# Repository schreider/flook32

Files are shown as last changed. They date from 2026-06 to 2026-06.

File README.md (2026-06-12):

<p align="center">
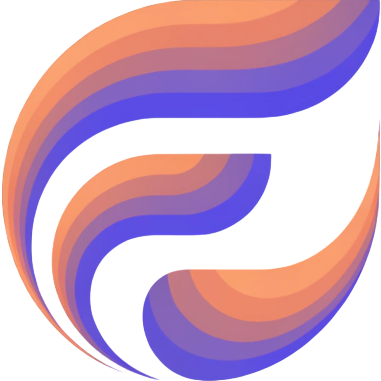
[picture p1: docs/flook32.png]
FLOOK32 logo
  
</p>

<p align="center">
  <a href="https://github.com/schreider/flook32/releases">
    
  </a>
  <br>
  <a href="https://www.espressif.com/en/products/socs/esp32">
    
  </a>
  <a href="https://github.com/schreider/flook32/blob/main/LICENSE">
    
  </a>
  <a href="https://t.me/flook32">
    
  <br>
  </a>
</p>

# FLOOK32 — контроллер нагрева камеры 3D-принтера

Автономный контроллер с возможностью мягкой интеграции в Klipper на базе ESP32 с веб-интерфейсом. Управляет нагревом камеры, вентилятором обдува, следит за температурой и защищает от перегрева.

[Telegram-чат проекта](https://t.me/flook32)

> ⚠️ **БЕТА-версия 0.1.0.** Проект активно дорабатывается. Прошивка протестирована на одной среде — возможны баги. Если нашли проблему — создайте [Issue](https://github.com/schreider/flook32/issues/new) или напишите в [Telegram](https://t.me/flook32)
>
> **ВНИМАНИЕ:** Устройство работает с напряжением 220В. Неправильная сборка может привести к пожару или поражению током. Автор не несёт ответственности за любой ущерб.

---

<p align="center">
  
  
  
  
  
</p>

## 📋 Быстрая навигация

| Раздел | Описание |
|---|---|
| [Зачем это нужно](#зачем-это-нужно) | Мотивация и философия проекта |
| [Гибкость настроек](#гибкость-настроек) | Полный контроль без кода |
| [Возможности](#возможности) | Прошивка, железо, печатные детали |
| [Поддержать автора](#-поддержать-автора) | Донаты на развитие проекта |
| [Лицензия](#лицензия) | GPLv3 License |
| [Атрибуция](#-атрибуция-сторонних-библиотек) | Используемые сторонние библиотеки |

### 📖 Документация

| Документ | Содержание |
|---|---|
| [BUILD.md](docs/BUILD.md) | 🛠️ Инструкция по сборке устройства |
| [SETUP.md](docs/SETUP.md) | 📥 Прошивка и первый запуск |
| [FIRMWARE.md](docs/FIRMWARE.md) | ⚙️ Документация по прошивке ESP32 |
| [ESP01S_FIRMWARE.md](firmware/esp01s_watchdog/ESP01S_FIRMWARE.md) | 🐶 Прошивка ESP-01S (watchdog) |
| [WEBUI.md](docs/WEBUI.md) | 🌐 Работа с веб-интерфейсом |
| [WIRING.md](docs/WIRING.md) | 🔌 Схема подключения |
| [BOM.md](docs/BOM.md) | 📦 Список компонентов |
| [KLIPPER.md](docs/KLIPPER.md) | 🖨️ Интеграция с Klipper/Moonraker |
| [FAQ.md](docs/FAQ.md) | ❓ Частые вопросы |
| [WARNING.md](docs/WARNING.md) | ⚠️ Предупреждение о безопасности |

### 🗂️ Структура репозитория

| Папка | Содержание |
|---|---|
| [`firmware/flook32/`](firmware/flook32/) | Прошивка ESP32 |
| [`firmware/esp01s/`](firmware/esp01s_watchdog/) | Прошивка ESP-01S (watchdog) |
| [`klipper/`](klipper/) | Плагин для Klipper |
| [`hardware/enclosure/`](hardware/enclosure/) | 3MF, STEP, F3D файлы корпусов |
| [`tools/`](tools/) | Вспомогательные скрипты |
| [`docs/`](docs/) | Документация |

---

## Зачем это нужно

Большинство 3D-принтеров на рынке не имеют нагрева камеры в принципе. А проприетарные платы производителей чаще всего либо не имеют возможности подключения нагревателя, либо не имеют выходов под датчики, необходимые для нормальной защиты нагревателя.

В интернете есть похожие проекты, но у каждого — свой недостаток:
- Нет нужного функционала защит (просто вкл/выкл по температуре воздуха в камере)
- Построены на проприетарных платах — нельзя модифицировать или починить без сложной пайки
- Требуют глубокого вмешательства в Klipper для интеграции
- Подключаются как второе MCU с вытекающими проблемами

Поэтому я создал проект под собственные требования:
- **Удобство** — всё управляется из браузера с телефона или ПК
- **Безопасность** — 7+ уровней защиты, аппаратный watchdog, двойное реле на нагревателе
- **Модульность** — все компоненты куплены на маркетплейсах, любой заменяется без пайки за минуты
- **Универсальность** — установка в ЛЮБОЙ принтер, даже без Klipper
- **Автономность** — самостоятельный блок, который не зависит от прошивки принтера. Работает без Klipper, без USB, без интернета — просто включил в розетку, настроил через Wi-Fi и забыл
- **Широкий диапазон** — поддержка любых нагревателей с измерением температуры от 0 до 600°C

### Интеграция без привязки к принтеру

Модуль `flook32.py` делает интеграцию с Klipper тривиальной — скопировали плагин, добавили три строки в `printer.cfg`, и всё работает. Сменили принтер на новый — перенесли внутренний и внешний блоки, нагреватель камеры снова в строю.

Более того — **Klipper не обязателен**. Контроллер полностью автономен: открыли веб-интерфейс, выставили температуру, нагрев пошёл.

### Защита на стороне контроллера, а не принтера

Все защиты реализованы исключительно на стороне FLOOK32. Klipper **никогда не упадёт в ошибку** из-за проблем с нагревом камеры и **не прервёт печать**.

А FLOOK32 в это время сам пытается восстановить систему. Сработала защита? Контроллер подождёт, проверит, и если ошибка ушла — продолжит нагрев. И только если ситуация не исправляется — отключит нагрев с полной блокировкой и будет ждать действий оператора. Вы спокойно допечатаете модель, даже если нагреватель временно отключился по защите.

[🔝 Наверх](#-быстрая-навигация)

---

## Гибкость настроек

FLOOK32 не пытается угадать, какой у вас принтер, камера, вентилятор или нагреватель. Он даёт вам **полный контроль** над всем — и делает это через удобный веб-интерфейс, без единой строчки кода.

### Всё настраивается «на лету»

- **Пины** — можно назначить любые GPIO под SSR, вентилятор, датчики. Поменяли номера пинов в вебморде — и всё работает.
- **Логика сигналов** — если ваше реле включается низким уровнем, а не высоким, просто включите инверсию нагревателя (и вентилятора) в одно нажатие.
- **Температурные пороги** — максимальная температура нагревателя, критический перегрев, гистерезисы, максимальная температура воздуха в камере — всё задаётся под ваше железо и ваши требования к безопасности.
- **Вентилятор** — настраивается порог включения, минимальное время работы, максимальная мощность ШИМ.

### Автоматическая адаптация (но можно и вручную)

Чтобы не гадать с порогами защит и работой вентилятора, запустите адаптацию. Контроллер сам:
- измерит реальную скорость нагрева вашего нагревателя и камеры,
- определит уровень шумов датчиков,
- подберёт эффективную мощность вентилятора и температуру его включения,
- выставит оптимальные пороги для Thermal Runaway и других защит.

Но если вы любите точную ручную настройку — все параметры доступны для редактирования, и адаптация не обязательна.

### Система защит настраивается под ваш принтер

- **Thermal Runaway**: можно задать длительность фаз, минимальные скорости роста температуры, время восстановления после срабатывания.
- **Неожиданный нагрев**: настраивается порог, таймаут ожидания остывания, гистерезис.
- **Блокировка**: сколько одинаковых ошибок нужно, чтобы система заблокировалась, и в течение какого окна.
- **Термальная модель**: включается по желанию, имеет регулируемую чувствительность, и сама учится на поведении вашего принтера.

### Никакой «магии» — всё прозрачно

Все текущие настройки в любой момент можно посмотреть в браузере, а новые сохраняются в энергонезависимую память.

FLOOK32 не навязывает единственно верное поведение — он **настраивается под вас**.

[🔝 Наверх](#-быстрая-навигация)

---

## Возможности

### Прошивка

- **Самообучаемая термальная модель** — предсказывает температуру и находит аномалии
- **Автоадаптация** — сам подбирает параметры под конкретный принтер
- **7+ уровней защиты** с трёхступенчатой эскалацией
- **Веб-интерфейс** с графиком в реальном времени ([подробнее](docs/WEBUI.md))
- **Интеграция с Klipper и Moonraker** — UDP-обнаружение, автоотключение после печати
- **WebSocket + REST API** (32 эндпоинта) ([подробнее](docs/FIRMWARE.md))
- **OTA-обновление** — три способа: ручная загрузка `.bin`, автообновление через GitHub

### Железо

- Управление нагревателем через SSR
- ШИМ-управление вентилятором (17 кГц, ультразвук)
- MAX6675 + термопара K-типа и DS18B20
- Аппаратный watchdog на ESP01S
- LED-индикация (10 режимов + анимации) ([подробнее](docs/FIRMWARE.md))
- Звуковая индикация (3 мелодии) ([подробнее](docs/FIRMWARE.md))

### 🖨️ Печатные детали

> ℹ️ **Гибкость монтажа** — предоставленные модели корпусов — **не обязательны**. Вы можете:
> - Разместить всю электронику в отсеке электроники вашего принтера (если позволяет место)
> - Использовать собственные корпуса (своей разработки или с Printables/Thingiverse)
> - Модуль нагревателя — любой доступный в открытых источниках, под любой формат и мощность
> - Вентилятор — 5/12/24В в зависимости от места установки и потребностей (можно использовать БП принтера)
>
> Цель проекта — дать **полный контроль**, а не навязывать единственное решение.

#### Внешний блок (основной контроллер)

- **Два изолированных отсека** — низковольтный (5В/12В) и высоковольтный (220В)
- **Поддержка двух типов SSR** — G3MB-202P или SSR-10DA
- **Доступ к ESP32** — Type-C, BOOT, EN снаружи
- **Кабельный ввод под гофру**
- **4 винта** — вскрывается за минуту
- **Магнитное крепление** — сзади

#### Внутренний блок (в камеру принтера)

- **Узкая конструкция** — не мешает механике
- **PTC нагреватель 150Вт**
- **Магнитное крепление** — сверху
- **Встроенный коннектор XH 2.54** — замена вентилятора за минуту
- **Подсветка логотипа**
- **Кабельный ввод под гофру**

[🔝 Наверх](#-быстрая-навигация)

---

## 💖 Поддержать автора

Если проект оказался полезным, вы можете поддержать разработку:

| Платформа | Адрес |
|---|---|
| [DonationAlerts](https://dalink.to/schreid) | RUB, карты, СБП |
| **BTC** (Bitcoin) | `19zn9549pTmBEDFddg7uUS8iiwPJVgAUC1` |
| **USDT** (TRC20) | `TPhKy6vCPUGbmDUak1QhCgY5bEsSczLhmK` |
| **ETH** (Ethereum) | `0xeFDa4681B0eFfBE1f43c9c59A47D1Bbe8aEA5f44` |
| **TON** | `UQA9LVMtu6e4sMJ8cLHaVvGIj1CvFL2vdDTk_blglwtII6Zf` |

> 💡 Все донаты идут на закупку компонентов для тестирования, новые платы, содержание проекта, добавление новых функций, разработку LITE-версии FLOOK32 и сушилки филамента.

### 🛒 Готовые комплекты

Я продаю готовые комплекты FLOOK32 — прошитые и проверенные. Вам останется только подключить по схеме и настроить Wi-Fi. Это лучший способ поддержки ❤️

<p align="center">
  <a href="https://t.me/schreid">
    
  </a>
</p>

---

## Лицензия

GNU General Public License v3.0 (GPLv3)

Copyright (C) 2026 t.me/schreid

Этот проект распространяется под лицензией GPLv3. Вы можете свободно:
- Использовать прошивку в любых целях
- Модифицировать исходный код
- Распространять оригинал и модифицированные версии

При условии:
- Сохранения указания авторства
- Публикации производных работ под той же лицензией (GPLv3)
- Предоставления доступа к исходному коду производных работ

Полный текст лицензии: https://www.gnu.org/licenses/gpl-3.0.html

---

## 📜 Атрибуция сторонних библиотек

Проект FLOOK32 использует следующие сторонние компоненты. Я выражаю благодарность их авторам.

- **ESP-IDF** — [Apache License 2.0](https://github.com/espressif/esp-idf/blob/master/LICENSE) (c) Espressif Systems
- **ArduinoJson** — [MIT License](https://github.com/bblanchon/ArduinoJson/blob/master/LICENSE.txt) (c) Benoit Blanchon
- **Adafruit_NeoPixel** — [LGPLv3 License](https://github.com/adafruit/Adafruit_NeoPixel/blob/master/COPYING) (c) Adafruit Industries
- **AsyncTCP** & **ESPAsyncWebServer** — [LGPLv3 License](https://github.com/me-no-dev/AsyncTCP/blob/master/LICENSE) (c) dvarrel, me-no-dev
- **DallasTemperature** & **OneWire** — [MIT License](https://github.com/milesburton/Arduino-Temperature-Control-Library/blob/master/LICENSE) (c) Miles Burton, Tim Eckel, Guillermo Lovato
- **Chart.js** & **date-fns** — [MIT License](https://github.com/chartjs/Chart.js/blob/master/LICENSE.md) (c) Chart.js Contributors, Sasha Koss, Lesha Koss

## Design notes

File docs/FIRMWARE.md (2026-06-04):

[🔙 На главную](../README.md)

# 🔥 Прошивка FLOOK32

**Файл:** `firmware/flook32/src/flook32.ino`  
**Платформа:** ESP32 (и совместимые модули)  
**Среда разработки:** Arduino IDE  
**Размер:** ~10000 строк (C++)  
**Зависимости:** ArduinoJson, AsyncTCP, ESPAsyncWebServer, DallasTemperature, OneWire, Adafruit_NeoPixel

Подробное техническое описание прошивки ESP32 для контроллера нагрева камеры.

---

## Содержание

1. [Общая информация](#1-общая-информация)
2. [Аппаратная часть](#2-аппаратная-часть)
3. [Структура прошивки](#3-структура-прошивки-setup--loop)
4. [Датчики](#4-датчики)
5. [Управление SSR](#5-управление-ssr-нагреватель)
6. [Управление вентилятором](#6-управление-вентилятором-pwm)
7. [Система защит](#7-система-защит)
8. [Термальная модель](#8-термальная-модель-машинное-обучение)
9. [Адаптация](#9-адаптация-самонастройка)
10. [Система ошибок и журналирования](#10-система-ошибок-и-журналирования)
11. [История для графика](#11-история-для-графика-trends)
12. [LED индикация](#12-led-индикация-neopixel-ws2812b)
13. [Звуковая индикация](#13-звуковая-индикация-зуммер)
14. [Watchdog](#14-watchdog)
15. [Интеграция с Klipper/Moonraker](#15-интеграция-с-klippermoonraker)
16. [Ручной таймер](#16-ручной-таймер)
17. [Кнопка сброса](#17-кнопка-сброса)
18. [Автоперезагрузка](#18-автоперезагрузка-по-бездействию)
19. [Конфигурация](#19-конфигурация)
20. [OTA обновление](#20-ota-обновление)
21. [Веб-сервер](#21-веб-сервер)
22. [Система логирования](#22-система-логирования)
23. [Мьютексы](#23-мьютексы-и-критические-секции)
- [Приложение A: Значения по умолчанию](#приложение-a-значения-по-умолчанию)
- [Приложение Б: Диаграмма состояний](#приложение-б-диаграмма-состояний)
- [Приложение В: Глоссарий](#приложение-в-глоссарий)

---

## 1. Общая информация

#### ⚙️ Ключевые возможности

- Поддержание заданной температуры в камере
- Два независимых датчика температуры:
  - MAX6675 (термопара)
  - DS18B20 (воздух)
- ШИМ-управление вентилятором с автоограничением мощности
- Обучаемая термальная модель:
  - прогноз нагрева
  - прогноз охлаждения
  - раннее обнаружение аномалий
- Многоуровневая защита:
  - перегрев
  - thermal runaway
  - неожиданный нагрев
- Аппаратный watchdog (ESP-01S) для отключения 220В
- Адаптивная самонастройка под камеру и вентиляцию
- Web-интерфейс (SPA) с real-time графиком
- WebSocket + HTTP REST API
- OTA обновление прошивки
- Обнаружение Klipper / Moonraker (UDP)
- LED-индикация состояний
- Звуковая сигнализация ошибок

#### 🎯 Целевая платформа

- ESP32 (рекомендуется ESP-32D DevKit C V4)
- Flash: минимум 4MB

#### Зависимости (библиотеки)

| Библиотека | Автор | Назначение |
|---|---|---|
| [Adafruit NeoPixel](https://github.com/adafruit/Adafruit_NeoPixel) | Adafruit | LED лента WS2812B |
| [OneWire](https://www.pjrc.com/teensy/td_libs_OneWire.html) | Jim Studt, Tom Polland, Robin James | Шина для DS18B20 |
| [DallasTemperature](https://github.com/milesburton/Arduino-Temperature-Control-Library) | Miles Burton | Датчик DS18B20 |
| [ArduinoJson](https://arduinojson.org/) | Benoit Blanchon | Парсинг JSON |
| [ESPAsyncWebServer](https://github.com/ESP32Async/ESPAsyncWebServer) | ESP32Async | Веб-сервер |
| [AsyncTCP](https://github.com/ESP32Async/AsyncTCP) | ESP32Async | Асинхронный TCP |

#### Файловая структура

```
firmware/flook32/
├── flook32.ino                         // ВСЯ прошивка (~10000+ строк)
├── index_html_gz.h                     // Сжатый gzip веб-интерфейса
├── favicon_ico.h                       // Иконка для вкладок браузера (48×48)
├── icon_192_png_gz.h                   // Иконка для домашнего экрана смартфонов (192×192)
├── chart_min_js_gz.h                   // Сжатая gzip библиотека Chart.js
├── chartjs_adapter_gz.h                // Сжатый gzip адаптер date-fns для Chart.js
├── compress_webui.bat                  // Скрипт сборки (Windows)
├── compress_webui.sh                   // Скрипт сборки (Linux/macOS)
└── src/                                // Исходники веб-ресурсов
    ├── index.html                      // Исходный HTML
    ├── favicon.ico                     // Исходная иконка браузера
    └── icon_192.png                    // Исходная иконка для смартфонов
```

---

## 2. Аппаратная часть

#### Таблица GPIO пинов

| Пин | Назначение | Направление | Подтяжка | Примечание |
|---|---|---|---|---|
| GPIO32  | SSR нагреватель | OUTPUT | — | HIGH = вкл (если не инвертирован) |
| GPIO33  | Вентилятор PWM | OUTPUT | — | 0–1023, частота 17 kHz |
| GPIO26  | Watchdog heartbeat | OUTPUT | — | Импульс на ESP-01S |
| GPIO21  | DS18B20 (1-Wire) | INPUT | Встроена в модуль 4.7k | — |
| GPIO18  | MAX6675 SCK | OUTPUT | — | SPI |
| GPIO19  | MAX6675 SO (MISO) | INPUT | — | SPI |
| GPIO5 | MAX6675 CS | OUTPUT | — | SPI (Chip Select) |
| GPIO25  | Бипер | OUTPUT | — | Активный/пассивный |
| GPIO27  | LED лента WS2812B | OUTPUT | — | NeoPixel data |
| GPIO17  | Кнопка сброса | INPUT | INPUT_PULLUP | Удержание 5 сек = сброс к заводским |

#### Особенности работы модуля MAX6675 (термопара K-типа)

- Разрешение: 0.25°C
- Диапазон: 0–1024°C
- Обновление: ~70 мс на чтение

---

#### Особенности работы модуля DS18B20 (датчик воздуха)

- Интерфейс 1-Wire
- Диапазон: -55 до +125°C
- Обновление: 200 мс (9 бит)

#### Особенности работы модуля SSR (твердотельное реле)

- Инверсия сигнала настраивается в конфиге (LOW/HIGH)

#### Особенности работы MOSFET модуля (PWM)

- Частота ШИМ: 17 kHz (неслышимый диапазон)
- Разрешение: 0–1023 (10 бит)
- Нелинейная зависимость мощности
- Сырой duty для регулировки

#### Особенности работы LED (WS2812B)

- Количество светодиодов настраивается (1–100)

#### Особенности работы бипера

- Активный бипер: управление HIGH/LOW

#### Принцип работы внешнего watchdog (ESP-01S)

- ESP32 отправляет импульс каждые (pulseMs + pauseMs) мс
- ESP-01S мониторит GPIO2
- Если импульсы пропали > 6 секунд → реле размыкается → 220V отключается
- Это аппаратная защита, не зависит от софта основной ESP32

---

## 3. Структура прошивки (setup + loop)

### 3.1 setup() — полная последовательность

```
1. Serial.begin(115200)
   └─ Вывод версии, причины перезагрузки
   └─ Логирование причины перезагрузки в журнал ошибок:
       ├─ Аварийные причины (пан́ика, watchdog, brownout) → addErrorToLog()
       └─ Штатные (включение питания, софт-ресет) → не логируются
   └─ Проверка свободного места в NVS (nvs_get_stats)
       └─ Если свободно <10% → предупреждение в журнал ошибок

2. Preferences (NVS)
   └─ Генерация/загрузка уникального device_id
   └─ Проверка целостности конфига (размер sizeof(Config))

3. loadConfig()
   └─ Загрузка из Preferences (NVS)
   └─ loadDutyTable()
   └─ Валидация (config.validate())

4. Инициализация пинов
   └─ pinMode для SSR, Watchdog, 1-Wire, MAX6675 (SCK/SO/CS), бипер, LED

5. Инициализация периферии
   ├─ initFanPWM() — настройка ШИМ
   ├─ initButton() — кнопка на GPIO17 (INPUT_PULLUP)
   ├─ OneWire + DallasTemperature
   ├─ digitalWrite SSR = инвертированный LOW
   ├─ digitalWrite Watchdog = HIGH
   └─ digitalWrite Buzzer = LOW

6. Система ошибок
   └─ errors.loadLockState() — восстановление блокировки

7. Датчики
   ├─ DS18B20
   │   ├─ begin()
   │   ├─ setResolution(9 бит)
   │   ├─ setWaitForConversion(false)
   │   ├─ Проверка наличия устройств
   │   └─ Пробное чтение (задержка 1 сек)
   └─ MAX6675
       └─ initMAX6675() — проверка доступности

8. Термальная модель
   └─ initThermalModel()
       └─ Если enableThermalModel → updateProtectionsForThermalModel()

9. Wi-Fi
   ├─ Если есть сохранённые учётные данные:
   │   ├─ WiFi.mode(WIFI_STA)
   │   ├─ WiFi.begin(ssid, password)
   │   └─ 20 попыток по 500 мс = 10 сек таймаут
   │       ├─ Успех → wifiConnected = true
   │       └─ Неудача → сброс учётных данных, переход в AP
   └─ AP режим:
       ├─ SSID = "FLOOK32-" + MAC (последние 4 байта)
       ├─ Пароль = "flook1234"
       └─ IP = 192.168.4.1

10. UDP
    └─ udp.begin(UDP_PORT)
    └─ Для Klipper/Moonraker обнаружения

11. WebSocket + HTTP сервер
    ├─ CORS заголовки
    ├─ ws.onEvent(onWebSocketEvent)
    ├─ favicon.ico (из PROGMEM, gzip)
    ├─ / → index.html (чанкированный gzip из PROGMEM)
    ├─ ETag кэширование ("v1")
    ├─ API маршруты (30+ эндпоинтов)
    ├─ /api/duty-table (GET + add)
    ├─ /api/device-id
    ├─ /api/thermal-status
    ├─ /api/config POST (полный парсинг JSON + валидация + saveConfig)
    ├─ /api/update OTA (запись во flash + перезагрузка)
    └─ 404 обработчик

12. FreeRTOS задачи
    ├─ SensorTask: ядро 1, приоритет 8, стек 4KB
    ├─ ControlTask: ядро 1, приоритет 10, стек 12KB (основной цикл управления)
    ├─ WebTask: ядро 0, приоритет 7, стек 16KB (метрики, WebSocket, история)
    ├─ HeartbeatTask: ядро 1, приоритет 5, стек 1KB (импульс watchdog)
    └─ LEDTask: ядро 0, приоритет 2, стек 2KB (индикация)

13. Watchdog
    └─ esp_task_wdt_add(controlTaskHandle)
    └─ Таймаут = config.loopWatchdogTimeout

14. Финальные действия
    ├─ Проверка флага автоперезагрузки (Preferences)
    ├─ Мелодия запуска (если не системная блокировка)
    └─ resetActivityTimer() — таймер бездействия
```
### 3.2 loop()

```
loop() — `vTaskDelay(portMAX_DELAY)`
Бесконечное ожидание — вся логика выполняется в задачах FreeRTOS.
После завершения инициализации:
setup()
│
└── vTaskDelete(NULL)
```

Основная причина:
- Параллельное выполнение:
  - контроль температуры
  - WebSocket
  - защита
  - PWM
  - watchdog
  - адаптация

### 3.3 Приоритеты FreeRTOS задач

| Задача | Ядро | Приоритет | Стек  | Назначение |
|---|---|---|---|---|
| SensorTask | 1 | 8 | 4KB | Чтение датчиков |
| ControlTask | 1 | 10 | 12KB  | Управление нагревом, защиты, адаптация |
| WebTask | 0 | 9 | 16KB  | WebSocket, HTTP, метрики, история |
| HeartbeatTask | 1 | 5 | 1KB | Импульс на watchdog |
| LEDTask | 0 | 2 | 2KB | LED индикация |

### 3.4 Конфигурация (Preferences / NVS)

Хранение: Preferences (NVS — Non-Volatile Storage)

Пространства имён:

| Namespace | Назначение |
|---|---|
| `"flook"` | Конфиг, Wi-Fi, lastTarget, статус блокировки |
| `"dutyTable"` | Таблица T_возд → duty вентилятора |
| `"thermal"` | Коэффициенты термальной модели |

#### Ключи:

- "device_id" — уникальный идентификатор устройства  
- "device_id_created" — время создания  
- "config" — сериализованная структура Config (с проверкой sizeof)  
- PREF_AUTO_REBOOT_FLAG — флаг автоперезагрузки

### 3.5 HTTP сервер

Библиотека: ESPAsyncWebServer

Порт: 80

CORS: разрешены все источники

Сжатие: gzip для index.html (из PROGMEM)

Кэширование: ETag "v1", Cache-Control: max-age=86400

---

## 4. Датчики

### 4.1 MAX6675 (термопара K-типа)

Интерфейс: программный SPI

- SCK = config.pinMaxSck (GPIO18)
- SO  = config.pinMaxSo (GPIO19)
- CS  = config.pinMaxCs (GPIO5)

#### Алгоритм чтения (readMAX6675)

```
- Чтение 16 бит через SPI (битовый сдвиг)
- Проверка служебных битов MAX6675:
  - D2 = 0 → нормальное значение
  - D1 = fault (обрыв термопары)
- Извлечение температуры:
  - `(value >> 3) * 0.25°C`
- Проверка валидности значения:
  - диапазон `minTemp..maxTemp`
- Фильтрация скачков:
  - если `|T - T_prev| > config.max6675TempJumpThreshold` → игнор / ошибка
- Усреднение:
  - `config.max6675StabilitySamples` (скользящее окно)
```
#### Защита MAX6675

- Проверка диапазона: `minTemp..maxTemp`
- Проверка скачков: порог `config.max6675TempJumpThreshold`
- Сэмплы стабильности: `config.max6675StabilitySamples`
- При выходе за диапазон или скачке → ошибка `max6675Error`

#### Частота опроса

- Выполняется в `SensorTask`
- Интервал: `config.readInterval` (по умолчанию 1000 мс)

### 4.2 DS18B20 (датчик воздуха)

**Интерфейс:** 1-Wire (библиотеки OneWire + DallasTemperature)

DATA = config.pinOneWire (GPIO21)

**Разрешение:** 9 бит (0.5°C)  
**Установка:** `ds18b20->setResolution(9)`  

**Обоснование:** минимальная задержка конвертации (~94 мс)

**Метод опроса:** асинхронный — `requestTemperatures()` → `vTaskDelay(100ms)` → `getTempCByIndex(0)`

#### Алгоритм чтения (readDS18B20Temperature)

```
1. ds18b20->requestTemperatures()
2. Ожидание: while (!ds18b20->isConversionComplete()) delay(10)
3. tempC = ds18b20->getTempCByIndex(0)
4. Проверка на DEVICE_DISCONNECTED_C (-127°C)
   └─ Если да → возврат DEVICE_DISCONNECTED_C, ds18b20Error = true
5. Применение калибровки:
   └─ Если config.ds18b20CalEnabled:
       result = tempC * config.ds18b20Scale + config.ds18b20Offset
   └─ Иначе: result = tempC
6. Сохранение ds18b20LastValidTemp
```
#### Защита DS18B20

- Проверка диапазона: `minTemp..maxTemp`
- Проверка скачков: порог `config.airSensorTempJumpThreshold`

#### Анализ нестабильности

- Окно анализа: `config.airSensorUnstableWindow` отсчётов  
- Допустимый размах: `config.airSensorUnstableRange`  
- Допустимое отклонение: `config.airSensorUnstableDeviation`  
- Допустимые смены направления: `config.airSensorDirectionChanges`  
- Сэмплы стабильности: `config.airSensorStabilitySamples`

#### Частота опроса

- Выполняется в `SensorTask`  
- Интервал: `config.readInterval`

---

## 5. Управление SSR (нагреватель)

### 5.1 Принцип работы

Дискретный выход (HIGH/LOW) с программным гистерезисом.

Пин: `config.pinSsr` (GPIO32 по умолчанию)

Инверсия: `config.invertHeaterSignal`

- false → HIGH = вкл, LOW = выкл  
- true → LOW = вкл, HIGH = выкл  

### 5.2 Два режима управления

#### Режим 1: По воздуху (`enableHeaterHysteresis = false`)

```
ВКЛ:  airTemp ≤ targetTemp - hysteresis
ВЫКЛ: airTemp ≥ targetTemp + hysteresis
```
#### Режим 2: По воздуху и нагревателю (`enableHeaterHysteresis = true`)

```
ВКЛ:  airTemp ≤ targetTemp - hysteresis
      И heaterTemp < maxHeaterTemp - heaterHysteresis
ВЫКЛ: heaterTemp ≥ maxHeaterTemp + heaterHysteresis
      ИЛИ airTemp ≥ targetTemp + hysteresis
```

### 5.3 Принудительное отключение

Нагреватель выключается при:

- `targetTemp == 0`
- Критической ошибке (`errors.hasCriticalError()`)
- `runawayTriggered == true`
- `criticalOverheatLock == true`
- `airOverheatLock == true`
- `errors.unexpectedHeat == true`
- `errors.isSystemLocked() == true`
- `heaterTemp >= config.criticalTemp`
- `airTemp >= config.maxAirTemp`
- Завершении печати по Moonraker (`shouldShutdownByPrintStatus()`)
- Срабатывании ручного таймера

### 5.4 Частота управления

Выполняется в `ControlTask`

Интервал: `config.heaterControlInterval` (по умолчанию 50 мс = 20 Гц)

---

## 6. Управление вентилятором (PWM)

### 6.1 Аппаратный ШИМ

Периферия: LEDC (LED Control)  
Пин: `config.pinFan` (GPIO33 по умолчанию)  
Частота: 17 кГц (неслышимый диапазон)  
Разрешение: 10 бит (0–1023)

```
ledc_timer_config_t ledc_timer = {
    .speed_mode = LEDC_LOW_SPEED_MODE,
    .duty_resolution = LEDC_TIMER_10_BIT,
    .timer_num = LEDC_TIMER_0,
    .freq_hz = DEFAULT_FAN_PWM_FREQ,  // 17000
    .clk_cfg = LEDC_AUTO_CLK
};
```
### 6.2 Логика включения/выключения

```
ВКЛ:  heaterTemp ≥ fanOnTemp (по умолчанию 55°C)
ВЫКЛ: heaterTemp ≤ fanOnTemp - fanOffHysteresis
      И отработал fanMinOnTime (мин. время работы, по умолчанию 30 сек)
```
### 6.3 Режимы управления мощностью

#### Без автоограничения (`enableFanAutoLimit = false`)

Вентилятор всегда работает на `maxFanDuty` при включении.

#### С автоограничением (`enableFanAutoLimit = true`)

После достижения `heaterTemp ≈ maxHeaterTemp` мощность динамически корректируется:

```
Если heaterTemp > maxHeaterTemp + fanAutoLimitHysteresis:
    duty += fanAutoLimitAdjustStep (увеличиваем охлаждение)
Если heaterTemp < maxHeaterTemp - fanAutoLimitHysteresis:
    duty -= fanAutoLimitAdjustStep (уменьшаем охлаждение)

Ограничения:
    duty = constrain(duty, fanAutoLimitMinDuty, 1023)
```
### 6.4 Стартовая мощность по таблице

При включении вентилятора используется `getStartupDutyByAirTemp(airTemp)` — линейная интерполяция по таблице `dutyTable`, заполненной при адаптации.

### 6.5 Аварийный режим (100%)

При критических ошибках вентилятор форсируется на 100% через updateFan() по флагам в isCriticalErrorActive(). После снятия ошибки restoreFanNormalMode() выключает вентилятор и сбрасывает флаги форсирования. Дальнейшее управление передаётся updateFan(), который сам решит, нужно ли включать вентилятор по текущей температуре.

### 6.6 Частота управления

Выполняется в `ControlTask`

Интервал: `config.fanControlInterval` (по умолчанию 1000 мс)

---

## 7. Система защит

### 7.1 Общая архитектура

Все защиты работают в `ControlTask` независимо друг от друга. Приоритеты:

| Приоритет | Защита | Последствия |
|---|---|---|
| 1 (высший) | Система заблокирована | Всё отключено, требуется пароль |
| 2 | Критический перегрев нагревателя | SSR выкл, вентилятор 100% |
| 3 | Перегрев воздуха | SSR выкл, вентилятор 100% |
| 4 | Thermal Runaway | SSR выкл, опционально вентилятор |
| 5 | Неожиданный нагрев | SSR выкл, вентилятор 100% |
| 6 | Неэффективность вентилятора | Только предупреждение |
| 7 | Аномальный рост | Только предупреждение |

#### Трёхступенчатая эскалация

- Однократное срабатывание → остановка нагрева  
- Повторение в пределах `errorWindowMinutes` → счётчик++  
- Счётчик ≥ `maxErrorRetries` (3) → полная блокировка системы (требуется пароль)

### 7.2 Критический перегрев нагревателя

Функция: `checkHeaterOverheat()`  
Интервал: `config.controlInterval` (1000 мс)

#### Условие

```
heaterTemp > config.criticalTemp (по умолчанию 120°C)
```
#### Действия

- `errors.criticalOverheatCount++`
- `criticalOverheatLock = true`
- `errors.criticalOverheat = true`
- Выключение SSR

#### Сброс состояния

```
heaterTemp < criticalTemp - criticalHysteresis (120 - 5 = 115°C)
```
#### Блокировка системы

При:

```
criticalOverheatCount ≥ maxErrorRetries → `errors.lockSystem()`
```
### 7.3 Перегрев воздуха

Функция: `checkAirOverheat()`  
Интервал: `config.controlInterval` (1000 мс)

#### Условие

```
airTemp > config.maxAirTemp (по умолчанию 70°C)
```
#### Действия

- `errors.airOverheatCount++`
- `airOverheatLock = true`
- Выключение SSR

#### Сброс состояния

```
airTemp < maxAirTemp - airHysteresis (70 - 3 = 67°C)
```

### 7.4 Thermal Runaway (четырёхфазный контроль)

Функция: `checkThermalRunaway()`  
Интервал: `config.runawayCheckInterval` (5000 мс)

#### Условие запуска

```
targetTemp > 0 И heaterState == true И heaterTemp < targetTemp
```

#### Фаза 0 (первые 45 секунд)

```
Контроль: быстрая проверка нагревателя
Условие: heaterTemp < runawayQuickCheckTemp через 45 сек после включения
Действие: alarm — датчик отвалился от радиатора или нагреватель неисправен
```

#### Фаза 1 (0 – phase1Time минут)

```
Контроль: скорость нагрева НАГРЕВАТЕЛЯ
Условие: heaterTemp - startHeaterTemp < runawayMinHeaterRisePerMin × elapsedMin
Действие: alarm
```

#### Фаза 2 (phase1Time – phase2Time минут)

```
Контроль: скорость нагрева ВОЗДУХА
Условие: airTemp - startAirTemp < runawayMinAirRisePerMin × (elapsedMin - phase1Time)
Действие: alarm
```

#### Фаза 3 (> phase2Time минут)

```
Контроль: прогноз времени до цели
Условие: (targetTemp - airTemp) / currentRate > runawayMaxTimeToTarget
Действие: alarm
```

#### При срабатывании

- `errors.thermalRunawayCount++`
- `errors.thermalRunaway = true`
- `runawayTriggered = true`
- Выключение SSR
- Автосброс: через `runawayRecoveryTimeout` секунд

### 7.5 Неожиданный нагрев (Unexpected Heat)

Функция: `checkUnexpectedHeat()`  
Интервал: `config.unexpectedCheckInterval` (2000 мс)

#### Условие

```
!heaterState И fanState И heaterTemp > порог
```

---

#### Адаптивный порог

```
Базовый: maxHeaterTemp - unexpectedHeatThreshold
Адаптивный (если включён):
    порог = базовый - (airTemp - adaptiveBaseTemp) × adaptiveCoefficient
    ограничен: [maxHeaterTemp - adaptiveMinOffset, базовый]
```

#### Действия

- Ожидание `unexpectedHeatTimeout` секунд  
- Если `heaterTemp` не упала ниже ожидаемой → alarm  
- `errors.unexpectedHeatCount++`  

#### Сброс

```
heaterTemp < порог - unexpectedHeatHysteresis
```
### 7.6 Контроль эффективности вентилятора

Функция: `checkFanEfficiency()`  
Интервал: в составе `timerProtections` (1000 мс)

#### Условие

```
!heaterState И fanState И heaterTemp > maxAirTemp - 10
```

#### Проверка

Через `fanEfficiencyTimeout` секунд:

- падение температуры < `fanEfficiencyThreshold`

#### Действие

- Только предупреждение (не блокирует систему)

### 7.7 Контроль аномального роста

Функция: `checkHeatingRate()`  
Интервал: `config.rateCheckInterval` (1000 мс)

#### Условие

```
heaterState И скорость роста > abnormalRateThreshold (5°C/сек)
```
#### Действие

- Предупреждение в лог

### 7.8 Контроль датчика воздуха

Функция: `checkAirSensor()`  
Интервал: в составе `timerProtections` (1000 мс)

#### Анализ

- размах значений  
- отклонение  
- смены направления за `airSensorUnstableWindow` отсчётов  

#### При нестабильности

- `errors.airSensorUnstable = true`  
- предупреждение

---

## 8. Термальная модель (машинное обучение)

### 8.1 Принцип работы

Модель предсказывает температуру нагревателя на основе:

- текущей температуры  
- мощности нагревателя (0 или 1, релейное управление)  
- измеренной при адаптации скорости нагрева (`heaterRate`, °C/мин)

---

#### Формула предсказания

```
T_pred = T_current + (heaterRate / 60) × Δt × power × correction
```

---

#### Коррекция (correction)

Снижение скорости при приближении к целевой температуре:

- если разница < 10°C:

```
correction = разница / 10
```
- минимум:

```
correction = 0.3 (30% от номинальной скорости)
```

### 8.2 Обучение в реальном времени

Вызывается: `checkThermalModel()` каждые `thermalModelCheckInterval` (2000 мс)

---

#### Алгоритм

- Сравнивается предыдущее предсказание с реальной температурой  
- Вычисляется ошибка:

```
error = T_real - T_pred
```
- Если:

```
|error| > noiseFloor × 2
```
#### Обновление модели

- `heaterRate += error × 0.001` (градиентный шаг)
- `heaterRate = constrain(heaterRate, 1.0, 30.0)`
- Обновляется `noiseFloor` (экспоненциальное сглаживание)
- Корректируется `confidence` (растёт при стабильно малых ошибках)

#### Особенности

- Обучается только при активном нагреве (`heaterState == true`)
- `coolingRate` не обновляется онлайн (задаётся при адаптации)
- Автосохранение в Preferences раз в час

### 8.3 Обнаружение аномалий

Скользящее окно: 5 последних ошибок за 10 секунд

#### Пороги

**Предупреждение:**

```
avgError > noiseFloor × 3 × sensitivity
```
**Критическое:**

```
avgError > порог × 2.5
```
#### При критическом отклонении

- Выключение SSR  
- Запись в лог ошибок

### 8.4 Сохранение и загрузка

Хранение: Preferences, namespace "thermal"

#### Ключи

- `heaterRate`
- `coolingRate`
- `noiseFloor`
- `confidence`
- `samples`

#### Автосохранение

- раз в час  
- при каждом значимом обновлении  

#### Загрузка

- при старте, если модель включена  
- если данных нет — инициализация из адаптации

### 8.5 Влияние на другие защиты

При активной термальной модели (`protectionOverride.thermalModelActive = true`):

| Защита | Изменение |
|---|---|
| Thermal Runaway | Пороги смягчаются в 2 раза (модель обнаруживает аномалии раньше) |
| Unexpected Heat | Отключается |
| Контроль скорости воздуха | Включается дополнительная проверка `checkAirHeatingRate()` |

---

## 9. Адаптация (самонастройка)

### 9.1 Цель

Измерить тепловые характеристики конкретного принтера и рассчитать оптимальные пороги защит без ручного подбора.  
Занимает 15–40 минут.

### 9.2 Условия запуска

- Система не заблокирована  
- Датчики исправны  
- Температуры выровнены (разница < 4°C)  
- Обе температуры < 35°C  
- Целевая температура: 40–70°C  

### 9.3 Фазы

#### Фаза 0: Ожидание стабилизации

- Всё выключено  
- Ожидание выравнивания `T_нагр ≈ T_возд` (разница < 4°C)  
- Требование: обе температуры < 35°C и > 5°C  
- Проверка стабильности: 3 замера подряд с изменением < 0.5°C  

#### Фаза 1: Измерение шумов датчиков

- 30 секунд сбора показаний в покое  
- Расчёт σ (среднеквадратичного отклонения) для MAX6675 и DS18B20  

Результат:
- `heaterSensorNoiseLevel`
- `airSensorNoiseLevel`

#### Фаза 2: Измерение базовых параметров

- 10 секунд замера максимальных межвыборочных скачков  

Результат:
- `heaterSensorMaxJump`
- `airSensorMaxJump`

#### Фаза 3: Калибровка вентилятора (если `enableFanAutoLimit`)

- Поиск оптимальной мощности:
  - снижение `duty` от 1023 до минимального, удерживающего `maxHeaterTemp`  
- Результат:
  - `optimalPower`
  - `calibratedMinDuty`

- Поиск температуры включения:
  - тестирование порогов от 30°C с шагом 5°C  
- Результат:
  - `fanOnTemp`
  - `fanOffHysteresis`

#### Фаза 4: Нагрев с вентилятором

- Охлаждение до 35°C  
- Включение нагрева с вентилятором  

Измерение:
- средней скорости нагрева нагревателя  
- пиковой мгновенной скорости  
- скорости за первые 30 секунд  

- ожидание стабилизации (4°C допуск, 5 секунд)

#### Фаза 5: Ожидание пользователя

Таймаут: 30 минут  

Пользователь должен:
- опустить стол в нижнее положение  
- включить нагрев стола на 100–110°C  
- закрыть камеру  
- нажать «Продолжить» в веб-интерфейсе  

#### Фаза 6: Нагрев камеры

Самая длительная фаза

- нагрев воздуха до `adaptTargetTemp` (или таймаут 30 минут)

Измерение:
- `maxAirHeatingRate` — макс. скорость нагрева воздуха  
- `heatingRateAir` — средняя скорость  
- `timeToReachTarget` — время до цели  

Калибровка параметров автоограничения:
- перебор комбинаций: шаг × интервал × гистерезис × стабильность  
- выбор лучшей по минимальному размаху температуры  
- заполнение таблицы `duty (T_возд → мощность)`

После достижения цели:
- замер скорости охлаждения  

#### Фаза 7: Завершение

- расчёт и сохранение всех параметров  
- `finishAdaptation(true)`

#### Фаза 8: Ошибка

- завершение с `finishAdaptation(false)`

### 9.4 Применение результатов

#### Формулы расчёта порогов

| Параметр | Формула |
|---|---|
| runawayMinHeaterRisePerMin | heatingRateHeater × 0.4 |
| runawayMinAirRisePerMin | heatingRateAir × 0.4 |
| runawayMaxTimeToTarget | timeToTarget × 2.5 |
| max6675TempJumpThreshold | maxHeatingRate × 2.0 |
| abnormalRateThreshold | maxHeatingRate × 1.5 |
| hysteresis | airSensorNoiseLevel × 2 |
| minCoolingRate | coolingRate × 0.15 |

#### Сохранение

- `config.adaptationPerformed = true`
- `saveConfig()`

### 9.5 Прерывание

Кнопка «Прервать» в веб-интерфейсе

```
abortAdaptation()
```
Действия:
- выключение нагрева  
- сброс флагов

---

## 10. Система ошибок и журналирования

### 10.1 Структура Errors

Централизованная структура `errors` управляет всеми ошибками системы.

### Флаги ошибок

**Критические:**
- `criticalOverheat`
- `airOverheat`
- `thermalRunaway`
- `unexpectedHeat`

**Датчик нагревателя:**
- `max6675Disconnected`
- `max6675Noise`
- `max6675OutOfRange`
- `max6675Unstable`
- `max6675Stuck`

**Датчик воздуха:**
- `ds18b20Disconnected`
- `airSensorNoise`
- `airSensorOutOfRange`
- `airSensorUnstable`

**Системные:**
- `emergencyStop`
- `systemLocked`

#### Дополнительно

- флаги логирования (для предотвращения дублирования записей)
- счётчики повторов для каждого типа ошибки
- временные метки последних срабатываний

### 10.2 Блокировка системы

#### Условие

```
счётчик ошибок ≥ maxErrorRetries (3)
в пределах errorWindowMinutes (10 минут)
```
#### Действия

- `errors.lockSystem(reason, errorType)`
- сохранение в Preferences:
  - `systemLocked`
  - `lockReason`
  - `lockTime`
- выключение нагрева
- требуется пароль для разблокировки

#### Разблокировка

```
POST /api/unlock?password=XXX
```
#### После разблокировки

- сброс всех счётчиков  
- удаление сохранённого состояния блокировки  
- `errors.unlockSystem()`

### 10.3 Восстановление после ошибок

- Автосброс Thermal Runaway: через `runawayRecoveryTimeout` секунд  
- Автосброс Unexpected Heat: при охлаждении до безопасной температуры + `unexpectedHeatClearTime`  
- Автовосстановление MAX6675: при `max6675StabilitySamples` стабильных чтений подряд  

#### Проверка автоочистки

```
errors.checkAutoClear()
```

- вызывается каждые 5 секунд в WebTask

### 10.4 Журнал ошибок

Хранение: `std::vector<ErrorLogEntry>`  
Максимум: 20 записей (FIFO)

#### Структура записи

| Поле | Тип | Описание |
|---|-----|---|
| timestamp | uint32_t | время от запуска (мс) |
| message | string | текст ошибки |
| severity | string | critical / warning / info |
| trendData | snapshot | только для критических |
| errorCount | int | счётчик повторений |
| hash | uint32_t | DJB2-хеш сообщения |

#### Дедупликация

- одинаковые некритические ошибки: не чаще `minTimeBetweenSameErrors` (30 сек)
- уведомления: не чаще 30 секунд

#### Потокобезопасность

- `errorLogMux (portMUX)` при доступе из разных задач

### 10.5 Уведомления

Функция:
`addNotificationToLog(message)`

- только некритичные события  
- severity = `info`  
- без трендов  
- без звукового сигнала  

### 10.6 Очистка при низкой памяти

При:

```
freeHeap < 20KB или maxBlock < 20KB
```
Действия:

- журнал сокращается до 10 записей  
- кэш конфигурации сбрасывается  

---

## 11. История для графика (Trends)

### 11.1 Структура записи

Формат: `CompactTrendEntry` — 16 байт на точку

| Поле | Тип | Описание |
|---|-----|---|
| timestamp | uint32_t | время от запуска (мс) |
| airTemp | int16_t | T_воздух × 10 |
| heaterTemp | int16_t | T_нагревателя × 10 |
| targetTemp | int16_t | цель × 10 |
| predictedTemp | int16_t | модель × 10 |
| flags | uint8_t | SSR / вентилятор |

### 11.2 Кольцевой буфер

- размер: `TREND_BUFFER_SIZE = 600`
- память: 600 × 16 = 9600 байт (статическая)
- глубина: ~30 минут при `trendInterval = 3000 мс`

#### Индексация

- `trendIndex` — следующая ячейка
- `trendBufferFilled` — флаг полного заполнения

#### Потокобезопасность

- `trendBufferMux (portMUX)`

### 11.3 Запись

Функция:

```
addToTrendBuffer()
```
- интервал: `config.trendInterval` (3000 мс)
- выполняется в WebTask
- при активной модели добавляется `predictedTemp`

### 11.4 Отправка клиентам

- при подключении: `sendHistoryToClient()` (чанки по 60 точек)
- в реальном времени: WebSocket `history_update`
- по запросу:

```
sendUpdatesSince(timestamp)
```
→ только новые точки

---

## 12. LED индикация (NeoPixel WS2812B)

### 12.1 Аппаратная часть

Библиотека: Adafruit NeoPixel  
Пин: `config.pinLed` (GPIO27 по умолчанию)  
Количество: `config.ledCount` (1–100, по умолчанию 3)  
Яркость: `config.ledBrightness` (0–255, по умолчанию 50)  
Полное отключение: `config.ledEnabled = false`

Задача: `LEDTask`, ядро 0, приоритет 2, интервал 50 мс (20 Гц)

### 12.2 Режимы индикации

| Индекс | Режим | Цвет | Анимация | Условие |
|---|---|---|---|---|
| 0 | Выкл | — | — | LED отключены |
| 1 | Ожидание | Синий `{0, 80, 255}` | Дыхание (простая синусоида, 4 сек) | `targetTemp == 0` |
| 2 | Первый нагрев | Белый `{255, 255, 255}` | Прогресс-бар с градиентом яркости | `targetTemp > 0 && heaterState && !targetWasReached` |
| 3 | Поддержание | Зелёный `{0, 255, 80}` | Прогресс-бар с градиентом яркости | `targetWasReached == true` |
| 4 | Адаптация | Фиолетовый `{160, 0, 255}` | Прогресс-бар с градиентом яркости | `adaptationInProgress` |
| 5 | Ошибка | Красный `{255, 0, 0}` | Ровное мигание (300 мс) | Любая критическая ошибка или блокировка |

### 12.3 Приоритеты

Режимы выбираются по порядку (первый подходящий — побеждает):

1. Ошибка / блокировка системы
2. Адаптация
3. Первый нагрев до цели (белый)
4. Поддержание температуры (зелёный)
5. Ожидание (синий)

Особые случаи (выполняются до проверки приоритетов):
- **Удержание кнопки сброса** — оранжевый прогресс-бар, LED-индикация приостанавливается
- **Режим точки доступа Wi-Fi** — бегущий огонёк
- **Подключение к Wi-Fi** — зелёно-голубая волна (3 сек + затухание 0.5 сек)

### 12.4 Логика перехода белый → зелёный

```
Установка targetTemp > 0:
  targetWasReached = false
  └─ Белый прогресс-бар (первый нагрев)

Достижение цели:
  airTemp >= targetTemp - hysteresis
  └─ targetWasReached = true
  └─ Зелёный прогресс-бар (поддержание)

Сброс цели:
  targetTemp = 0
  └─ targetWasReached = false
  └─ Следующий нагрев снова белый
```

### 12.5 Зелёный прогресс-бар (поддержание)

Отображает положение температуры воздуха внутри диапазона `[targetTemp - hysteresis, targetTemp]`:

```
Прогресс = (airTemp - (targetTemp - hysteresis)) / hysteresis × 100%

Пример (цель 60°C, гистерезис 0.5°C):
  60.0°C → 100% (все LED горят)
  59.8°C → 60%  (3 из 5 LED)
  59.5°C → 0%   (все погасли, включается нагрев)
  59.5°C → нагрев вкл → прогресс растёт → 60.0°C → нагрев выкл → цикл повторяется
```

Полоска «дышит» в такт циклам нагрева: убывает при остывании, растёт при нагреве.

### 12.6 Типы анимаций

| Тип | Описание |
|-----|---|
| `LED_BREATH` | Простая синусоида яркости 15-100%. Период задаётся параметром |
| `LED_BLINK` | Ровное мигание вкл/выкл с заданным интервалом |
| `LED_PROGRESS` | Заполнение слева направо. Заполненная часть: градиент яркости от тусклого к яркому. Пустая часть: фон 10% яркости. Прогресс сглаживается с инерцией |
| `LED_RUNNING` | Одна яркая точка + затухающий хвост из 3 LED (1 → 0.5 → 0.33 → 0.25). Скорость задаётся параметром |

### 12.7 Особые режимы

#### Режим точки доступа (AP mode)
- Нет клиентов → оранжевый `{255, 150, 0}` бегущий огонёк, медленно (200 мс)
- Есть клиенты → зелёный `{0, 255, 100}` бегущий огонёк, быстро (80 мс)

#### Подключение к Wi-Fi (STA mode)
- Фаза 1 (3 сек): зелёно-голубая волна с гауссовым профилем, цвет плавно переходит зелёный → голубой
- Фаза 2 (0.5 сек): плавное затухание всех LED

#### Кнопка сброса (GPIO17)
При удержании кнопки LED-индикация приостанавливается. Отображается оранжевый прогресс-бар заполнения (5 сек до сброса). При достижении 5 секунд — тройная вспышка белым, сброс настроек, перезагрузка.

### 12.8 Плавные переходы

При смене режима цвет интерполируется в течение 400 мс через EaseInOutCubic: `currRGB → targetRGB`. Это создаёт эффект плавного «переливания» цвета.

---

## 13. Звуковая индикация (зуммер)

### 13.1 Аппаратная часть

Тип: активный зуммер (HIGH/LOW)  
Пин: `config.pinBuzzer` (GPIO25 по умолчанию)  
Управление: `webTask`, функция `updateBuzzer()`

### 13.2 Мелодии

| Индекс | Название | Описание |
|---|---|---|
| 0 | Короткий писк | 1 шаг, 150 мс |
| 1 | Двойной писк | 500 мс × 2, пауза 200 мс |
| 2 | Аларм | 7 писков по 800 мс |

Выбор: `config.buzzerMelody (0–2)`

### 13.3 Воспроизведение

Конечный автомат:

- используется `MelodyStep[]`
- без блокировки
- каждый шаг выполняется в `updateBuzzer()`

Запуск:

```
playMelody(melodyType, force)
```
### 13.4 Когда срабатывает

- критические ошибки — всегда (если `buzzerEnabled`)
- некритические — если `buzzerNonCriticalEnabled`
- система заблокирована — каждые 60 секунд (напоминание)
- запуск системы — короткий писк (если нет блокировки)

---

## 14. Watchdog

### 14.1 Внутренний (Task Watchdog)

Контролирует: `ControlTask`

- добавление: `esp_task_wdt_add(controlTaskHandle)`
- таймаут: `config.loopWatchdogTimeout` (30000 мс)
- сброс: `esp_task_wdt_reset()` в каждом цикле

При зависании → паника и перезагрузка ESP32

### 14.2 Внешний (ESP-01S)

Пин: `config.pinWatchdog` (GPIO26)

Сигнал:

```
heartbeatPulseMs (100 мс)
каждые heartbeatPulseMs + heartbeatPauseMs (1000 мс)
```

Задача: `HeartbeatTask`, ядро 1, приоритет 5

#### Условие генерации

- targetTemp > 0  
- нет критических ошибок  

#### Принцип работы

ESP-01S мониторит GPIO2:

- если импульсы пропали > 6 секунд  
→ реле размыкается  
→ отключение 220V

---

## 15. Интеграция с Klipper/Moonraker

### 15.1 UDP Discovery (обнаружение Klipper)

Порт: UDP_PORT (12345)  
Задача: WebTask, интервал 5000 мс  

Протокол: Klipper отправляет broadcast `"FLOOK_DISCOVERY"` → ESP32 отвечает:

FLOOK32:<IP>:<uptime>:<T_air>:<device_id_hex>

Ответ сохраняется:
`klipperStatus.update(remoteIP)` — IP, время, счётчик запросов

### 15.2 Обнаружение Moonraker

Условие:

```
klipperStatus.detected == true
```
#### Алгоритм

Перебор портов:
- 7125
- 7126
- 7130
- 4408
- 8000
- 8080
- 8899

Запрос:

```
GET http://<klipper_ip>:<port>/server/info
```
Поиск:
- `"moonraker"`
- `"klippy"`

#### Результат

При успехе:
- сохранение `moonrakerHost`
- сохранение `moonrakerPort`

#### Повтор

Если не найден:
- повтор каждые 5 минут

### 15.3 Статус печати

Функция: `fetchPrintStatus()`  
Интервал: 60000 мс (1 минута)

Эндпоинт:

```
GET /printer/objects/query?print_stats
```
#### Состояния

- `"printing"` — печать идёт  
- `"paused"` — пауза  
- `"standby"`, `"complete"`, `"error"` — завершено  

#### Детектирование завершения

```
"printing" → не "printing" и не "paused"
```
### 15.4 Автоотключение по завершению печати

#### Условия

- `config.autoShutdownEnabled == true`
- `printEndTime != 0`
- `(millis() - printEndTime) / 60000 ≥ config.autoShutdownMinutes`

#### Действия

- выключение SSR  
- `targetTemp = 0`  
- выключение вентилятора  
- лог уведомление  

#### Ошибки Moonraker

- счётчик: `moonrakerState.consecutiveErrors`
- при 3 ошибках:
  - сброс `moonrakerHost`
  - повторный поиск

---

## 16. Ручной таймер

### 16.1 Назначение

Отключение нагрева через заданное время независимо от печати и Moonraker.

API:

```
POST /api/manual-timer?enable=1&minutes=N
```
(N = 30–600)

#### 16.2 Логика

Проверка (ControlTask):

```
manualTimerActive && millis() >= manualTimerEndTime
```
#### Действия

- выключение SSR  
- `targetTemp = 0`  
- выключение вентилятора  
- сохранение `lastTarget = 0`  
- уведомление:
  - "⏰ Ручной таймер: нагрев отключён"

---

## 17. Кнопка сброса

### 17.1 Аппаратная часть

Пин: GPIO17  
Режим: INPUT_PULLUP (LOW = нажата)

### 17.2 Логика

- короткое нажатие (< 5 сек): игнорируется  

- удержание ≥ 5 сек:
  - LED: заполнение оранжевым  
  - тройная вспышка белым  
  - очистка Preferences:
    - "flook"
    - "dutyTable"
    - "thermal"
  - перезагрузка ESP32  

---

## 18. Автоперезагрузка по бездействию

### 18.1 Условия

- `targetTemp == 0`
- `heaterState == false`
- система не заблокирована
- бездействие ≥ `AUTO_REBOOT_TIMEOUT` (24 часа)

### 18.2 Процесс

- установка `PREF_AUTO_REBOOT_FLAG`
- перезагрузка ESP32

#### При старте

- если флаг установлен → мелодия не играет  
- сброс: любое действие пользователя → `resetActivityTimer()`

---

## 19. Конфигурация

### 19.1 Хранение

Метод: Preferences (NVS)  
Namespace: `"flook"`  
Ключ: `"config"` — бинарный дамп `Config` (sizeof проверка)

### 19.2 Дополнительные namespace

| Namespace | Назначение |
|---|---|
| "flook" | конфиг, Wi-Fi, lastTarget, статус блокировки |
| "dutyTable" | таблица T_возд → duty вентилятора |
| "thermal" | коэффициенты термальной модели |

### 19.3 Загрузка

- проверка `sizeof(Config)`
- несоответствие → сброс к заводским
- Wi-Fi восстанавливается отдельно
- валидация параметров в пределах

### 19.4 Сохранение

- `config.validate()`  
- бинарный дамп структуры  
- отдельное сохранение:
  - Wi-Fi
  - автоотключение
  - lastTarget

---

## 20. OTA обновление

### 20.1 Эндпоинты

| Метод | Endpoint | Описание |
|---|---|---|
| POST | `/api/update` | Ручная загрузка `.bin` файла через веб-интерфейс |
| GET | `/api/check-update` | Проверка наличия новой версии через `latest.json` на GitHub |
| POST | `/api/update-ota` | Автоматическое обновление — перезагрузка в режим OTA |

### 20.2 Ручное обновление (`/api/update`)

Принимает `.bin` файл через `multipart/form-data`.

**Процесс:**
- `Update.begin(maxSketchSpace)` — подготовка раздела
- `Update.write(data, len)` — запись чанков
- `Update.end(true)` — финализация

**Проверка ошибок:** `Update.hasError()`

**При успехе:** ответ `"UPDATE_SUCCESS"`, перезагрузка через 500 мс.

### 20.3 Проверка обновлений (`/api/check-update`)

Скачивает JSON-файл `latest.json` из репозитория GitHub, сравнивает версию прошивки с указанной в JSON.

**Расположение:** `firmware/flook32/latest.json`

**Формат `latest.json`:**
```json
{
  "version": "0.1.0",
  "ota_url": "https://raw.githubusercontent.com/.../flook32_ota.bin",
  "flash_url": "https://raw.githubusercontent.com/.../flook32_flash.bin",
  "notes": "Описание изменений",
  "force": false
}
```

**Поля:**
- `version` — версия прошивки (сравнивается с `FW_VERSION`)
- `ota_url` — прямая ссылка на `.bin` файл для автоматического обновления
- `flash_url` — прямая ссылка на `.bin` файл для прошивки по USB (используется скриптами)
- `notes` — описание изменений (отображается в веб-интерфейсе)
- `force` — принудительное обновление (`true` = предложить обновление независимо от версии)

**Логика:** обновление доступно если `version != FW_VERSION` ИЛИ `force == true`.

### 20.4 Автоматическое обновление (`/api/update-ota`)

1. Запрашивает `latest.json`, получает URL из поля `ota_url`
2. Сохраняет URL и флаг `ota_pending` в NVS
3. Перезагружает устройство
4. При старте (до инициализации Watchdog и задач FreeRTOS) проверяет флаг
5. Если флаг установлен — подключается к Wi-Fi, скачивает прошивку через `Update.writeStream()`, прошивается
6. Сбрасывает флаг и перезагружается с новой прошивкой

**Защита от зацикливания:** при 4 неудачных попытках OTA флаг автоматически сбрасывается.

### 20.5 Скрипты прошивки

Скрипты `flash_flook32.bat` (Windows) и `flash_flook32.sh` (Linux/macOS) автоматически получают последнюю версию и URL для скачивания из `latest.json` (поле `flash_url`).

### 20.6 Веб-интерфейс

На странице Настройки → OTA:
- **Загрузить файл вручную** — выбор `.bin` файла и отправка на `/api/update`
- **Проверить обновления** — запрос к `/api/check-update`, отображение версии и изменений
- **Обновить автоматически** — запуск `/api/update-ota`

### 20.7 Ограничения

- Максимальный размер: `ESP.getFreeSketchSpace()`
- Формат: `.bin`
- После обновления: автоматическая перезагрузка
- Для работы автообновления требуется доступ в интернет (режим STA)
- OTA выполняется до запуска Watchdog — безопасно для системы

---

## 21. Веб-сервер

### 21.1 Технологии

- HTTP: ESPAsyncWebServer (порт 80)  
- WebSocket: `/ws`  
- CORS: разрешены все источники  
- кэширование: `ETag "v1"`, `Cache-Control: max-age=3600`  

### 21.2 Отдача статики

- `index.html`:
  - Сжатый gzip из PROGMEM (`flook32_index_html_gz.h`)
  - Чанкированная передача (файл отдаётся клиенту по частям через `beginChunkedResponse`)
  - `Content-Encoding: gzip`
  - `Cache-Control: max-age=3600` (кешируется на 1 час)
  - `ETag: "v1"` — **меняйте на новую версию при каждом обновлении HTML** (например, `"v2"`, `"v3"`), чтобы браузеры загрузили обновлённый интерфейс

- `favicon.ico`:
  - Из PROGMEM (`favicon_ico.h`)
  - `Cache-Control: max-age=31536000, immutable` (1 год)

- `chart.js` (график температур):
  - Сжатый gzip из PROGMEM (`chart_min_js_gz.h`)
  - `Content-Encoding: gzip`
  - `Cache-Control: max-age=31536000, immutable` (1 год)

- `chartjs-adapter.js` (адаптер дат):
  - Сжатый gzip из PROGMEM (`chartjs_adapter_gz.h`)
  - `Content-Encoding: gzip`
  - `Cache-Control: max-age=31536000, immutable` (1 год)

### 21.3 API эндпоинты

| Метод | Путь | Обработчик |
|---|---|---|
| GET | /api/all | handleApiAllStates |
| GET | /api/config | handleApiConfig |
| POST | /api/config | обновление конфига (JSON) |
| POST | /api/config/defaults | handleApiConfigDefaults |
| GET | /api/wifi/status | handleApiWifiStatus |
| GET | /api/wifi/scan | handleApiWifiScan |
| GET | /api/wifi/connect | handleApiWifiConnect |
| POST | /api/wifi/reset | handleApiWifiReset |
| GET | /api/error-log | handleApiErrorLog |
| POST | /api/error-log/clear | handleApiErrorLogClear |
| GET | /api/uptime | handleApiUptime |
| GET | /api/target | handleApiGetTarget |
| POST | /api/target | handleApiTarget |
| POST | /api/heater-off | handleApiHeaterOff |
| GET | /api/heater-state | handleApiGetHeaterState |
| GET | /api/fan-state | handleApiGetFanState |
| POST | /api/reboot | handleApiReboot |
| POST | /api/reboot-all | handleApiRebootAll |
| GET | /api/nvs-health | занятость NVS |
| POST | /api/unlock | handleApiUnlock |
| POST | /api/lock-settings | handleApiLockSettings |
| POST | /api/unlock-settings | handleApiUnlockSettings |
| POST | /api/adapt/start | handleApiStartAdaptation |
| POST | /api/adapt/abort | handleApiAbortAdaptation |
| GET | /api/adapt/status | handleApiAdaptationStatus |
| POST | /api/adapt/continue | handleApiAdaptContinue |
| GET | /api/memory | handleApiMemory |
| POST | /api/calibrate-max6675 | handleApiCalibrateMAX6675 |
| POST | /api/thermal-model/reset | handleApiResetThermalModel |
| GET | /api/thermal-status | статус термальной модели |
| POST | /api/moonraker-shutdown | handleApiMoonrakerShutdown |
| POST | /api/manual-timer | handleApiManualTimer |
| GET | /api/duty-table | таблица duty |
| GET | /api/duty-table/add | добавление точки |
| GET | /api/device-id | ID устройства |
| POST | /api/update | OTA обновление |

### 21.4 WebSocket события

#### Сервер → клиент

- `metrics` — метрики (каждую секунду)  
- `history_chunk` — чанки истории при подключении  
- `history_update` — новые точки  

#### Клиент → сервер

- `get_updates:<timestamp>` — история с указанного времени  
- `get_history` — полная история  

### 21.5 Работа с памятью

- static char[] вместо String  
- StaticJsonDocument<N> вместо DynamicJsonDocument  
- чанки по 60 точек  
- configCacheValid = 2 секунды  

---

## 22. Система логирования

### 22.1 Уровни

```cpp
#define LOG_LEVEL 1  // 0=DEBUG, 1=INFO, 2=WARN, 3=ERROR, 4=SILENT

LOG_DEBUG(fmt, ...) // только LOG_LEVEL=0  
LOG_INFO(fmt, ...)  // ≤1  
LOG_WARN(fmt, ...)  // ≤2  
LOG_ERROR(fmt, ...) // ≤3  
LOG_FATAL(fmt, ...) // всегда  
```
### 22.2 Вывод

- Serial (115200 бод)  
- формат: `[LEVEL] сообщение`  
- `LOG_FATAL` всегда выводится  

---

## 23. Мьютексы и критические секции

| Мьютекс | Назначение | Доступ |
|---|---|---|
| tempMux | airTemp, heaterTemp | sensorTask (запись), все (чтение) |
| snapshotMux | SystemSnapshot | controlTask (запись), API (чтение) |
| errorLogMux | ErrorLogEntry vector | webTask / controlTask |
| trendBufferMux | trendBuffer[600] | webTask / controlTask |
| max6675Mux | SPI MAX6675 | sensorTask / webTask |

### Карта мьютексов и доступа задач

```
SensorTask
├── tempMux (запись)
└── max6675Mux (чтение)

ControlTask
├── tempMux (чтение)
├── snapshotMux (запись)
├── errorLogMux (чтение)
└── trendBufferMux (чтение для ошибок)

WebTask
├── errorLogMux (запись/чтение)
├── trendBufferMux (запись)
└── max6675Mux (калибровка)

API handler
├── snapshotMux (чтение)
└── errorLogMux (чтение)
```
#### Макросы температуры

```cpp
#define ENTER_CRITICAL_TEMP() // Вход + замер времени ожидания
#define EXIT_CRITICAL_TEMP()  // Выход
```
---

## Приложение A: Значения по умолчанию

### Системные константы

| Константа | Значение | Назначение |
|---|---|---|
| MAX_ERROR_LOG | 20 | Максимум записей в журнале |
| TREND_BUFFER_SIZE | 600 | Точек в истории |
| MAX_DUTY_TABLE_SIZE | 20 | Точек в таблице duty |
| AUTO_REBOOT_TIMEOUT | 86400000 мс | Бездействие до автоперезагрузки |
| BUTTON_HOLD_TIME | 5000 мс | Время удержания кнопки сброса |
| MAX6675_READ_INTERVAL | 500 мс | Период опроса термопары |
| DS18B20_RESOLUTION | 9 бит | Разрешение датчика воздуха |
| UDP_PORT | 12345 | Порт обнаружения Klipper |

### Температурные пороги

| Параметр | Значение | Описание |
|---|---|---|
| maxHeaterTemp | 110°C | Макс. рабочая температура нагревателя |
| criticalTemp | 120°C | Порог критического перегрева |
| criticalHysteresis | 5°C | Гистерезис сброса перегрева |
| maxAirTemp | 70°C | Макс. температура воздуха |
| airHysteresis | 3°C | Гистерезис перегрева воздуха |
| hysteresis | 0.5°C | Гистерезис управления по воздуху |
| heaterHysteresis | 4°C | Гистерезис управления по нагревателю |
| defaultTargetTemp | 0°C | Цель по умолчанию |

### Вентилятор

| Параметр | Значение | Описание |
|---|---|---|
| fanOnTemp | 55°C | Порог включения вентилятора |
| fanOffHysteresis | 3°C | Гистерезис выключения |
| fanMinOnTime | 30 сек | Мин. время работы |
| maxFanDuty | 1023 | Макс. мощность ШИМ (10 бит) |
| fanPwmFreq | 17000 Гц | Частота ШИМ |

### Интервалы управления

| Параметр | Значение | Описание |
|---|---|---|
| heaterControlInterval | 200 мс | Период управления SSR |
| fanControlInterval | 1000 мс | Период управления вентилятором |
| readInterval | 1000 мс | Период опроса датчиков |
| trendInterval | 3000 мс | Период сохранения истории |
| controlInterval | 3000 мс | Основной цикл защит |
| runawayCheckInterval | 5000 мс | Проверка Thermal Runaway |
| unexpectedCheckInterval | 2000 мс | Проверка Unexpected Heat |
| rateCheckInterval | 1000 мс | Проверка аномального роста |
| loopWatchdogTimeout | 30000 мс | Таймаут Task Watchdog |

### Система ошибок

| Параметр | Значение | Описание |
|---|---|---|
| maxErrorRetries | 3 | Ошибок до блокировки |
| errorWindowMinutes | 10 | Окно подсчёта (мин) |
| minTimeBetweenSameErrors | 30000 мс | Дедупликация ошибок |
| unlockPassword | "unlock" | Пароль разблокировки |

### Heartbeat

| Параметр | Значение | Описание |
|---|---|---|
| heartbeatPulseMs | 100 мс | Длительность импульса |
| heartbeatPauseMs | 900 мс | Пауза между импульсами |

### LED

| Параметр | Значение | Описание |
|---|---|---|
| ledCount | 3 | Количество светодиодов |
| ledBrightness | 50 | Яркость (0-255) |
| ledEnabled | true | LED включены |

### Зуммер

| Параметр | Значение | Описание |
|---|---|---|
| buzzerEnabled | true | Зуммер включён |
| buzzerNonCriticalEnabled | true | Некритические ошибки |
| buzzerMelody | 1 | Мелодия по умолчанию |

### Пины (заводские)

| Пин | Назначение |
|-----|---|
| 32 | SSR нагреватель |
| 33 | Вентилятор PWM |
| 26 | Watchdog heartbeat |
| 21 | DS18B20 (1-Wire) |
| 18 | MAX6675 SCK |
| 19 | MAX6675 SO |
| 5 | MAX6675 CS |
| 25 | Бипер |
| 27 | LED WS2812B |
| 17 | Кнопка сброса |

---

## Приложение Б: Диаграмма состояний

```
ЗАПУСК
│
▼
ИНИЦИАЛИЗАЦИЯ (setup)
│
▼
ОЖИДАНИЕ (цель=0)
│
├── цель>0 ──▶ НАГРЕВ
│ │
│ ├── цель достигнута ──▶ ПОДДЕРЖАНИЕ
│ │ │
│ ├── перегрев ──▶ АВАРИЯ (стоп)
│ │ │
│ ├── runaway ──▶ АВАРИЯ (стоп)
│ │ │
│ └── unexpected ──▶ АВАРИЯ (стоп)
│ │
│ 3 ошибки за 10 мин
│ │
│ ▼
│ БЛОКИРОВКА (пароль)
│
└── цель=0 ◀── (сброс цели или таймер)
```

---

## Приложение В: Глоссарий

| Термин | Значение |
|---|---|
| SSR | Solid State Relay — твердотельное реле, коммутирует 220В |
| Duty | Коэффициент заполнения ШИМ (0–1023), мощность вентилятора |
| PWM | Pulse Width Modulation — широтно-импульсная модуляция |
| LEDC | LED Control — аппаратный ШИМ-контроллер ESP32 |
| GPIO | General Purpose Input/Output — пин общего назначения |
| SPI | Serial Peripheral Interface — протокол обмена с MAX6675 |
| 1-Wire | Однопроводная шина для датчика DS18B20 |
| NVS | Non-Volatile Storage — энергонезависимая память ESP32 |
| Preferences | Библиотека Arduino для работы с NVS |
| FreeRTOS | Операционная система реального времени |
| Task | Задача FreeRTOS — независимый поток выполнения |
| Mutex | Мьютекс — синхронизация доступа к общим данным |
| Heap | Куча — динамическая память программы |
| Stack | Стек — память для переменных и вызовов функций |
| PROGMEM | Память программ (flash), для хранения констант |
| Watchdog | Сторожевой таймер — перезагрузка при зависании |
| Heartbeat | Периодический сигнал для внешнего watchdog |
| Thermocouple | Термопара K-типа — датчик температуры нагревателя |
| MAX6675 | Микросхема-усилитель термопары с SPI-интерфейсом |
| DS18B20 | Цифровой датчик температуры, интерфейс 1-Wire |
| Thermal Runaway | Неконтролируемый разогрев при неисправности |
| Unexpected Heat | Нагрев при выключенном SSR (залипшее реле) |
| Klipper | Прошивка для 3D-принтеров |
| Moonraker | Веб-сервер для Klipper (API) |
| API | Application Programming Interface |
| REST | Representational State Transfer — стиль API |
| JSON | JavaScript Object Notation — формат обмена данными |
| WebSocket | Протокол двусторонней связи поверх TCP |
| SPA | Single Page Application — одностраничное приложение |
| OTA | Over The Air — обновление прошивки по Wi-Fi |
| gzip | Формат сжатия веб-интерфейса |
| ETag | HTTP-заголовок для кэширования |
| CORS | Cross-Origin Resource Sharing |
| UDP | User Datagram Protocol — обнаружение Klipper |
| AP | Access Point — режим точки доступа Wi-Fi |
| STA | Station — режим клиента Wi-Fi |
| RSSI | Received Signal Strength Indicator |
| NeoPixel | Адресная светодиодная лента WS2812B |
| FIFO | First In First Out — очередь с вытеснением |
| EaseInOut | Функция плавности для LED-анимаций |
| DJB2 | Алгоритм хеширования для дедупликации ошибок |
| UART | Universal Asynchronous Receiver-Transmitter |
| Baud Rate | Скорость Serial (115200 бод) |
| Brownout | Провал напряжения питания |
| Panic | Критическая ошибка FreeRTOS |

[🔝 Наверх](#-прошивка-flook32)

---

[🔙 На главную](../README.md)

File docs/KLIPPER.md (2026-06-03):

[🔙 На главную](../README.md)

# Интеграция с Klipper

**Файлы:** `flook32.py` и `flook32.cfg`

## 📋 Содержание

- [Установка модуля](#1-установка-модуля)
- [Настройка printer.cfg](#2-настройка-printercfg)
- [Проверка работы](#3-проверка-работы)
- [Полный список параметров](#params)
- [Автоотключение по Moonraker](#4-автоотключение-по-moonraker)

---

### Принцип работы модуля

Плагин `flook32.py` и прошивка `flook32.ino` спроектированы так, чтобы **передаваемая температура никогда не могла вызвать падение Klipper**.

| Что делает плагин | Что НЕ делает плагин |
|---|---|
| Передаёт показания датчика как есть | Не анализирует температуру |
| Выводит ошибки | Не принимает решений об остановке печати |
| Возвращает последнее валидное значение при потере связи | Не генерирует исключений |
| Продолжает работать даже если FLOOK32 недоступен | Не падает в ошибку по связи |

### Почему Klipper не упадёт

1. **Нет критических проверок** — плагин не проверяет валидность температуры
2. **Fallback значения** — при потере связи возвращается последнее успешно полученное значение
3. **Отсутствие исключений** — любые ошибки перехватываются и логируются, но не прерывают работу
4. **Таймауты** — HTTP и WebSocket запросы имеют жёсткие таймауты

### Пример

Даже если FLOOK32 отключится или нагреватель выйдет за допустимые пределы:

```yaml
# Пример 1: перегрев воздуха — FLOOK32 сам отключил нагрев
# Входные данные (с FLOOK32)
airTemp: 85.0  # Перегрев воздуха, FLOOK32 отключил SSR, вентилятор 100%

# Выходные данные (в Klipper)
temperature: 85.0  # Плагин передаёт реальное значение, но нагрев уже отключён

# Klipper ПРОДОЛЖАЕТ печать — нагрев безопасно остановлен силами FLOOK32

# Пример 2: потеря связи — плагин возвращает хардкод значение
# Входные данные (с FLOOK32)
airTemp: недоступен  # FLOOK32 отключился или потерял связь

# Выходные данные (в Klipper)
temperature: 25.0  # Возвращается хардкод значение

# Klipper ПРОДОЛЖАЕТ печать — паузы или аварийной остановки не происходит
```

### Отображение ошибок

Все ошибки FLOOK32 выводятся в консоль Klipper, но **не влияют на ход печати**:

```text
!! FLOOK32: КРИТИЧЕСКАЯ ОШИБКА [00:15:30]: Перегрев нагревателя! T=125.0°C
!! FLOOK32: КРИТИЧЕСКАЯ ОШИБКА [00:16:45]: Система заблокирована: Тройной перегрев нагревателя (3/3)
```

Печать продолжается, пользователь видит ошибку, но принтер не останавливается.

### Итог

Плагин работает как **пассивный датчик температуры**, а не как активная система защиты. Вся логика безопасности остаётся на стороне FLOOK32.

## 1. Установка модуля

### 1.1 Копирование файлов

Скопируйте файл `flook32.py` в директорию расширений Klipper:

```bash
cp flook32.py ~/klipper/klippy/extras/
```

Скопируйте файл `flook32.cfg` в папку с `printer.cfg`:

```bash
cp flook32.cfg ~/printer_data/config/
```

### 1.2 Установка WebSocket клиента (опционально)

Для получения данных датчкиков в реальном времени:

```bash
pip install websocket-client
```

## 2. Настройка printer.cfg

Добавьте в файл `printer.cfg`:

```ini
[include flook32.cfg]
```

### 2.1 Перезапуск Klipper

```bash
sudo systemctl restart klipper
```

## 3. Проверка работы

### 3.1 Логи Klipper

Проверьте, что плагин загрузился:

```bash
tail -f ~/klipper/logs/klippy.log
```
Вы должны увидеть:

```text
Loaded module 'flook32'
Found FLOOK32 at 192.168.1.100
```
### 3.2 Веб-интерфейс Mainsail / Fluidd

После настройки в интерфейсе Mainsail или Fluidd появится датчик `chamber` с текущей температурой воздуха.

### 3.3 GCODE команды

Стандартные команды `M141`/`M191` **не поддерживаются плагином напрямую**. Для их работы добавлены макросы-переопределения в `flook32.cfg`:

<details>
<summary>Почему макросы не вшиты в плагин?</summary>

Макросы `M141`/`M191` могут быть уже определены в среде пользователя на принтере. Плагин не навязывает жёсткую логику — вы можете написать их под свой конкретный случай, изменяя макросы на своё усмотрение.

</details>

| Команда | Описание | Реализация |
|---|---|---|
| `M141 S60` | Установить цель 60°C | Через макрос → `FLOOK_SET S=60` |
| `M141 S0` | Выключить нагрев | Через макрос → `FLOOK_OFF` |
| `M191 S60` | Ждать достижения цели | Через макрос → `FLOOK_SET S=60` + `TEMPERATURE_WAIT` |

<details>
<summary><strong>📋 Макросы Klipper (нажмите, чтобы развернуть)</strong></summary>

| Макрос | Описание |
|---|---|
| `FLOOK_SET S=55` | Установить целевую температуру (S=0 = выключить) |
| `FLOOK_OFF` | Аварийное выключение нагрева |
| `FLOOK_STATUS` | Показать статус устройства |
| `FLOOK_TEMP` | Показать текущую температуру |
| `FLOOK_DISCOVER` | Принудительный поиск устройств в сети |
| `FLOOK_SET_IP IP=192.168.1.100` | Установить IP адрес вручную |
| `FLOOK_UNLOCK [PASSWORD=xxx]` | Разблокировать настройки |
| `FLOOK_LOCK` | Заблокировать настройки |
| `FLOOK_REBOOT` | Перезагрузить ESP32 |
| `FLOOK_RESET_ID` | Сбросить сохраненный ID устройства |
| `FLOOK_CONFIG_GET` | Показать текущую конфигурацию |
| `FLOOK_AUTO_SHUTDOWN [ENABLE=1] [MINUTES=30]` | Управление автоотключением |
| `FLOOK_AUTO_SHUTDOWN_STATUS` | Статус автоотключения |
| `FLOOK_ERRORS` | Показать журнал ошибок |
| `FLOOK_CALIBRATE TEMP=100` | Калибровка MAX6675 по эталону |
| `FLOOK_ADAPT_START TARGET=60` | Запуск адаптации |
| `FLOOK_ADAPT_ABORT` | Прервать адаптацию |
| `FLOOK_ADAPT_STATUS` | Статус адаптации |

</details>

### 3.4 Интеграция в START_PRINT и END_PRINT

Для автоматической установки температуры камеры из слайсера и отключения нагрева по окончании печати необходимо добавить вызовы макросов `M141`/`M191` в системные макросы принтера `START_PRINT` и `END_PRINT`.

Универсальной инструкции не существует — структура этих макросов зависит от конкретного принтера, прошивки и пользовательских модификаций. Ниже приведён минимальный пример, который можно адаптировать под свою конфигурацию:

**START_PRINT (фрагмент):**
```
[gcode_macro START_PRINT]
gcode:
    {% set CHAMBER = params.CHAMBER|default(0)|float %}
    # ... разогрев стола, парковка, прогрев сопла ...
    M141 S{CHAMBER}        ; Установить температуру камеры из слайсера
    M191 S{CHAMBER}         ; Ждать достижения цели (опционально)
    # ... старт печати ...
```

**END_PRINT (фрагмент):**
```
[gcode_macro END_PRINT]
gcode:
    M141 S0                 ; Выключить нагрев камеры
    # ... парковка, охлаждение, отключение моторов ...
```

## 4. Автоотключение по Moonraker

### Зачем это нужно?

Если вы часто печатаете несколько моделей подряд и не хотите, чтобы камера остывала между печатями — не добавляйте команду `M141 S0` в макрос `END_PRINT`. Вместо этого используйте автоотключение по Moonraker: FLOOK32 будет отслеживать статус печати и отключит нагрев только через заданное время после её завершения.

Это также полезно, если по какой-то причине вы не можете использовать плагин Klipper и не можете использовать макросы с `wget` из `shell_command` — встроенная функция автоотключения работает независимо от плагина, напрямую через HTTP-запросы к Moonraker API.

### 4.1 Настройка в веб-интерфейсе

1. Откройте веб-интерфейс FLOOK32
2. Перейдите в **Настройки → Общие**
3. В разделе **Moonraker автоотключение**:
   - Установите чекбокс **Включить автоотключение после печати**
   - Выберите время ожидания (5-120 минут)

### 4.2 Принцип работы

1. FLOOK32 опрашивает Moonraker API
2. Отслеживает статус печати: `printing` → `complete`/`error`
3. После завершения печати ждёт N минут
4. Выключает нагрев камеры

### 4.3 Проверка связи с Moonraker

Статус Moonraker отображается в веб-интерфейсе FLOOK32 на главной странице, в блоке Klipper.

| Индикатор | Значение |
|---|---|
| 🌙 Автоотключение через N мин после печати | Moonraker подключён, автоотключение настроено и работает |
| 🌙 Moonraker не подключён | Moonraker недоступен, автоотключение не работает |

## 5. Отправка конфигурации на ESP32

### Принцип работы

Плагин Klipper отправляет на ESP32 **только те параметры, которые явно указаны в printer.cfg**. Это позволяет:

- Не затирать настройки по умолчанию на устройстве
- Изменять только нужные параметры

### Процесс отправки

1. При запуске плагин читает секцию `[temperature_sensor chamber]` в printer.cfg
2. Формирует JSON с указанными параметрами
3. Отправляет POST запрос на `http://[IP]/api/config`
4. ESP32 сравнивает и применяет только изменённые параметры

### Пример

**В printer.cfg указано:**

```ini
[temperature_sensor chamber]
sensor_type: flook32
flook_ip: 192.168.1.100
max_heater_temp: 105.0
fan_on_temp: 60.0
```

На ESP32 будет отправлено:

```json
{
  "maxHeaterTemp": 105.0,
  "fanOnTemp": 60.0
}
```
Параметры `criticalTemp`, `maxAirTemp`, `hysteresis` и остальные останутся как на устройстве.

### Какие параметры можно отправлять

Любые параметры из [полного списка](#полный-список-параметров).

### Проверка

После отправки конфигурации можно проверить:

```bash
FLOOK_CONFIG_GET
```

## 📋 Полный список параметров конфигурации

<details>
<summary><strong>Нажмите, чтобы развернуть</strong></summary>

| Категория | Параметр | Тип | По умолчанию | Описание |
|---|---|-----|---|---|
| **Основные** | | | | |
| | `sensor_type` | string | — | Тип датчика (обязательно: flook32) |
| | `flook_ip` | string | авто | IP адрес FLOOK32 |
| | `auto_discover` | bool | True | Авто-поиск по UDP |
| | `report_interval` | float | 10.0 | Интервал опроса HTTP (5-60 сек) |
| | `silent` | bool | False | Тихий режим |
| **Уведомления об ошибках** | | | | |
| | `enable_error_notifications` | bool | True | Включить уведомления об ошибках |
| | `error_notification_max_age` | int | 600 | Макс. возраст ошибки (сек) |
| | `error_check_interval` | int | 30 | Частота проверки API (сек) |
| | `show_trends` | bool | True | Показывать тренды ошибок |
| | `max_trend_lines` | int | 30 | Макс. строк трендов |
| **Термальная модель** | | | | |
| | `enable_thermal_model` | bool | False | Включить термальную модель |
| | `thermal_model_sensitivity` | float | 1.0 | Чувствительность модели |
| | `thermal_model_check_interval` | int | 2000 | Интервал проверки (мс) |
| | `thermal_model_log_warnings` | bool | True | Логировать предупреждения |
| **Защиты** | | | | |
| | `max_heater_temp` | float | 100.0 | Макс. температура нагревателя (°C) |
| | `enable_thermal_runaway` | bool | True | Включить защиту Thermal Runaway |
| | `runaway_quick_check_temp` | float | 60.0 | Фаза 0: мин. температура через 45 сек (°C) |
| | `runaway_phase1_time` | int | 5 | Время фазы 1 (мин) |
| | `runaway_phase2_time` | int | 15 | Время фазы 2 (мин) |
| | `runaway_max_time_to_target` | int | 30 | Макс. время до цели (мин) |
| | `runaway_min_heater_rise` | float | 2.0 | Мин. нагрев нагревателя (°C/мин) |
| | `runaway_min_air_rise` | float | 0.5 | Мин. нагрев воздуха (°C/мин) |
| | `runaway_max_heater_drop` | float | 15.0 | Макс. падение нагревателя (°C) |
| | `runaway_hysteresis` | float | 2.0 | Гистерезис runaway (°C) |
| | `runaway_recovery_timeout` | int | 30 | Таймаут восстановления (сек) |
| | `runaway_fan_on` | bool | False | Включить вентилятор при runaway |
| | `enable_unexpected_heat` | bool | True | Включить защиту от неожиданного нагрева |
| | `unexpected_heat_timeout` | int | 45 | Таймаут (сек) |
| | `unexpected_heat_threshold` | float | 15.0 | Порог нагрева (°C) |
| | `min_cooling_rate` | float | 1.0 | Мин. скорость охлаждения (°C/сек) |
| | `unexpected_heat_hysteresis` | float | 3.0 | Гистерезис (°C) |
| | `unexpected_heat_clear_time` | int | 30000 | Время сброса (мс) |
| | `unexpected_heat_safe_offset` | float | 10.0 | Безопасный оффсет (°C) |
| | `enable_unexpected_heat_adaptive` | bool | False | Адаптивный порог |
| | `adaptive_base_temp` | float | 20.0 | Базовая температура (°C) |
| | `adaptive_coefficient` | float | 0.3 | Коэффициент адаптации |
| | `adaptive_min_offset` | float | 30.0 | Мин. адаптивный оффсет (°C) |
| **Вентилятор** | | | | |
| | `fan_on_temp` | float | 55.0 | Температура включения (°C) |
| | `fan_off_hysteresis` | float | 3.0 | Гистерезис выключения (°C) |
| | `fan_min_on_time` | int | 30 | Мин. время работы (сек) |
| | `invert_fan_signal` | bool | False | Инвертировать сигнал |
| | `max_fan_duty` | int | 1023 | Макс. мощность (0-1023) |
| | `fan_efficiency_timeout` | int | 120 | Таймаут проверки (сек) |
| | `fan_efficiency_threshold` | float | 2.0 | Порог эффективности (°C) |
| | `enable_fan_efficiency_check` | bool | True | Проверка эффективности |
| | `enable_fan_auto_limit` | bool | False | Автоограничение мощности |
| | `fan_auto_limit_hysteresis` | float | 3.0 | Гистерезис (°C) |
| | `fan_auto_limit_adjust_step` | int | 10 | Шаг изменения duty |
| | `fan_auto_limit_min_duty` | int | 400 | Мин. duty |
| | `fan_auto_limit_check_interval` | int | 5000 | Интервал проверки (мс) |
| | `fan_auto_limit_stable_count` | int | 3 | Замеров для стабилизации |
| **MAX6675** | | | | |
| | `max6675_offset` | float | 0.0 | Калибровка оффсет (°C) |
| | `enable_max6675_protection` | bool | True | Защита датчика |
| | `max6675_stability_samples` | int | 3 | Выборки для стабильности |
| | `max6675_temp_jump_threshold` | float | 20.0 | Порог скачка (°C) |
| | `max6675_min_temp` | float | -50.0 | Мин. температура (°C) |
| | `max6675_max_temp` | float | 400.0 | Макс. температура (°C) |
| **DS18B20** | | | | |
| | `ds18b20_offset` | float | 0.0 | Калибровка оффсет (°C) |
| | `ds18b20_scale` | float | 1.0 | Масштаб |
| | `ds18b20_cal_enabled` | bool | False | Включить калибровку |
| | `enable_air_sensor_protection` | bool | True | Защита датчика |
| | `air_sensor_stability_samples` | int | 5 | Выборки для стабильности |
| | `air_sensor_temp_jump_threshold` | float | 2.0 | Порог скачка (°C) |
| | `air_sensor_min_temp` | float | -40.0 | Мин. температура (°C) |
| | `air_sensor_max_temp` | float | 125.0 | Макс. температура (°C) |
| | `air_sensor_unstable_range` | float | 3.0 | Диапазон нестабильности (°C) |
| | `air_sensor_unstable_deviation` | float | 1.5 | Отклонение (°C) |
| | `air_sensor_unstable_window` | int | 10 | Окно нестабильности |
| | `air_sensor_direction_changes` | int | 3 | Смены направления |
| **Ошибки и блокировки** | | | | |
| | `max_error_retries` | int | 3 | Макс. повторов ошибки |
| | `error_window_minutes` | int | 10 | Окно подсчёта (мин) |
| | `min_time_between_same_errors` | int | 30000 | Мин. время между ошибками (мс) |
| | `min_time_between_overheat_counts` | int | 5000 | Мин. время между перегревами (мс) |
| | `unlock_password` | string | unlock | Пароль разблокировки |
| | `settings_locked` | bool | True | Блокировка настроек |
| **LED** | | | | |
| | `led_enabled` | bool | True | Включить LED |
| | `led_count` | int | 3 | Количество светодиодов |
| | `led_brightness` | int | 50 | Яркость (0-255) |
| | `led_pin` | int | 27 | Пин LED |
| **Heartbeat** | | | | |
| | `heartbeat_pulse_ms` | int | 100 | Длительность импульса (мс) |
| | `heartbeat_pause_ms` | int | 900 | Пауза между импульсами (мс) |
| **Зуммер** | | | | |
| | `buzzer_enabled` | bool | True | Включить зуммер |
| | `buzzer_non_critical_enabled` | bool | False | Пищать на некритичные ошибки |
| | `buzzer_melody` | int | 1 | Мелодия (0=короткий, 1=двойной, 2=аларма) |
| **Интервалы** | | | | |
| | `read_interval` | int | 1000 | Интервал чтения (мс) |
| | `control_interval` | int | 3000 | Интервал управления (мс) |
| | `trend_interval` | int | 5000 | Интервал тренда (мс) |
| | `heap_check_interval` | int | 30000 | Проверка кучи (мс) |
| | `loop_watchdog_timeout` | int | 30000 | Таймаут watchdog (мс) |
| | `enable_loop_watchdog` | bool | True | Включить watchdog |
| | `udp_discovery_timeout` | int | 30000 | Таймаут UDP (мс) |
| | `discovery_retry_interval` | int | 1000 | Интервал повтора (мс) |
| | `heater_control_interval` | int | 200 | Интервал управления нагревателем (мс) |
| | `fan_control_interval` | int | 1000 | Интервал управления вентилятором (мс) |
| | `runaway_check_interval` | int | 5000 | Интервал проверки runaway (мс) |
| | `unexpected_check_interval` | int | 2000 | Интервал проверки неожиданного нагрева (мс) |
| | `rate_check_interval` | int | 1000 | Интервал проверки скорости (мс) |
| **Автоотключение** | | | | |
| | `auto_shutdown_enabled` | bool | False | Включить автоотключение после печати |
| | `auto_shutdown_minutes` | int | 30 | Время ожидания после печати (мин) |
| **Пины** | | | | |
| | `pin_ssr` | int | 32 | Пин SSR (нагреватель) |
| | `pin_fan` | int | 33 | Пин вентилятора |
| | `pin_watchdog` | int | 26 | Пин watchdog |
| | `pin_onewire` | int | 21 | Пин OneWire (DS18B20) |
| | `pin_max_sck` | int | 18 | Пин SCK (MAX6675) |
| | `pin_max_so` | int | 19 | Пин SO (MAX6675) |
| | `pin_max_cs` | int | 5 | Пин CS (MAX6675) |
| | `pin_buzzer` | int | 25 | Пин зуммера |
| | `pin_led` | int | 27 | Пин LED |
| | `pin_button` | int | 17 | Пин кнопки сброса |

</details>

## Схема взаимодействия

```
Klipper (flook32.py)
│
├── HTTP GET /api/all ────▶ FLOOK32 (ESP32)
│ ◀──── JSON (температуры, статус) ────┤
│
├── WebSocket /ws ─────────▶ FLOOK32
│ ◀──── real-time метрики ─────────────┤
│
├── UDP broadcast ─────────▶ FLOOK32
│ ◀──── FLOOK32:<IP>:<uptime>:<temp>:<id>
│
└── Moonraker API (localhost) ──▶ Сохранение ID, нотификации
```

[🔝 Наверх](#интеграция-с-klipper)

---

[🔙 На главную](../README.md)

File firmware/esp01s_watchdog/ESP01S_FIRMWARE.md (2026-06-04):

[🔙 На главную](../../README.md)

# 🔒 ESP-01S Watchdog — автономный сторожевой таймер

**Файл:** `firmware/esp01s_watchdog/esp01s_watchdog.ino`  
**Платформа:** ESP-01S (ESP8266)  
**Среда разработки:** Arduino IDE   
**Размер:** ~150 строк (C++)  
**Зависимости:** нет 

Аппаратный сторожевой таймер для защиты нагревателя камеры 3D-принтера от зависания основного контроллера.

---

## Содержание
0. [Быстрая прошивка](#0--быстрая-прошивка)
1. [Общая информация](#1-общая-информация)
2. [Аппаратная часть](#2-аппаратная-часть)
3. [Принцип работы](#3-принцип-работы)
4. [Структура прошивки](#4-структура-прошивки-setup--loop)
5. [Тайминги и константы](#5-тайминги-и-константы)
6. [Обработка прерываний](#6-обработка-прерываний)
7. [Управление реле](#7-управление-реле)
8. [Диаграмма состояний](#8-диаграмма-состояний)
9. [Совместимость с FLOOK32](#9-совместимость-с-flook32)
10. [Поиск неисправностей](#10-поиск-неисправностей)

- [Приложение А: Глоссарий](#приложение-а-глоссарий)

---

## 0. 🚀 Быстрая прошивка

Если не хотите разбираться с Arduino IDE, воспользуйтесь готовыми скриптами из папки `firmware/esp01s_watchdog/`:

**Windows:**
1. Подключите ESP-01S к программатору с перемычкой GPIO0-GND
2. Запустите `flash_esp01s.bat` двойным щелчком

**Linux/macOS:**
1. Подключите ESP-01S к программатору с перемычкой GPIO0-GND
2. Сделайте скрипт исполняемым и запустите:
   ```bash
   chmod +x flash_esp01s.sh
   ./flash_esp01s.sh
   ```

Скрипты установят `esptool` (если нужно), скачают прошивку из репозитория и прошьют устройство.

> 💡 **Совет:** если скрипт не может найти или прошить ESP-01S:
> - Проверьте перемычку GPIO0-GND (режим прошивки)
> - Используйте основные USB с материнской платы ПК, не используйте USB-хаб.

---

## 1. Общая информация

### Назначение

ESP-01S выполняет роль аппаратного watchdog — независимого контроллера, который отключает питание 220В нагревателя, если основной ESP32 (FLOOK32) завис или вышел из строя.

### Ключевые особенности

* Полная независимость от основной прошивки — работает на отдельном микроконтроллере
* Аппаратное прерывание по фронту сигнала heartbeat
* Требуется 3 последовательных импульса для включения реле
* Автоматическое отключение реле через 6 секунд после пропадания сигнала
* Защита от случайных помех и ложных срабатываний
* Сторожевой таймер ESP8266 для самовосстановления

### Целевая платформа

* ESP-01S (ESP8266)
* Flash: 1MB
* Ядро: Tensilica L106 32-bit, 80 МГц

### Зависимости

Нет внешних библиотек. Используются только встроенные функции Arduino Core для ESP8266:

* `attachInterrupt()` — аппаратное прерывание
* `ICACHE_RAM_ATTR` — размещение ISR в RAM для стабильности
* `ESP.wdtFeed()` — сброс программного watchdog ESP8266

---

## 2. Аппаратная часть

### Таблица GPIO пинов

| Пин | Назначение | Направление | Примечание |
|-----|---|---|---|
| GPIO0 | Реле (питание 220В) | OUTPUT | HIGH = реле замкнуто, LOW = разомкнуто |
| GPIO2 | Heartbeat вход | INPUT | Прерывание по RISING (LOW→HIGH) |

### Схема подключения

```
FLOOK32 (ESP32)                    ESP-01S (ESP8266)                Нагрузка
┌──────────────┐                  ┌──────────────┐              ┌──────────┐
│              │                  │              │              │          │
│  GPIO26 ─────┼──────────────────┼  GPIO2       │              │  220V    │
│  (heartbeat) │   импульс каждые │  (вход)      │     NO  ─────┼──────────┤
│              │   1000 мс        │              │   (реле)     │          │
│              │                  │              │              │ Нагрева- │
│              │                  │              │              │ тель     │
└──────────────┘                  └──────────────┘              └──────────┘
```

### Принцип работы реле

* Реле нормально-разомкнутое (NO)
* HIGH на GPIO0 → реле замкнуто → 220В подаётся на нагреватель
* LOW на GPIO0 → реле разомкнуто → 220В отключено

---

## 3. Принцип работы

### Алгоритм

```
1. При старте реле ВЫКЛЮЧЕНО (безопасное состояние)
2. Ожидание импульсов от FLOOK32 на GPIO2
3. Получено 3 импульса подряд с интервалом < 5 секунд → реле ВКЛЮЧЕНО
4. Импульсы продолжают приходить → реле остаётся ВКЛЮЧЕНО
5. Импульсы пропали на 6 секунд → реле ВЫКЛЮЧЕНО
6. Возврат к шагу 2
```

### Почему 3 импульса?

Защита от случайного включения при помехах или кратковременных наводках на линию. Одиночный всплеск не включит реле.

### Почему 6 секунд?

FLOOK32 отправляет импульс каждые ~1000 мс (100 мс HIGH + 900 мс LOW). Если ESP32 зависла:
* Последний импульс уходит
* Через 6 секунд ESP-01S гарантированно обнаруживает пропадание (даже с запасом на джиттер)
* Реле отключается

---

## 4. Структура прошивки (setup + loop)

### 4.1 setup()

```
1. pinMode(RELAY_PIN, OUTPUT)
   └─ digitalWrite(RELAY_PIN, RELAY_OFF) — реле выключено
   └─ delay(200) — стабилизация пина

2. pinMode(HEARTBEAT_PIN, INPUT)
   └─ Настройка пина как вход для heartbeat сигнала

3. lastPulseTime = millis()
   └─ Инициализация таймера последнего импульса

4. attachInterrupt(digitalPinToInterrupt(HEARTBEAT_PIN), onPulse, RISING)
   └─ Прерывание по фронту LOW→HIGH на GPIO2
   └─ ISR: onPulse() — устанавливает pulseFlag = true
```

### 4.2 loop()

```
1. ESP.wdtFeed()
   └─ Сброс программного watchdog ESP8266 (~3.2 сек таймаут)

2. Обработка флага прерывания:
   └─ if (pulseFlag):
       ├─ Сброс флага
       ├─ Проверка интервала с прошлым импульсом
       │   ├─ < 5 сек → consecutivePulses++
       │   └─ ≥ 5 сек → consecutivePulses = 1 (начало новой серии)
       └─ Обновление lastPulseTime

3. Проверка таймаута сигнала:
   └─ if (now - lastPulseTime > 6000 мс):
       └─ consecutivePulses = 0 (сброс счётчика)

4. Принятие решения о реле:
   └─ shouldRelayOn = (consecutivePulses >= 3)
   └─ if (shouldRelayOn != relayState):
       └─ setRelay(shouldRelayOn) — переключение при изменении

5. delay(20) — минимальная задержка для стабильности
```

---

## 5. Тайминги и константы

| Константа | Значение | Описание |
|---|---|---|
| SIGNAL_LOSS_TIMEOUT_MS | 6000 мс | Время без сигнала до отключения реле |
| PULSE_TIMEOUT_MS | 5000 мс | Максимальный интервал между импульсами |

### Расчёт таймаутов

**Интервал heartbeat от FLOOK32:**
```
heartbeatPulseMs + heartbeatPauseMs = 100 + 900 = 1000 мс
```

**SIGNAL_LOSS_TIMEOUT_MS (6000 мс):**
```
6 × 1000 мс = 6 пропущенных импульсов
Достаточно для гарантированного детектирования зависания
с запасом на случайную задержку передачи
```

**PULSE_TIMEOUT_MS (5000 мс):**
```
5 × 1000 мс = 5 интервалов heartbeat
Если между импульсами прошло больше — считаем что серия прервалась
```

---

## 6. Обработка прерываний

### 6.1 ISR (Interrupt Service Routine)

```cpp
ICACHE_RAM_ATTR void onPulse()
{
    pulseFlag = true;
}
```

**ICACHE_RAM_ATTR** — размещает функцию в оперативной памяти (IRAM), а не во flash. Это критически важно для стабильной работы прерываний на ESP8266, так как flash-память может быть занята в момент срабатывания прерывания.

### 6.2 Обработка в loop()

Обработка флага вынесена в основной цикл, а не в ISR, чтобы:
* Не блокировать другие прерывания
* Избежать длительных операций в контексте прерывания
* Иметь доступ ко всем переменным без volatile

---

## 7. Управление реле

### 7.1 Функция setRelay()

```cpp
void setRelay(bool on)
{
    digitalWrite(RELAY_PIN, on ? RELAY_ON : RELAY_OFF);
    relayState = on;
}
```

* `on = true` → реле замкнуто (220В подано)
* `on = false` → реле разомкнуто (220В отключено)

### 7.2 Безопасное состояние

При старте реле всегда выключено:
```cpp
digitalWrite(RELAY_PIN, RELAY_OFF);  // RELAY_OFF = LOW
```

Это гарантирует, что после перезагрузки ESP-01S нагреватель не включится самопроизвольно.

### 7.3 Переключение только при изменении

```cpp
if (shouldRelayOn != relayState) {
    setRelay(shouldRelayOn);
}
```

Предотвращает излишние переключения реле, продлевая его ресурс.

---

## 8. Диаграмма состояний

```
ПИТАНИЕ ВКЛ
│
▼
РЕЛЕ ВЫКЛ (безопасное)
│
├── 3 импульса за 5 сек ──▶ РЕЛЕ ВКЛ
│ │
│ ├── импульсы продолжаются ──▶ РЕЛЕ ВКЛ (удержание)
│ │
│ └── 6 сек без импульсов ──▶ РЕЛЕ ВЫКЛ (авария ESP32)
│ │
│ ▼
│ РЕЛЕ ВЫКЛ (безопасное)
│
└── (цикл повторяется)
```

---

## 9. Совместимость с FLOOK32

### 9.1 Параметры heartbeat в FLOOK32

Для корректной работы с ESP-01S watchdog в конфигурации FLOOK32 должны быть установлены:

| Параметр | Значение | Обоснование |
|---|---|---|
| heartbeatPulseMs | 100 мс | Длительность импульса должна быть достаточной для детектирования прерыванием |
| heartbeatPauseMs | 900 мс | Суммарный период 1000 мс гарантирует 6 импульсов за 6 секунд |

### 9.2 Условия генерации heartbeat (со стороны FLOOK32)

Heartbeat генерируется только когда:
* `targetTemp > 0` (есть цель по температуре)
* Нет критических ошибок
* Система не заблокирована
* Датчики исправны

Если нагрев выключен или система в аварии — heartbeat не генерируется, реле размыкается.

### 9.3 Проверка работоспособности

1. Загрузите прошивку на ESP-01S
2. Подключите к FLOOK32 по схеме
3. Установите целевую температуру > 0°C
4. Реле должно включиться через ~3 секунды (3 импульса)
5. Отключите нагрев — реле должно отключиться через 6 секунд

---

## 10. Поиск неисправностей

| Симптом | Возможная причина | Решение |
|---|---|---|
| Реле не включается | Нет сигнала heartbeat от FLOOK32 | Проверить провод GPIO26 → GPIO2, проверить импульсы |
| Реле не включается | Помехи на линии | Укоротить провод, экранировать провод |
| Реле включается с задержкой | Слишком длинный интервал heartbeat | Проверить heartbeatPauseMs в FLOOK32 |
| Реле отключается самопроизвольно | Нестабильный heartbeat | Проверить стабильность работы ControlTask в FLOOK32 |
| Реле не отключается при зависании | Завис сам ESP-01S | Программный watchdog ESP8266 перезагрузит ESP-01S через ~3.2 сек |

---

## Приложение А: Глоссарий

| Термин | Значение |
|---|---|
| ESP-01S | Модуль на базе ESP8266EX с 1MB flash, 8-контактный |
| Heartbeat | Периодический сигнал, подтверждающий работоспособность основного контроллера |
| Watchdog | Сторожевой таймер — механизм обнаружения зависаний |
| ISR | Interrupt Service Routine — обработчик прерывания |
| ICACHE_RAM_ATTR | Атрибут размещения функции в IRAM (оперативной памяти) |
| IRAM | Internal RAM — оперативная память, доступная для выполнения кода |
| RISING | Тип прерывания: срабатывание по фронту LOW → HIGH |
| SSR | Solid State Relay — твердотельное реле |
| Джиттер | Нестабильность периода следования импульсов |
| NO | Normally Open — нормально-разомкнутое реле |

[🔝 Наверх](#-esp-01s-watchdog)

---

[🔙 На главную](../../README.md)

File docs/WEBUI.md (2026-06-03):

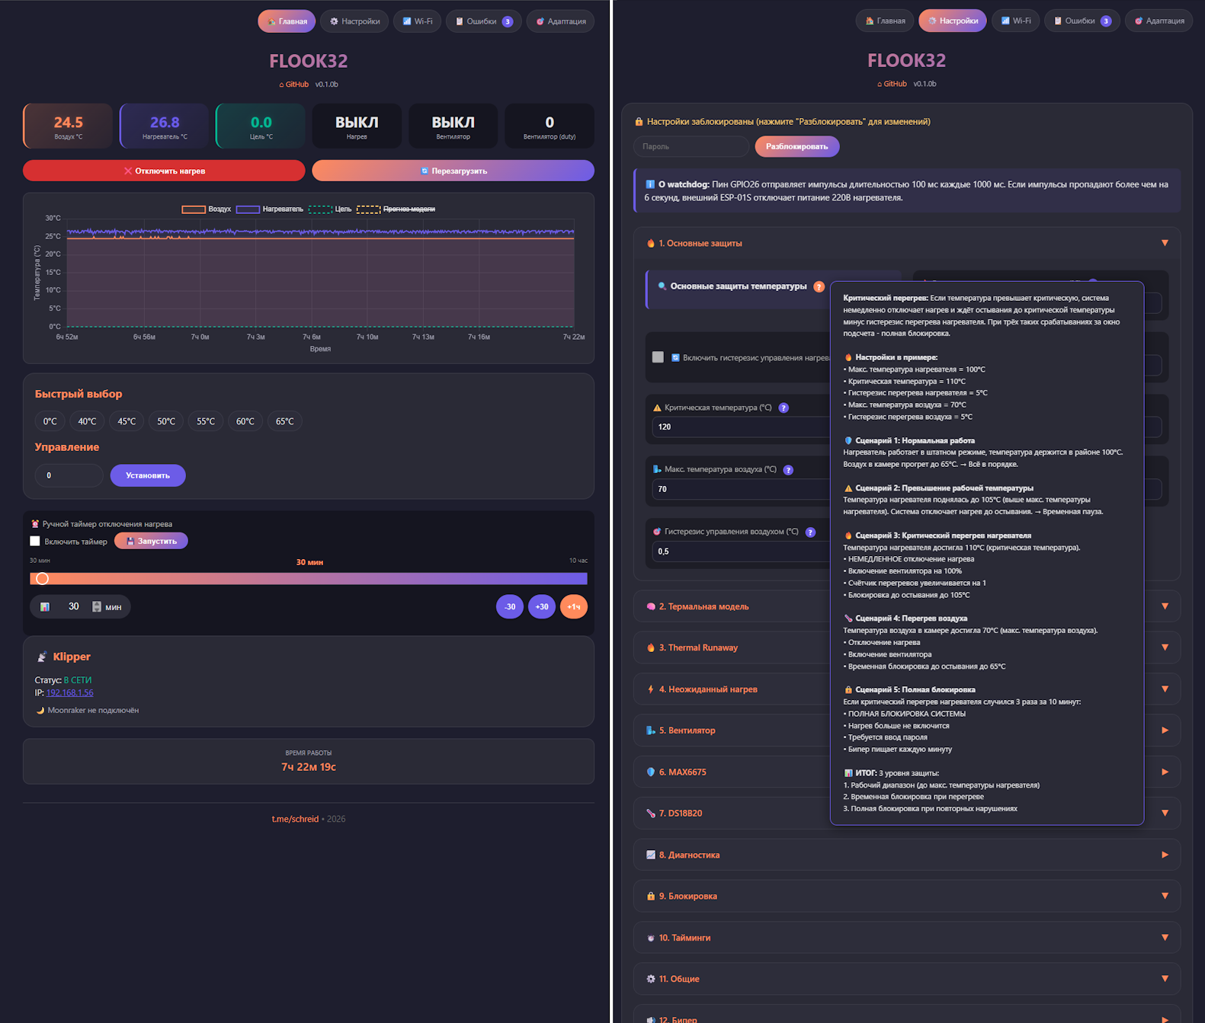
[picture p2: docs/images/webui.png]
Веб-интерфейс FLOOK32
  

[🔙 На главную](../README.md)

# Веб-интерфейс FLOOK32 — Полная документация

**Файл:** `firmware/flook32/src/index.html`  
**Тип:** Одностраничное приложение (SPA)  
**Размер:** ~1900 строк (HTML + CSS + JavaScript)  
**Зависимости:** Chart.js 3.9.1 + date-fns adapter (CDN)

---

## 🏗️ Архитектурный обзор

Веб-интерфейс работает полностью в браузере и общается с ESP32 по двум каналам:

```
┌──────────────────────────────────────────────┐
│ Браузер                                      │
│ ┌──────────┐  ┌──────────┐ ┌───────────────┐ │
│ │ HTML DOM │  │ Chart.js │ │ JS App Logic  │ │
│ └─────┬────┘  └────┬─────┘ └───────┬───────┘ │
│       │            │               │         │
│       └────────────┴───────────────┘         │
│                    │                         │
│        ┌───────────┴───────────┐             │
│        │ WebSocket   HTTP REST │             │
│        │ (основной) (запасной) │             │
│        └───────────┬───────────┘             │
└────────────────────┼─────────────────────────┘
                     │
                     │       HTTP REST
                     │     (внешний мир)
                     │
             ┌───────┴───────┐       ┌──────────────┐
             │     ESP32     │─────▶│  GitHub API  │
             │    FLOOK32    │       │  (релизы)    │
             └───────────────┘       └──────────────┘
```

| Канал | Протокол | Порт | Использование |
|---|---|---|---|
| **WebSocket** | `ws://[host]/ws` | 80 | Метрики реального времени, история графика, события блокировки |
| **HTTP REST** | `GET/POST /api/*` | 80 | Конфигурация, Wi-Fi, адаптация, OTA, проверка обновлений, fallback |

**Принцип работы:**  
WebSocket — основной канал для real-time данных.  
HTTP REST — для конфигурации и действий пользователя.  
При обрыве WebSocket интерфейс переключается на HTTP-опрос и параллельно пытается переподключиться с экспоненциальной задержкой.  
Для проверки обновлений ESP32 самостоятельно обращается к GitHub API через HTTP.

<details>
<summary>📁 DOM-дерево</summary>
  
```
.container
├── .nav-links
│   ├── .nav-link[data-screen="main"]
│   ├── .nav-link[data-screen="config"]
│   ├── .nav-link[data-screen="wifi"]
│   ├── .nav-link[data-screen="errors"]
│   │   └── .badge-container
│   │       ├── #badge-critical
│   │       ├── #badge-warning
│   │       └── #badge-info
│   └── .nav-link[data-screen="adapt"]
├── .flook-header
│   ├── h1
│   └── .header-info
├── #screen-main.screen.active
│   ├── #lockBanner
│   │   ├── #lockMessage
│   │   ├── #unlockPass
│   │   └── button (unlock)
│   ├── .metrics-grid (6 шт)
│   ├── #heaterOffBtn + button (reboot)
│   ├── .chart-container > #tempChart
│   ├── .card
│   │   ├── #presets > .preset[data-temp] (7 шт)
│   │   └── .temp-control > #tempInput + button
│   ├── .config-group (ручной таймер)
│   │   ├── #manualTimerEnable
│   │   ├── #manualTimerMinutes
│   │   ├── #manualTimerMinutesInput
│   │   ├── button.quick-btn (-30, +30, +1ч)
│   │   ├── button (сохранить)
│   │   └── #manualTimerStatus
│   ├── #thermalDiagnostics
│   │   ├── #modelConfidence + #confidenceFill
│   │   ├── #modelError
│   │   ├── #heaterRate
│   │   └── #coolingRate
│   ├── #klipperStatus
│   └── #uptime
├── #screen-config.screen
│   ├── #lockStatus + #unlockPassConfig + #unlockSettingsBtn + #lockSettingsBtn
│   ├── #dangerWarning
│   ├── #configGrid (15 секций)
│   │   └── .config-section#section-{id}
│   │       ├── .section-header
│   │       └── .section-content#content-{id}
│   ├── #saveConfigBtn + #resetDefaultsBtn
│   ├── #currentSettings
│   ├── #update-status + #update-progress-container
│   ├── #firmware-file + button (upload)
│   ├── #update-check-status + #check-update-btn
│   ├── #update-info > #latest-version + #release-notes + button (updateOTA)
│   ├── #calibTemp + button (calibrate)
│   ├── #thermalModelStatusText + button (reset model)
│   ├── #thermalModelNoAdaptationWarning
│   ├── #thermalWarning
│   ├── #thermalRunawayDisabledNote
│   ├── #unexpectedHeatDisabledNote
│   ├── #adaptationStatus
│   ├── #moonrakerAutoShutdown + #moonrakerShutdownMinutes
│   ├── #moonrakerSettingsStatus
│   ├── #fanAutoLimitStatus + #fanAutoLimitStatusText
│   ├── #watchdog-pin + #watchdog-pulse-ms + #watchdog-interval-ms
├── #screen-wifi.screen
│   ├── .wifi-status-item (SSID, IP, RSSI)
│   ├── #wifiScanBlock
│   │   ├── button (scan)
│   │   ├── #networksPanel > #networkSelect + #wifiPassword + button
│   │   └── #scanMessage
│   ├── #wifiResetBlock > button (reset)
│   └── #wifiResultCard > #resultIp + #resultSsid + button (goToIp)
├── #screen-errors.screen
│   ├── .filter-group > .filter-btn[data-filter] (4 шт)
│   ├── button (clear)
│   └── #errorList > .error-item > .error-header + .error-details
├── #screen-adapt.screen
│   ├── #adaptBlocked > #blockReason
│   ├── #adaptReady
│   │   ├── #adaptTarget + button (start)
│   │   └── #adaptStatusMessage
│   ├── #adaptProgress
│   │   ├── #progressAirTemp + #progressHeaterTemp + #progressTarget
│   │   ├── #adaptProgressFill
│   │   ├── #phaseIndicator
│   │   ├── #adaptStatus
│   │   └── button (abort)
│   ├── #adaptWaitingPanel > #continueAdaptBtn
│   ├── #adaptComplete
│   └── #adaptResults
│       ├── #basicResults
│       ├── #runawayResults
│       ├── #unexpectedResults
│       ├── #fanResults
│       ├── #max6675Results
│       ├── #airSensorResults
│       ├── #lockResults
│       ├── #timingResults
│       └── #fanAutoLimitResults
├── .footer
├── #offlineBanner
├── #disclaimerOverlay > .disclaimer-dialog > #disclaimerAcceptBtn + #disclaimerTimer
└── #dynamic-tooltip (создаётся динамически)
```
</details>

<details>
<summary>📁 Карта обработчиков событий</summary>

```
click .nav-link → showScreen(dataset.screen)
click .preset[data-temp] → setTargetTemp()
click #heaterOffBtn → heaterOff()
click reboot button → rebootAll()
click .temp-set-btn → setTargetTemp()

click button (unlock in #lockBanner) → unlockSystem()

click #unlockSettingsBtn → unlockSettings()
click #lockSettingsBtn → lockSettings()
click #saveConfigBtn → saveConfig()
click #resetDefaultsBtn → resetToDefaults()

click .section-header → toggleSection(id)
click .error-header → toggleErrorDetails()
click .filter-btn → renderErrors()
click clear errors → clearErrors()

click start adapt → startAdaptation()
click #continueAdaptBtn → continueAdaptation()
click abort adapt → abortAdaptation()

click scan wifi → scanNetworks()
click connect wifi → connectToNetwork()
click reset wifi → resetWiFi()
click goToIp → goToIp()

click calibrate → calibrateMAX6675()
click reset model → resetThermalModel()
click upload → uploadFirmware()
click #check-update-btn → checkForUpdates()
click #update-info button → updateOTA()

click save timer → saveManualTimer()
click .quick-btn → changeManualTimer()

click #disclaimerAcceptBtn → close overlay + scanNetworks()

input #manualTimerMinutes → syncManualTimerValue()
change #manualTimerMinutesInput → syncManualTimerValue()

mouseenter .help-icon → showTooltipWithDelay()
mouseleave .help-icon → hideTooltipWithDelay()
mouseenter #dynamic-tooltip → cancel hide
mouseleave #dynamic-tooltip → hideTooltipWithDelay()
click document → hideTooltipImmediately()
keydown document → hideTooltipImmediately()

beforeunload window → stopAdaptUpdates()

WebSocket open → сервер автоматически отправляет историю
WebSocket message → updateChartData() / updateUIFromWS()
WebSocket close → offline banner + reconnect
WebSocket error → console.error + reconnect

XHR progress → OTA progress bar
XHR load → OTA result

DOMContentLoaded → initChart() + connectWebSocket() + setInterval(...) + loadMainData() + disclaimer
```
</details>

<details>
<summary>📁 Карта функций — кто кого вызывает</summary>
  
```
setTargetTemp()
  └─> loadMainData()

heaterOff()
  └─> loadMainData()

unlockSystem()
  └─> location.reload()

unlockSettings()
  └─> loadConfig()

lockSettings()
  └─> loadConfig()

saveConfig()
  └─> loadConfig()

resetToDefaults()
  └─> loadConfig()

calibrateMAX6675()
  └─> loadConfig()

checkForUpdates()
  └─> fetch('/api/check-update')
  └─> updateOTA()

updateOTA()
  └─> fetch('/api/update-ota')

loadConfig()
  └─> updateConfigFields()
  └─> updateLockUI()
  └─> updateThermalModelWarnings()
  └─> updateWatchdogInfo()
  └─> restoreSectionStates()
  └─> loadThermalModelStatus()
  └─> loadMoonrakerSettings()
  └─> updateFanAutoLimitStatus()
  └─> initTooltips()

showScreen(id)
  ├─ main   └─> loadMainData() + chart.resize()
  ├─ config └─> loadAllConfigSections() + loadConfig()
  ├─ wifi   └─> loadWifiStatus()
  ├─ errors └─> loadErrors()
  └─ adapt  └─> checkAdaptStatus()

connectWebSocket()
  └─ onopen └─> сервер отправляет историю автоматически

updateUIFromWS(data)
  └─> document.getElementById().textContent (множество)
  └─> document.getElementById().classList (lockBanner)
  └─> document.getElementById().disabled (heaterOffBtn, tempInput)
  └─> document.querySelectorAll().style (presets)

updateChartData(data)
  └─ history_chunk └─> historyPoints.push()
  └─ when receivedChunks == expectedChunks └─> sort + distribute + chart.update()
  └─ history_update └─> datasets.push() + chart.update()

renderErrors()
  └─> updateErrorBadges()

checkAdaptStatus()
  └─> updatePhaseIndicator()
  └─> updateAdaptTemps()
  └─> startAdaptUpdates() / stopAdaptUpdates()

loadAllConfigSections()
  └─> loadConfig()
  └─> initTooltips()

saveManualTimer()
  └─> fetch('/api/manual-timer?enable=0/1&minutes=N')

saveMoonrakerSettings()
  └─> fetch('/api/moonraker-shutdown?enable=0/1&minutes=N')
```
</details>

<details>
<summary>📁 Схема потоков данных</summary>
  
```
WebSocket (message)
  ├─ type: metrics  ──> updateUIFromWS()      ──> DOM (метрики, lock, klipper, thermal)
  ├─ type: history_chunk ──> updateChartData() ──> chart (сборка чанков)
  └─ type: history_update ──> updateChartData() ──> chart (добавление точек)

HTTP GET /api/all
  └─> updateUIFromWS()                         ──> DOM (fallback)

HTTP GET /api/all (adapt active)
  └─> updateAdaptTemps()                       ──> #progress*Temp

HTTP GET /api/error-log
  ├─> renderErrors()                           ──> #errorList
  └─> updateErrorBadges()                      ──> #badge-* + document.title

HTTP GET /api/config
  └─> loadConfig()                             ──> #configGrid, #currentSettings, etc

HTTP GET /api/wifi/status
  └─> loadWifiStatus()                         ──> #wifiSsid, #wifiIp, #wifiRssi

HTTP GET /api/adapt/status
  └─> checkAdaptStatus()                       ──> #adaptProgressFill, #adaptStatus, #phaseIndicator

HTTP GET /api/check-update
  └─> checkForUpdates()                        ──> #update-info, #current-version

HTTP POST /api/update-ota
  └─> updateOTA()                              ──> #update-progress-container, #update-status

JS setInterval (1s)
  └─> updateManualTimerStatus()                ──> #manualTimerStatus

JS setInterval (5s)
  └─> loadMainData()                           ──> updateUIFromWS()

JS setInterval (5s)
  └─> loadWifiStatus()                         ──> #wifiSsid, #wifiIp, #wifiRssi

JS setInterval (10s)
  └─> loadThermalStatus()                      ──> #thermalModelStatusText, #thermalDiagnostics

JS setInterval (10s)
  └─> updateErrorBadges()                      ──> #badge-*, document.title

user action
  ├─ setTargetTemp()   ──> POST /api/target       ──> OK ──> loadMainData()
  ├─ heaterOff()       ──> POST /api/heater-off   ──> OK ──> loadMainData()
  ├─ saveConfig()      ──> POST /api/config       ──> OK ──> loadConfig()
  ├─ unlockSystem()    ──> POST /api/unlock       ──> success ──> reload()
  ├─ unlockSettings()  ──> POST /api/unlock-settings ──> success ──> loadConfig()
  ├─ connectToNetwork()──> POST /api/wifi/connect ──> IP ──> showWifiResult()
  ├─ checkForUpdates() ──> GET /api/check-update  ──> JSON ──> #update-info
  ├─ updateOTA()       ──> POST /api/update-ota   ──> success ──> reload()
  └─ uploadFirmware()  ──> POST /api/update       ──> XHR progress ──> #update-progress-bar
```
</details>

---

## 🔄 Жизненный цикл приложения

### 1. Загрузка страницы (DOMContentLoaded)

```
initChart()
  └─> Создание графика Chart.js с 4 датасетами

connectWebSocket()
  └─> ws://[host]/ws
      ├─ onopen → сервер начинает отправку истории (history_chunk)
      └─ onerror/onclose → запуск reconnect

loadMainData()
loadWifiStatus()
loadThermalStatus()
```
Интервалы:

```
setInterval(loadMainData, 5000)
setInterval(loadWifiStatus, 5000)
setInterval(loadThermalStatus, 10000)
```

Фоновый опрос ошибок (беджи) — каждые 10 секунд, **кроме случая, когда открыт экран ошибок**.

Восстановление состояния:

- последний экран (`sessionStorage`)
- свёрнутые секции настроек

---

### 2. Переключение экранов (`showScreen(id)`)

```
1. Скрыть все .screen
2. Показать screen-{id}
3. Обновить навигацию
4. Сохранить в sessionStorage
```

Загрузка данных:

```
main   → loadMainData() + chart.resize()
config → загрузка конфигурации (один раз)
wifi   → loadWifiStatus()
errors → loadErrors()
adapt  → checkAdaptStatus()
```

---

### 3. Разрушение (`beforeunload`)

- остановка адаптации (если активна)
- WebSocket закрывается браузером

---

## 📡 WebSocket протокол

### Подключение

```javascript
ws = new WebSocket(`ws://${window.location.hostname}/ws`)
```

---

### Сообщения сервер → клиент

#### Метрики (тип `metrics`)

```json
{
  "type": "metrics",
  "a": 45.2,
  "h": 89.7,
  "tg": 60.0,
  "hs": 1,
  "fs": 1,
  "fp": 512,
  "u": 3600,
  "systemLocked": 0,
  "lockMessage": "Причина блокировки",
  "klipper": {
    "detected": true,
    "ip": "192.168.1.100"
  },
  "md": true,
  "thermalEnabled": true,
  "thermal": {
    "confidence": 85,
    "error": 2.1,
    "heaterRate": 12.5,
    "coolingRate": 0.05
  }
}
```

<details>
<summary>📁 Спецификация полей metrics</summary>

| Поле | Тип | Диапазон | Описание |
|---|-----|---|---|
| `type` | string | `"metrics"` | Идентификатор типа сообщения |
| `a` | float | °C | Текущая температура воздуха в камере (DS18B20) |
| `h` | float | °C | Текущая температура нагревателя (MAX6675) |
| `tg` | float | °C | Заданная целевая температура |
| `hs` | int | 0 или 1 | Состояние нагревателя (1 = включён, 0 = выключен) |
| `fs` | int | 0 или 1 | Состояние вентилятора (1 = включён, 0 = выключен) |
| `fp` | int | 0–1023 | Текущий ШИМ-сигнал вентилятора (duty cycle) |
| `u` | int | секунды | Время непрерывной работы ESP32 (uptime) |
| `systemLocked` | int | 0 или 1 | Флаг полной системной блокировки (1 = заблокирована) |
| `lockMessage` | string | — | Человекочитаемая причина блокировки |
| `klipper.detected` | bool | — | Обнаружен ли Klipper в локальной сети |
| `klipper.ip` | string | — | IP-адрес хоста с Klipper/Moonraker |
| `md` | bool | — | Обнаружен ли Moonraker API |
| `thermalEnabled` | bool | — | Активирована ли обучаемая термальная модель |
| `thermal.confidence` | int | 0–100 | Уверенность модели в прогнозе (проценты) |
| `thermal.error` | float | °C | Текущее отклонение прогноза модели от факта |
| `thermal.heaterRate` | float | °C/мин | Измеренная скорость нагрева нагревателя |
| `thermal.coolingRate` | float | °C/сек | Измеренная скорость остывания с вентилятором |

</details>

---

#### Загрузка истории (тип `history_chunk`)

```json
{
  "type": "history_chunk",
  "chunk": 0,
  "total": 10,
  "data": [
    {
      "t": 123456789,
      "a": 45.2,
      "h": 89.7,
      "tg": 60.0,
      "pred": 61.5
    }
  ]
}
```

- `chunk` – индекс текущего фрагмента (начиная с 0)
- `total` – общее количество фрагментов
- `data` – массив точек; каждая точка содержит:
  - `t` – миллисекундный timestamp
  - `a` – температура воздуха
  - `h` – температура нагревателя
  - `tg` – целевая температура
  - `pred` – прогноз модели (может отсутствовать)

Клиент собирает все точки из последовательных чанков. Когда `receivedChunks === expectedChunks`, данные сортируются по `t` и отображаются на графике.

---

#### Обновление в реальном времени (тип `history_update`)

```json
{
  "type": "history_update",
  "data": [
    {
      "t": 123456789,
      "a": 46.1,
      "h": 91.2,
      "tg": 60.0,
      "pred": 62.0
    }
  ]
}
```
Структура точек та же, что и в `history_chunk`. Данные добавляются к существующим датасетам без полной перерисовки.

---

### Команды клиент → сервер

В текущей реализации клиент **не отправляет** никаких команд для запроса истории. Сервер автоматически отправляет накопленную историю сразу после установки WebSocket-соединения. Команда `get_history` зарезервирована, но не используется.

---

### Reconnect логика

```javascript
const WS = {
    MAX_RECONNECT_DELAY: 30000,
    BASE_RECONNECT_DELAY: 3000
};

delay = Math.min(BASE_RECONNECT_DELAY * wsReconnectAttempts, MAX_RECONNECT_DELAY);
```

---

## 🌐 REST API

### Метрики

| Метод | Endpoint | Описание |
|---|---|---|
| GET | `/api/all` | Все метрики (та же структура, что и WS-сообщение `metrics`) |
| GET | `/api/uptime` | Аптайм в секундах |
| POST | `/api/target?value=N` | Установка целевой температуры |
| POST | `/api/heater-off` | Аварийное отключение нагревателя |
| POST | `/api/unlock?password=X` | Разблокировка системы после полной блокировки |
| POST | `/api/reboot-all` | Полная перезагрузка ESP32 |

### Конфигурация

| Метод | Endpoint | Параметры | Возвращает | Использование |
|---|---|---|---|---|
| GET | `/api/config` | — | Компактный JSON конфигурации | Загрузка всех настроек |
| POST | `/api/config` | JSON (body) | `"OK"` / `"OK_RESTART"` | Сохранение |
| POST | `/api/config/defaults` | — | `"OK"` | Сброс к заводским настройкам |
| POST | `/api/unlock-settings?password=X` | password | `"Settings unlocked"` или `{"success":true}` | Разблокировка настроек |
| POST | `/api/lock-settings` | — | `"OK"` | Блокировка настроек |

---

### Калибровка

| Метод | Endpoint | Параметры | Возвращает | Использование |
|---|---|---|---|---|
| POST | `/api/calibrate-max6675?temp=N` | temp (эталонная температура) | `{"success": true, "offset": 2.5}` | Калибровка датчика MAX6675 |

---

### Термальная модель

| Метод | Endpoint | Параметры | Возвращает | Использование |
|---|---|---|---|---|
| POST | `/api/thermal-model/reset` | — | `"Thermal model reset to adaptation data"` | Сброс модели к данным адаптации |

---

### Таймеры

| Метод | Endpoint | Параметры | Возвращает | Использование |
|---|---|---|---|---|
| POST | `/api/manual-timer?enable=0` | — | `"OK"` | Выключение ручного таймера |
| POST | `/api/manual-timer?enable=1&minutes=N` | minutes | `"OK"` | Запуск ручного таймера |
| POST | `/api/moonraker-shutdown?enable=0` | — | `{"success": true}` | Отключение автоотключения |
| POST | `/api/moonraker-shutdown?enable=1&minutes=N` | minutes | `{"success": true}` | Включение автоотключения |

**Примечание:**
- Ручной таймер: одна и та же кнопка «Запустить» отправляет `enable=1&minutes=N`, если чекбокс включён, либо `enable=0`, если выключен.
- Moonraker автоотключение: постоянный фоновый опрос не выполняется; настройки загружаются один раз при старте и при открытии экрана настроек.

---

### Wi-Fi

| Метод | Endpoint | Параметры | Возвращает | Использование |
|---|---|---|---|---|
| GET | `/api/wifi/status` | — | `{ssid, ip, rssi}` | Текущий статус подключения |
| GET | `/api/wifi/scan` | — | `{networks: [{ssid, rssi}, ...]}` | Сканирование доступных сетей |
| POST | `/api/wifi/connect` | ssid, password (query params) | `{success: true, ip: "x.x.x.x"}` | Подключение к выбранной сети |
| POST | `/api/wifi/reset` | — | `"OK"` | Сброс настроек Wi-Fi и переход в режим точки доступа |

---
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

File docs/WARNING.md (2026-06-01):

[🔙 На главную](../README.md)

# ⚠️ Предупреждение о безопасности

## Высокое напряжение

Устройство FLOOK32 управляет нагревателем, работающим от сети **220 вольт**. Это напряжение
**опасно для жизни**. Несоблюдение правил безопасности может привести к:
- Поражению электрическим током
- Возгоранию
- Повреждению оборудования

## Правила безопасности

### Перед началом работы
- Убедитесь, что все соединения надёжно изолированы
- Используйте провода с сечением, соответствующим мощности нагревателя
- Проверьте целостность изоляции всех кабелей
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

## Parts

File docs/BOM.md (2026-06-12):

[🔙 На главную](../README.md)

# 📦 BOM (Bill of Materials) — актуальный список компонентов

> 💡 **Ссылки ведут на примеры с AliExpress / продавцов.** Аналоги можно найти у любых продавцов, главное — соблюдать характеристики.

### Электроника

| Компонент | Характеристики | Кол-во | Примерная цена (≈) | Назначение | Обязательность | Ссылка |
|---|---|---|:---:|---|:---:|---|
| ESP32 | USB-C, 30 pin | 1 | 300р | Основной контроллер | Обязательно | [Купить](https://ali.click/q41me16) |
| MAX6675 | SPI модуль | 1 | 200р | Датчик температуры нагревателя | Обязательно | [Купить](https://ali.click/02pq71h) |
| Термопара K-типа | 3x10/15 мм, 1 метр | 1м | 150р | Датчик температуры нагревателя | Обязательно | [Купить](https://ali.click/r3pq71m) |
| DS18B20 | Модуль + датчик 1м | 1 | 150р | Датчик температуры воздуха | Обязательно | [Купить](https://ali.click/25pq715) |
| SSR G3MB-202P | 2А, 240В AC, High Level | 1 | 150р | Твердотельное реле (220В) | Обязательно | [Купить](https://ali.click/y6pq71y) |
| SSR-10DA | 10А, 240В AC | 1 | 300р | Твердотельное реле (220В) | Опционально | [Купить](https://ali.click/h8pq715) |
| MOSFET LR7843 | N-канал, 30V, 161A | 1 | 50р | ШИМ-управление вентилятором (12В) | Обязательно | [Купить](https://ali.click/k9pq71z) |
| ESP01S + релейный модуль | Реле-модуль рекомендуется V4.0 | 1 | 250р | Аппаратный watchdog | Рекомендуется | [Купить](https://ali.click/3bpq71e) |
| Бипер KY-012 | Активный зуммер, 5V | 1 | 50р | Звуковая индикация | Опционально | [Купить](https://ali.click/acpq71p) |
| LED лента WS2812B | Адресная RGB | 5 см | 10р | Светодиодная индикация | Опционально | [Купить](https://ali.click/depq71a) |
| Вентилятор 7530 | 12V, XH2.54 2pin | 1 | 550р | Внутренний модуль | Обязательно | [Купить](https://ali.click/mfpq718) |
| Нагреватель 220В | 150Вт, 95x31 мм, PTC | 1 | 500р | Внутренний модуль | Обязательно | [Купить](https://ali.click/ohpq71d) |
| LED-лента 12В | Любая, 5 см | 5 см | 5р | Подсветка логотипа | Опционально | [Купить](https://ozon.ru/t/7WO8ejz) |
| KSD9700 | 5А-NC 130°C | 1 | 80р | Защита нагревателя | Рекомендуется | [Купить](https://ali.click/t5cr71w) |

### Питание и коммутация

| Компонент | Характеристики | Кол-во | Примерная цена (≈) | Назначение | Обязательность | Ссылка |
|---|---|---|:---:|---|:---:|---|
| БП 5В/2A S15W10E | 220В → 5В, 2A | 1 | 150р | Питание ESP32 и периферии | Обязательно | [Купить](https://ali.click/8jpq719) |
| БП 12В/1A S15W10E | 220В → 12В, 1A | 1 | 150р | Питание MOSFET и вентилятора | Обязательно | [Купить](https://ali.click/wjpq71y) |
| 40pin прямой разъем папа 2.54 | 2.54mm | 1 | 5р | Шина 5В | Обязательно | [Купить](https://ali.click/5tpq71v) |
| 40pin угловой разъем папа 2.54 | 2.54mm | 1 | 5р | ESP01S GPIO2 | Опционально | [Купить](https://ali.click/5tpq71v) |
| Разъём IEC C8 | Восьмёрка, на панель | 1 | 15р | Вход 220В на корпусе | Обязательно | [Купить](https://ali.click/mlpq71z) |
| Кнопка KCD11 | 2-позиционная, 3A/250В | 1 | 10р | Разрыв нейтрали 220В | Обязательно | [Купить](https://ali.click/enpq714) |
| Кнопка KCD4 | 2-позиционная, 30A/250В | 1 | 100р | Разрыв нейтрали 220В | Обязательно для SSR-10DA | [Купить](https://ali.click/mc2me17) |
| WAGO 221-415 или аналоги в размер | 5-проводный, 32А | 2 | 100р | Шина 220В | Обязательно | [Купить](https://ozon.ru/t/Gcth3p3) |
| Кнопка тактовая | 6x6x4.3 мм | 1 | 2р | Сброс к заводским настройкам | Опционально | [Купить](https://ali.click/3qpq712) |
| Кабель сетевой с вилкой | В зависимости от нагрузки | 1 | 100р | Подключение 220В | Обязательно для SSR-10DA | [Купить](https://ozon.ru/t/d7tPK0V) |

### Соединения

| Компонент | Характеристики | Кол-во | Примерная цена (≈) | Назначение | Обязательность | Ссылка |
|---|---|---|:---:|---|:---:|---|
| Провод 20 AWG | ≥2 цвета | Набор | 100р | Внутренний монтаж, силовые линии 220В, линия 12В | Обязательно | [Купить](https://ali.click/uvpq71m) |
| Провод ПуГВ 0.5² | ≥2 цвета, ≥4метра  | Набор | 100р | Внешний монтаж, силовые линии 220В, линия 12В | Опционально | [Купить](https://www.vseinstrumenti.ru/category/provod-ustanovochnyj-pugv-16478) |
| НШВИ 0.5-8 | Гильзы 0.5mm² | 20 шт | 6р | Оконцевание проводов | Обязательно | [Купить](https://ozon.ru/t/sSPntfw) |
| Dupont провода | Мама-мама, 26 AWG | 25 шт | 150р | Низковольтные линии | Обязательно | [Купить](https://ali.click/mdqq71w) |
| Клеммы с проводом JST XH2.54 | 22AWG, single head, два цвета | 6 шт | 14р | Быстроразъёмные соединения | Опционально | [Купить](https://ali.click/x8sq717) |
| Пластик мама JST XH2.54 | 2 pin | 3 шт | 4р | БП, вентилятор | Опционально | [Купить](https://ali.click/jisq71d) |
| Пластик папа JST XH2.54 | 2 pin прямой | 2 шт | 3р | Вентилятор | Обязательно | [Купить](https://ali.click/7ksq714) |
| Пластик папа JST XH2.54 | 2 pin угловой | 2 шт | 3р | БП | Обязательно | [Купить](https://ali.click/4t5me1t) |
| Готовые провода с коннекторами XH2.54 2pin | 22AWG, 2 pin | 5 шт | 125р | Вентилятор, БП | Опционально | [Купить](https://ali.click/ar3l813) |
### Метизы и оснастка

| Компонент | Характеристики | Кол-во | Примерная цена (≈) | Назначение | Обязательность | Ссылка |
|---|---|---|:---:|---|:---:|---|
| Винт M3×8 | DIN912 / DIN7985 | 4 шт | 3р |  C8, нагреватель | Обязательно | [Купить](https://ozon.ru/t/Uycfkg0) |
| Винт M3×5 | DIN912 / DIN7985 | 2 шт | 2р | ESP | Обязательно | [Купить](https://ozon.ru/t/Uycfkg0) |
| Винт M3×5 V | DIN965 / DIN7991 | 10 шт | 10р | Крышки, ESP01S реле | Обязательно | [Купить](https://ozon.ru/t/jQ4Ky9q) |
| Винт M3×35 V | DIN965 / DIN7991 | 2 шт | 3р | Вентилятор | Обязательно | [Купить](https://ozon.ru/t/91zqEDj) |
| Гайка M3 | DIN934 | 2 шт | 2р | Нагреватель | Обязательно | [Купить](https://ozon.ru/t/d7m29E0) |
| Втулки резьбовые M3 | ∅4.6×4 мм | 20 шт | 30р | Корпусы, C8 | Обязательно | [Купить](https://ali.click/r24r714) |
| Магниты 10×3 | Круглые | 12 шт | 100р | Корпусы | Опционально | [Купить](https://ozon.ru/t/d7mayeR) |
| Стяжки кабельные | 100×2.5 мм | 10 шт | 5р | Организация проводов | Опционально | [Купить](https://ozon.ru/t/Qiz5iCM) |
| Термоусадка ∅3 мм | 2:1 | 20 см | 6р | Изоляция паяных соединений | Обязательно | [Купить](https://ali.click/ouwq711) |
| Термоусадка ∅6 мм | 2:1 | 20 см | 8р | Изоляция паяных соединений | Обязательно | [Купить](https://ali.click/6wwq71h) |
| ЛСЭП-934 лента | — | 10 см | 2р | Изоляция термопары | Обязательно (!!) | [Купить](https://market.yandex.ru/cc/9SXUDz) |
| Гофра ∅6.6 мм | Автомобильная разрезная | 1 м | 30р | Кабельный ввод | Опционально | [Купить](https://ozon.ru/t/3hHQo8k) |
| Гофра ∅8.5 мм | Автомобильная разрезная | 1 м | 30р | Кабельный ввод | Опционально | [Купить](https://ozon.ru/t/lw52EWd) |
| Кабель питания C7 | CEE 7/16-C7, 2×0.75mm², 2.5А | 1 м+ | 160р | Питание 220В | Обязательно | [Купить](https://ozon.ru/t/d7mmGHz) |
| Клей B7000 | — | 1 шт | — | Кнопка тактовая, шина 5В, WAGO 221-415 | Обязательно | [Купить](https://ozon.ru/t/wGMAjhT) |
| НВИ 1.25-3 | Вилочный наконечник, изолированный | 2 шт | — | SSR-10DA | Опционально | [Купить](https://ozon.ru/t/sSPKfCY) |
| НВИ 2-4 | Вилочный наконечник, изолированный | 2 шт | — | SSR-10DA | Опционально | [Купить](https://ozon.ru/t/wGUO9k4) |
| РП гнездо 3.8 | — | 2 шт | — | KCD11 | Опционально | [Купить](https://ozon.ru/t/3h2a4bp) |
| РП гнездо 2.8 | — | 2 шт | — | С8 | Опционально | [Купить](https://ozon.ru/t/Qiz8IeK) |

### Печать

| Компонент | Характеристики | Кол-во | Примерная цена (≈) | Назначение | Обязательность | Ссылка |
|---|---|---|:---:|---|:---:|---|
| PETG/ABS пластик | 2 цвета (основной + белый) | 250 г | 250р | Внешний модуль | Обязательно | [Купить](https://ozon.ru/t/91HTwme) |
| ABS/PP/Nylon/PC, композиты на их основе | Термостойкий | 150 г | 300р | Внутренний модуль | Обязательно | [Купить](https://ozon.ru/t/fI4LZdO) |

### Инструменты

| Компонент | Характеристики | Кол-во | Примерная цена (≈) | Назначение | Обязательность | Ссылка |
|---|---|---|:---:|---|:---:|---|
| CH340C USB | USB | 1 | 100р | Прошивка ESP01S | Рекомендуется | [Купить](https://ali.click/2lri81t) |
| Обжим для Dupont/НВИ/РП | SN-28B/48B/58B/68B/SN-2549 | 1 | 1500р | Dupont, НВИ, XH2.54, РП | Опционально | [Купить](https://ali.click/17yi91p) |
| HSC8 | — | 1 | 600р | Обжим НШВИ | Обязательно | [Купить](https://ali.click/69yi91o) |
| Стриппер | AWG 30-8 | 1 | 1400р | Снятие изоляции | Опционально | [Купить](https://ali.click/fayi91j) |
| Паяльник | SH72 BC2 | 1 | 1000р | KCD11, C8, БП | Обязательно | [Купить](https://ozon.ru/t/zMNEgrs) |
| Мультиметр | Любой | 1 | 800р | Проверка БП 5/12В | Опционально | [Купить](https://www.ozon.ru/category/multimetry-i-testery-10080) |
| Зажигалка | турбо/автоген/горелка | 1 | 1000р | Для термоусадки | Опционально | [Купить](https://www.ozon.ru/category/zazhigalki-i-aksessuary-35663/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зажигалка+турбо) |
| Отвертки/ключи | — | 1 | — | Метизы | Обязательно | — |

> ⚠️ Ссылки приведены для примера. Актуальность цен и наличие проверяйте перед покупкой.

---

## 💰 Сводка по категориям (комплектующие для 1 устройства, без учёта инструментов)

| Категория | Примерная стоимость (≈) |
| :--- | :--- |
| **Электроника** | **2 795 ₽** |
| **Питание и коммутация** | **547 ₽** |
| **Соединения** | **409 ₽** |
| **Метизы и оснастка** | **496 ₽** |
| **Печать (пластик)** | **550 ₽** |

---

## 📊 **Итоговая вилка:**

> ### 🎯 **2 500 – 5 000 ₽** — материалы на одно устройство

> *Инструменты в стоимость устройства не включены — это разовая инвестиция.*

---

## 💡 На чём можно сэкономить, а на чём — нет

Проект допускает некоторую оптимизацию бюджета без потери безопасности и функциональности. Вот основные моменты.

### ✅ Экономить — можно (без потери качества)

| Компонент | Как сэкономить | Важно |
| :--- | :--- | :--- |
| **Вентилятор 7530** | Найти дешевле (250–350₽) | ❗ **Только на шарикоподшипниках** — скользящие быстро умрут в нагретой камере |
| **Провода** | Использовать ПВХ/ПВС вместо силикона | Дешевле по умолчанию. Силикон удобнее в монтаже, но механически слабее — его лучше укладывать в гофру, особенно для 220В. ПВХ прочнее, но менее гибкий |
| **Гофра** | Отказаться, если используете ПВХ/ПВС провода | Гофра нужна в основном для силикона. ПВХ можно прокладывать без неё |
| **Винты и гайки** | Самые дешёвые, любые | В проекте нет подвижных частей. Держать будут любые. Для всех мест (кроме вентилятора) можно взять один типоразмер — потай DIN965 M3×8 |
| **WAGO** | Купить неоригинал | На маркетплейсах в основном «паль». Держит нагрузку 3А с запасом — для проекта достаточно |
| **LED-ленты** | Полностью отказаться | WS2812B для индикации и 12В для подсветки логотипа — не обязательны. Если не брать — белый PETG тоже не нужен |
| **Соединения** | Заменить клеммы и разъёмы на прямую пайку | Дешевле, но **сильно неудобнее** в монтаже и ремонте |

### ❌ Экономить — не стоит

| Компонент | Почему |
| :--- | :--- |
| **MAX6675 + термопара** | Можно взять комплектом (дешевле), но короткая термопара (50 см) часто не дотягивается до камеры. Лучше купить раздельно — 1 метр |
| **Термостат KSD9700** | Формально опционален. **Я бы ставил** — это железная защита нагревателя от перегрева, которую не сломает прошивка |
| **Лента ЛСЭП-934** | ⚠️ **Обязательна.** Термопара и её металлическая оплётка находятся под напряжением 220В. Без изоляции — убитый MAX6675, ESP32 и риск удара током. |

> 🛑 **Без ЛСЭП-934 или любой другой изоляции, которая держит нагрев, не запускайте устройство.** Это не экономия, это выход из строя и угроза безопасности.

### ⚠️ Компромиссные варианты

| Ситуация | Решение |
| :--- | :--- |
| **Хочется дёшево и без гофры** | Берите провода ПВХ/ПВС, гофра не нужна. Дешевле, жёстче, но надёжнее с точки зрения механики |
| **Хочется удобно собирать** | Берите силикон. В корпусе с ним работать одно удовольствие. Но на выходе из корпуса — в гофру, чтобы не перетереть об острые края, а лучше на выход использовать ПВХ/ПВС |

[🔝 Наверх](#-bom-bill-of-materials--актуальный-список-компонентов)

---

[🔙 На главную](../README.md)

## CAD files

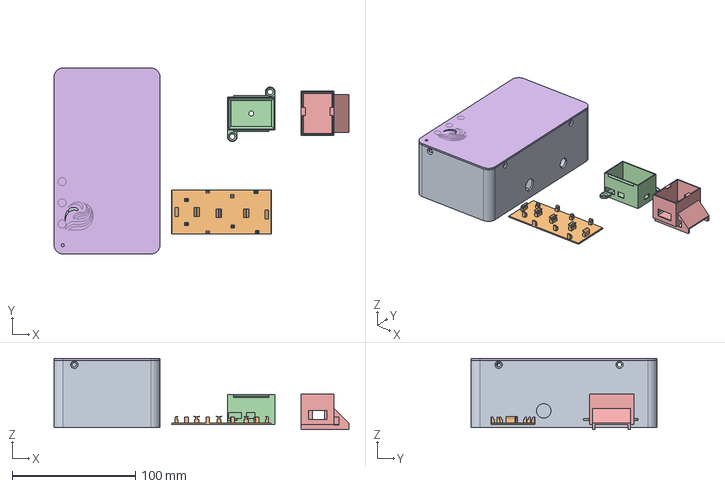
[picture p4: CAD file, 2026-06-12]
hardware/enclosure/flook32_external_da_v2.step
239.6 x 151.1 x 57.8 mm

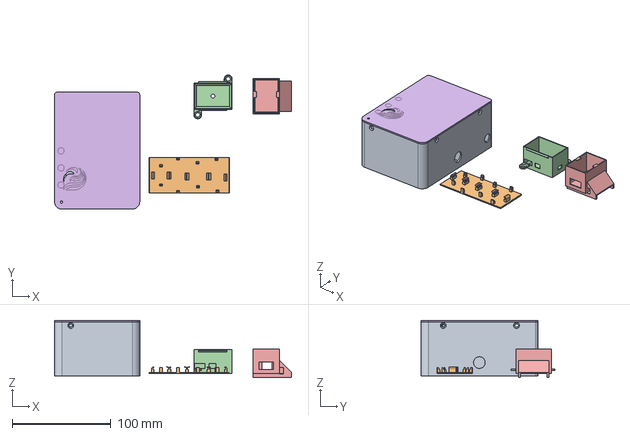
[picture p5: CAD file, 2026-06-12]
hardware/enclosure/flook32_external_g3mb_v2.step
239.6 x 135.6 x 57.8 mm

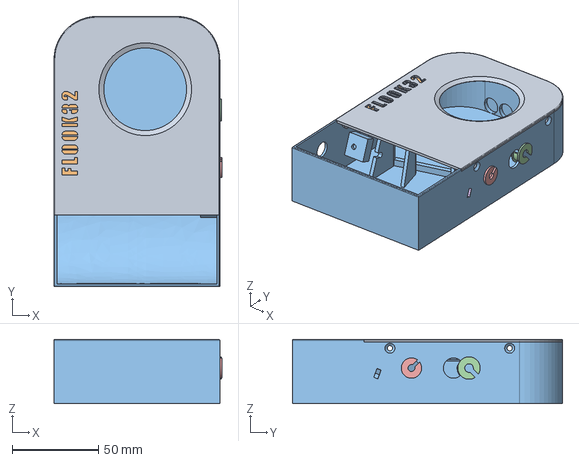
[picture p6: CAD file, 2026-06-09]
hardware/enclosure/flook32_eternal_v2.step
97.5 x 156.8 x 37.2 mm

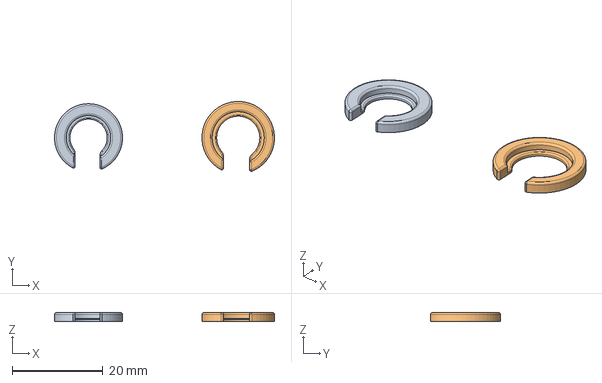
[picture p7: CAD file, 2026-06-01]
hardware/enclosure/flook32_pipe_clamp.step
48.5 x 15.4 x 2.00 mm

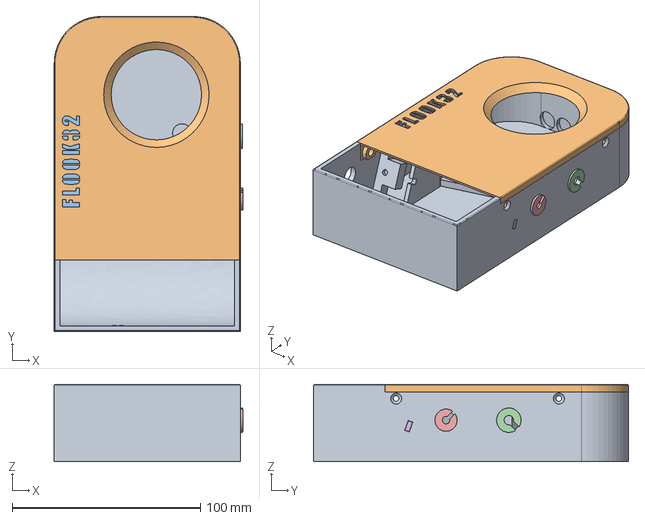
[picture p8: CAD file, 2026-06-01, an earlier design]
hardware/enclosure/archive/flook32_eternal_v1.step
100.3 x 167.5 x 41.0 mm

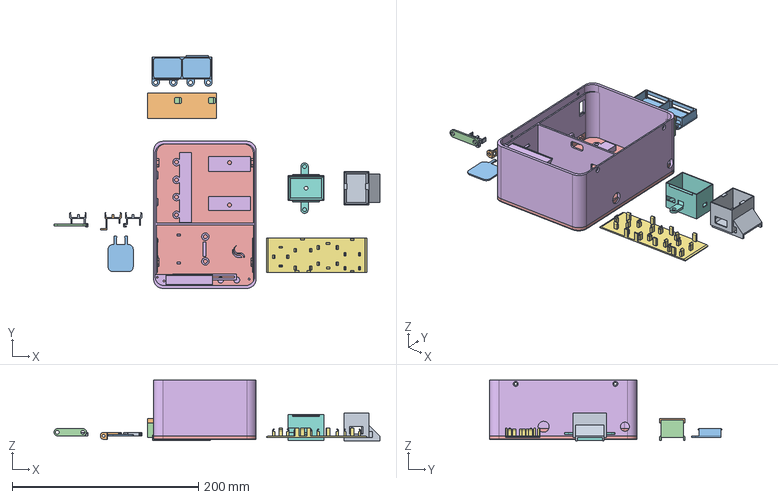
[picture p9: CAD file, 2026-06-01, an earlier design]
hardware/enclosure/archive/flook32_external_v1.step
350.0 x 249.9 x 65.2 mm

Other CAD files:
hardware/enclosure/archive/flook32_eternal_v1.f3d
hardware/enclosure/flook32_eternal_v2.3mf
hardware/enclosure/flook32_eternal_v2.f3d
hardware/enclosure/flook32_external_da_v2.3mf
hardware/enclosure/flook32_external_da_v2.f3z
hardware/enclosure/flook32_external_g3mb_v2.3mf
hardware/enclosure/flook32_pipe_clamp.f3d

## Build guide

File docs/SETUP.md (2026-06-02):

[🔙 На главную](../README.md)

# Установка и прошивка FLOOK32

## 📋 Содержание

- [Быстрая прошивка (Windows)](#0--быстрая-прошивка-windows)
- [Быстрая прошивка (Linux/macOS)](#0linux-быстрая-прошивка-linuxmacos)
- [Прошивка ESP32](#1-прошивка-esp32)
- [Первый запуск](#2-первый-запуск)

---

## 0. 🚀 Быстрая прошивка

### 0.1 Windows

Если Вы не хотите разбираться в Arduino IDE, воспользуйтесь готовым скриптом из папки `tools/`:

1. Скачайте скрипт прошивки из репозитория: [flash_flook32.bat](../tools/flash_flook32.bat)
2. Подключите ESP32 к компьютеру по USB
3. Запустите скрипт двойным щелчком

Скрипт сам скачает `esptool.exe`, загрузит актуальную прошивку из релиза и прошьёт устройство. Никаких дополнительных действий не требуется.

> 💡 **Совет:** если скрипт не может найти ESP32:
> - Переведите плату в режим загрузки: зажмите **BOOT**, нажмите и отпустите **EN**, затем отпустите **BOOT**
> - Убедитесь, что установлен драйвер CH340/CP210x ([скачать драйвер CH340](https://www.wch.cn/downloads/CH341SER_EXE.html))
> - Используйте USB-кабель с передачей данных (не только для зарядки)
> - Используйте основные USB-порты на ПК, не используйте USB-хабы. 

### 0.2 🐧 Linux/macOS

Для Linux и macOS используйте bash-скрипт:

1. Скачайте скрипт прошивки из репозитория: [flash_flook32.sh](../tools/flash_flook32.sh)
2. Подключите ESP32 к компьютеру по USB
3. Сделайте скрипт исполняемым и запустите:
   ```bash
   chmod +x tools/flash_flook32.sh
   ./tools/flash_flook32.sh
   ```

Скрипт установит `esptool.py` через pip, скачает прошивку и прошьёт устройство.

> 💡 **Совет:** если скрипт не может найти ESP32:
> - Проверьте права доступа к порту: `sudo usermod -a -G dialout $USER` (Linux)
> - На macOS драйверы CH340/CP210x встроены в систему
> - Переведите плату в режим загрузки: зажмите **BOOT**, нажмите и отпустите **EN**, затем отпустите **BOOT**
> - Проверьте, что порт виден в системе: `ls /dev/ttyUSB* /dev/ttyACM* /dev/cu.*`

---

## 1. Прошивка ESP32

### 1.1 Установка Arduino IDE

1. Скачайте и установите [Arduino IDE](https://www.arduino.cc/en/software)
2. Откройте Arduino IDE

### 1.2 Добавление поддержки ESP32

1. **Файл → Настройки** → в поле **Дополнительные ссылки для менеджера плат** вставьте:
   ```
   https://raw.githubusercontent.com/espressif/arduino-esp32/gh-pages/package_esp32_index.json
   ```
2. **Инструменты → Плата → Менеджер плат** → найдите **ESP32** → установите

### 1.3 Установка библиотек

**Скетч → Подключить библиотеку → Менеджер библиотек** → установите:

| Библиотека | Автор | Назначение |
|---|---|---|
| Adafruit NeoPixel | Adafruit | LED лента WS2812B |
| OneWire | Jim Studt, Tom Polland, Robin James | Шина для DS18B20 |
| DallasTemperature | Miles Burton | Датчик DS18B20 |
| ArduinoJson | Benoit Blanchon | Парсинг JSON |
| ESPAsyncWebServer | ESP32Async | Веб-сервер |
| AsyncTCP | ESP32Async | Асинхронный TCP |

### 1.4 Компиляция и загрузка

1. Скачайте [архив проекта](https://github.com/schreider/flook32) и распакуйте
2. Откройте `firmware/flook32/flook32.ino` в Arduino IDE
3. **Инструменты → Плата → ESP32 → ESP32 Dev Module**
4. **Инструменты → Порт** → выберите порт (`COMx` на Windows, `/dev/ttyUSB0` на Linux)
5. **Инструменты → Partition Scheme → Minimal SPIFFS (1.9MB APP with OTA/190KB SPIFFS)**

   <details>
   <summary>❓ Почему именно эта схема разделов?</summary>

   - **Два раздела приложений** `app0` и `app1` нужны для OTA-обновлений без проводов
   - **1.9 МБ на раздел** — достаточно для всей прошивки с запасом на доработки
   - **SPIFFS почти не используется** — конфигурация в NVS (Preferences), веб-интерфейс в PROGMEM
   - Схема работает на ESP32 с 8 и 16 МБ флеша без изменений в коде

   **Почему веб-интерфейс в PROGMEM, а не в файловой системе?**

   - **Мгновенная отдача** — без пауз на сборку мусора и поиск файла в SPIFFS
   - **Защита от сбоев питания** — PROGMEM это часть прошивки, не меняется во время работы
   - **Экономия RAM** — HTML лежит во Flash и не фрагментирует кучу
   - **Атомарные обновления** — интерфейс и API всегда одной версии
   - **Никаких лишних шагов** — открыл проект, нажал «Загрузить», всё готово
   </details>

6. Нажмите **Загрузить** (стрелка вправо)

### 1.5 Самостоятельная сборка веб-ресурсов

Готовые скрипты в папке `firmware/flook32/` делают всё автоматически:

- Скачивают недостающие исходники (`index.html`, `favicon.ico`, `icon_192.png`) из репозитория
- Скачивают актуальные версии **Chart.js** и **адаптера** с CDN
- Сжимают все ресурсы в GZIP
- Создают `.h` файлы для прошивки

| Исходник | Результат | Когда пересобирать |
|---|---|---|
| `src/index.html` | `index_html_gz.h` | При изменении веб-интерфейса |
| `src/favicon.ico` | `favicon_ico.h` | При замене иконки браузера |
| `src/icon_192.png` | `icon_192_png_gz.h` | При замене иконки для смартфонов |
| Chart.js (CDN) | `chart_min_js_gz.h` | Автоматически при каждом запуске |
| Адаптер (CDN) | `chartjs_adapter_gz.h` | Автоматически при каждом запуске |

**Запуск:**

- **Linux/macOS:** `./compress_webui.sh`
- **Windows:** двойной щелчок по `compress_webui.bat`

После выполнения скрипта перекомпилируйте прошивку.

---

## 2. Первый запуск

### 2.1 Подключение к точке доступа

1. После прошивки ESP32 создаст точку доступа:
   - **SSID:** `FLOOK32-XXXX` (XXXX — ID устройства)
   - **Пароль:** `flook1234`
2. Подключитесь к этой сети с телефона или компьютера
3. Откройте браузер → `http://192.168.4.1`

### 2.2 Настройка Wi-Fi

1. В веб-интерфейсе откроется вкладка **Wi-Fi**
2. Дождитесь автоматического сканирования сетей
3. Выберите свою домашнюю сеть → введите пароль → **Подключиться**

### 2.3 Переход на домашний IP

1. После подключения к роутеру устройство получит IP-адрес и покажет его на странице `192.168.4.1`
2. Нажмите **Перейти** — произойдёт редирект и перезагрузка устройства, точка доступа отключится
3. В дальнейшем заходите в веб-интерфейс по этому IP

> **📌 Сохраните IP:**
> - Добавьте страницу в закладки браузера
> - Закрепите IP за устройством в роутере (DHCP reservation), иначе адрес может измениться после перезагрузки

### 2.4 Если вы потеряли IP-адрес

#### Через Klipper (рекомендуемый)

Если установлен плагин `flook32.py`, выполните в консоли Klipper:
```gcode
FLOOK_STATUS
```

#### Через BAT-скрипт (Windows)

Запустите скрипт из папки `tools/` двойным щелчком:
```
find_flook32.bat
```
Скрипт просканирует локальную сеть, найдёт устройство и автоматически откроет веб-интерфейс в браузере.

> Если ничего не помогло — подключитесь к точке доступа `FLOOK32-XXXX` (пароль `flook1234`) и откройте `http://192.168.4.1`.

[🔝 Наверх](#установка-и-прошивка-flook32)

---

[🔙 На главную](../README.md)

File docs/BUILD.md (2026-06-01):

[🔙 На главную](../README.md)

# Сборка FLOOK32

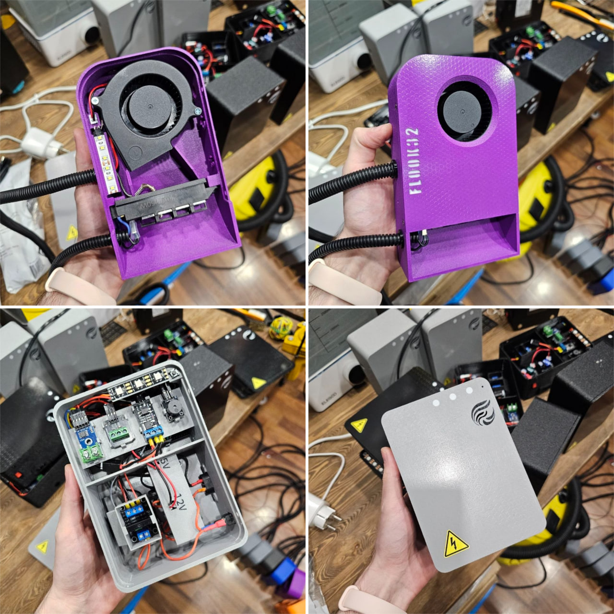
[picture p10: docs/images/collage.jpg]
Общее фото


## 🛠️ Что понадобится

| Инструмент | Для чего | Можно без него? |
|---|---|---|
| Паяльник | БП 5В и БП 12В, ESP01S, шина 5В | ❌ Нет |
| Кримпер для НШВИ | Оконцевание проводов 220В | ❌ Нет |
| Обжим для РП | KCD11 и C8 | ✅ Да |

---

## ✅ Что можно упростить

| Деталь | Как упростить |
|---|---|
| KCD11 и C8 | Контакты можно просто припаять |
| Dupont-перемычки | Покупайте только качественные с позолоченными или никелированными контактами. Дешёвые перемычки с ферромагнитными контактами (магнитятся) имеют высокое сопротивление и склонны к окислению и ослаблению контакта.|
| JST XH 2.54 | Купить уже обжатые готовые провода |

---

## ❌ Что нельзя упрощать

| Деталь | Почему |
|---|---|
| **НШВИ** | Провода 220В **обязательно** обжать гильзами. Без НШВИ провод со временем ослабнет и начнёт греться. DS18B20 обычно поставляется не обжатым, обязательно обжать. ESP01S питание и SSR G3MB-202P обжать питание и сигнальный провод |
| **Паяльник** | У БП S15W10E только площадки под пайку. Связь между ESP32 (GPIO26) и ESP01S (GPIO2). У ESP01S нет готового выхода GPIO2 — либо припаять угловой штырек вместо штатного, либо припаять провод напрямую. |

---
# В РАЗРАБОТКЕ
# 📋 Подготовка

## 1. Внешний блок
### 1.1 5В шина
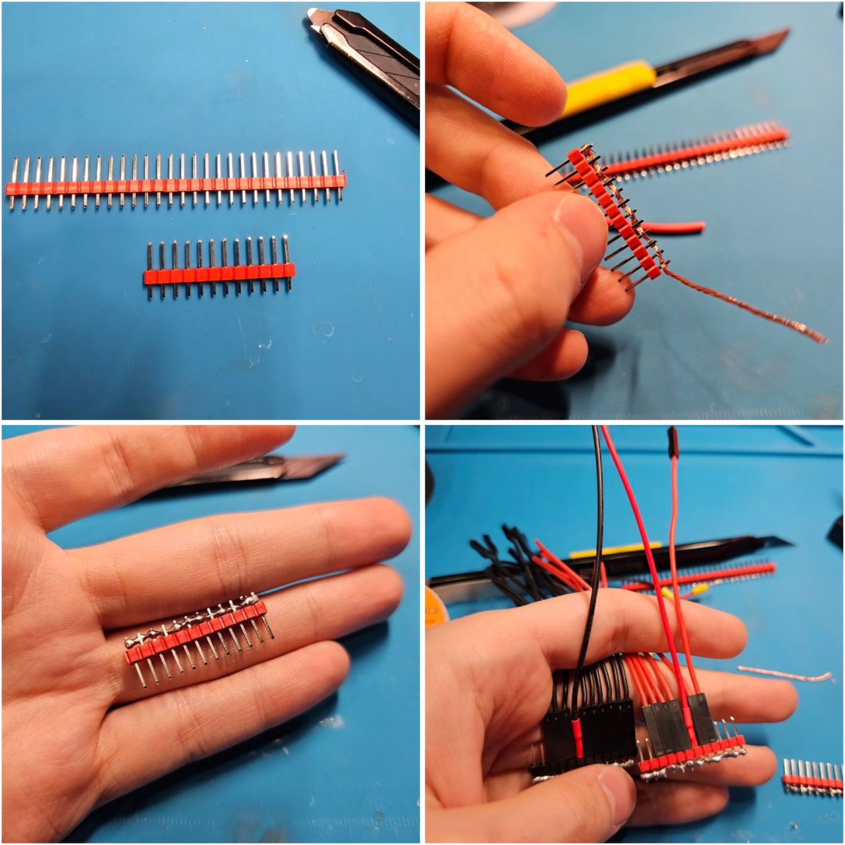
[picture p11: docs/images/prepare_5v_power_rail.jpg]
Подготовка 5В шина

### 1.2 Розетка С8
### 1.3 LED WS2812B
### 1.4 MOSFET LR7843
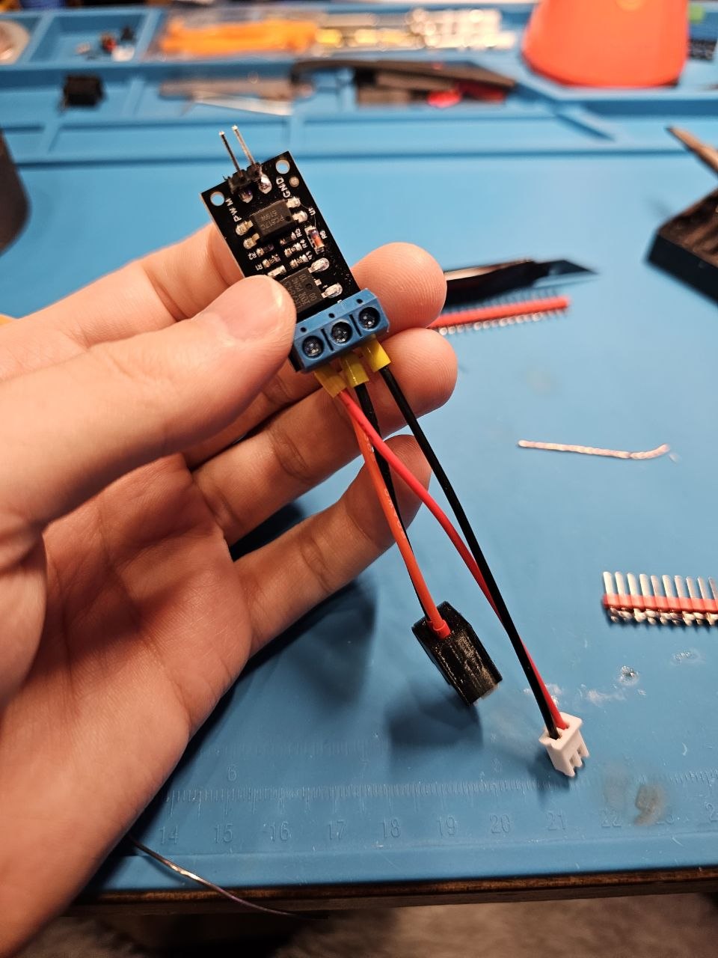
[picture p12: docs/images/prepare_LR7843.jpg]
Подготовка MOSFET LR7843

### 1.5 ESP32D
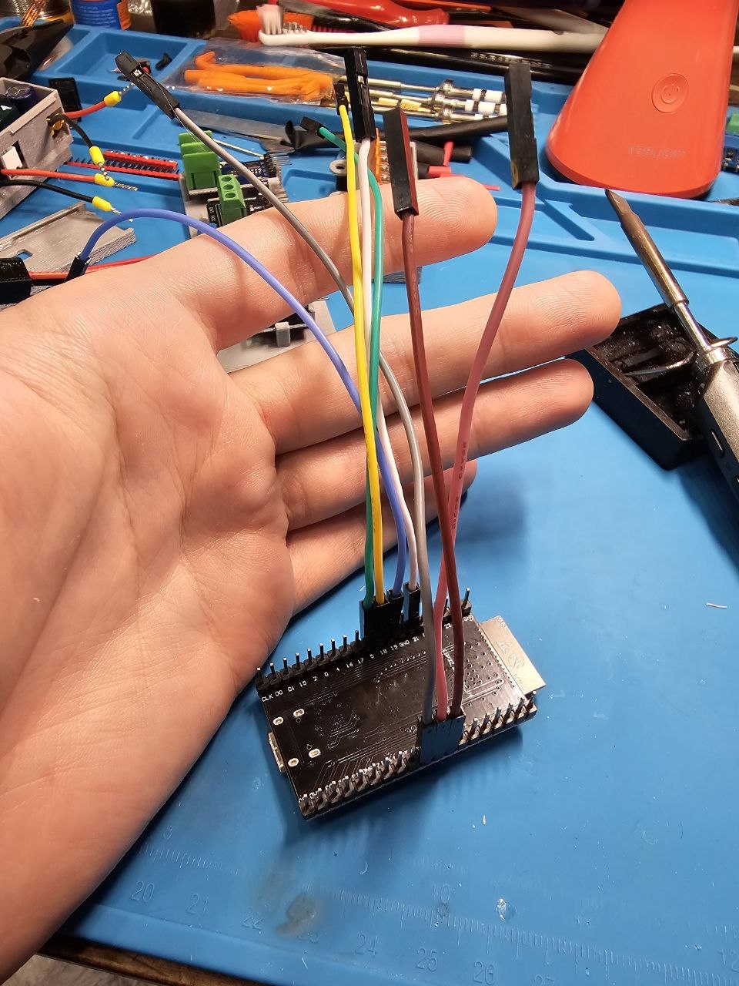
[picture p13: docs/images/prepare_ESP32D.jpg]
Подготовка ESP32D

### 1.6 Шина 220В
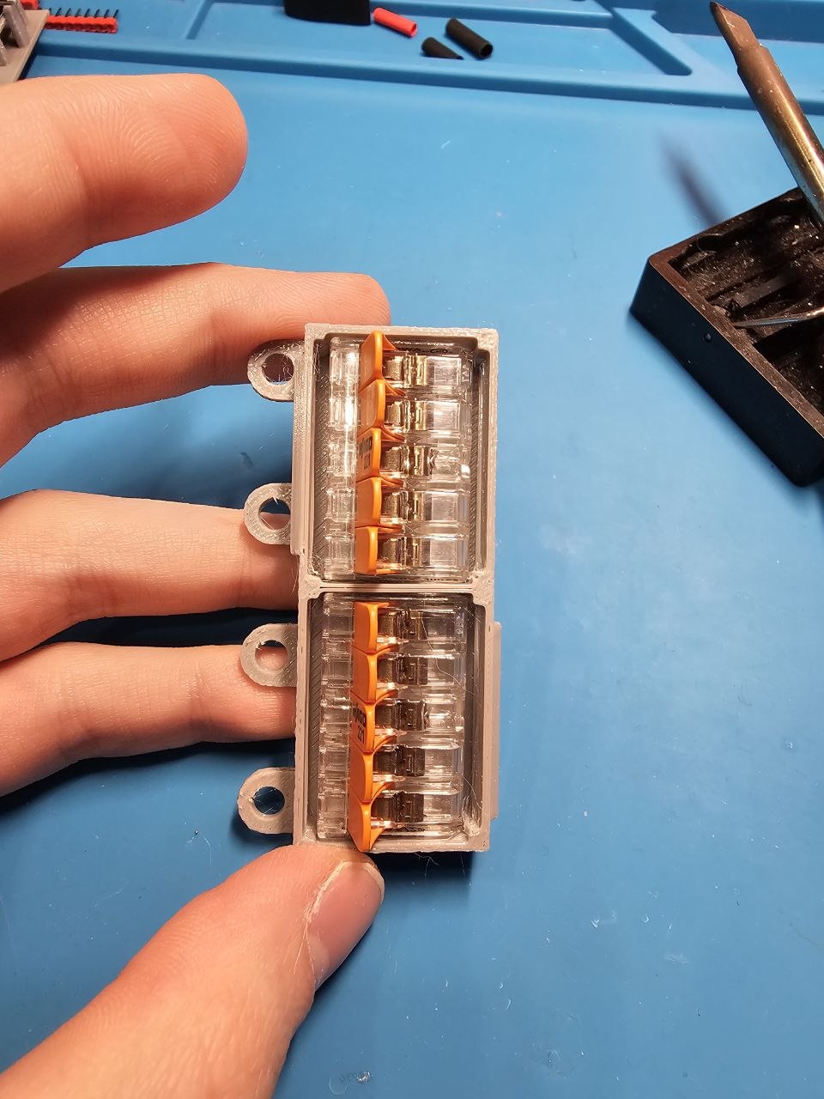
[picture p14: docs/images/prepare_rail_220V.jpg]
Подготовка шины 220В

### 1.7 Блоки питания
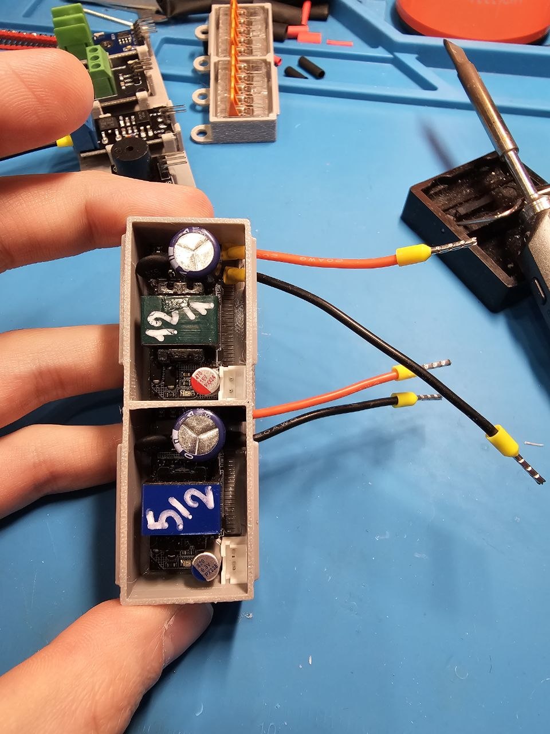
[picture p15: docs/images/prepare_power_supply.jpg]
Подготовка блоков питания

### 1.8 ESP01S и G3MB-202P
### 1.9 Перемычки

## 2. Внутренний блок
### 2.1 LED 12В
### 2.2 Нагреватель

# 📋 Сборка

## 1. Внешний блок
### 1.1 Резьбовые втулки
### 1.2 5В шина
### 1.3 LED WS2812B
### 1.4 Тактовая кнопка сброса
### 1.5 ESP32D
### 1.6 Переключатель KCD11
### 1.7 Розетка С8
### 1.8 Шина 220В
### 1.9 Блоки питания
### 1.10 ESP01S и G3MB-202P
### 1.11 Установка модулей
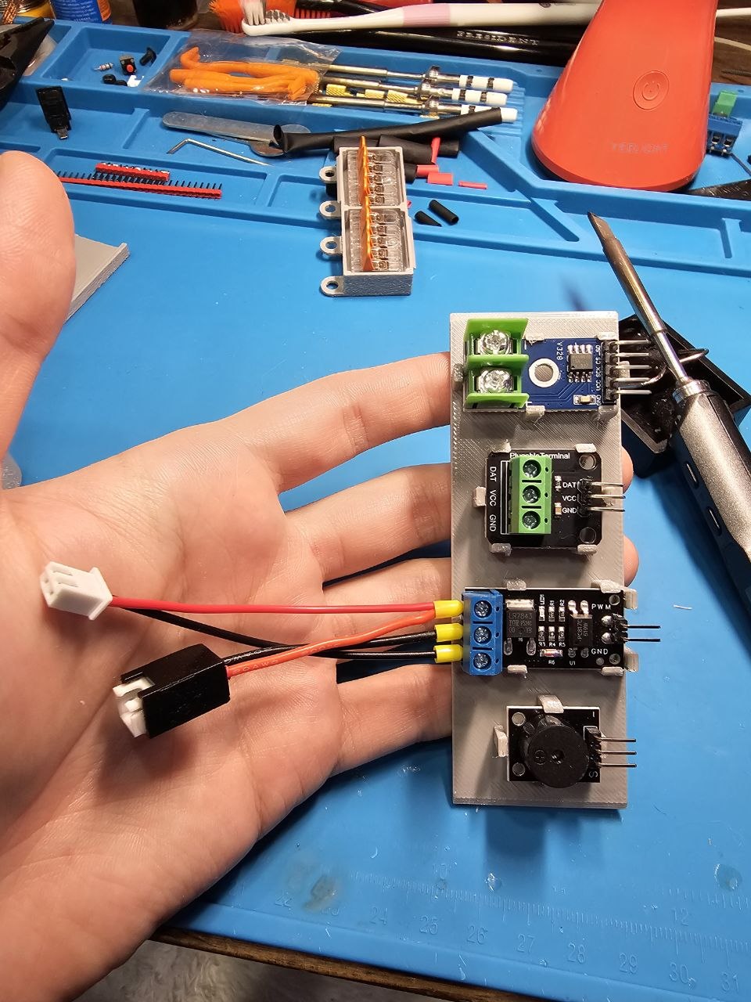
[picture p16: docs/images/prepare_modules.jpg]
Подготовка модулей

### 1.12 Магниты

## 2. Внутренний блок
### 2.1 Резьбовые втулки
### 2.2 LED 12В
### 2.3 Нагреватель
### 2.4 XH2.54
### 2.5 Магниты
### 2.6 Заглушки
### 2.7 Вентилятор

## 3. Рекомендации по проверкам
### 3.1 Проверка линии 220В
### 3.2 Проверка напряжения блоков питания
### 3.3 Проверка XH2.54 внутреннего блока

# 📋 Установка блоков

## 1. Внутренний блок
### 1.1 Установка гофры
### 1.2 Крышка
### 1.3 Прокладка проводов

## 2. Внешний блок
### 1.1 Нагреватель
### 1.2 Датчик температуры воздуха DS18B20
### 1.3 Термопара и линия 12В
### 1.4 Установка гофры
### 1.5 Крышка

# 📋 Проверка работоспособности

### 1. ESP32D, LED WS2812B, Бипер KY-012
### 2. Тактовая кнопка сброса
### 3. ESP01S реле
### 4. SSR реле, нагреватель, термопара
### 5. Вентилятор и LED 12В
### 6. Датчик температуры воздуха DS18B20

[🔝 Наверх](#сборка-flook32)

---

[🔙 На главную](../README.md)

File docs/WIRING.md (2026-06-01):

[🔙 На главную](../README.md)

# Схема подключения FLOOK32

## 📋 Содержание

- [Высоковольтный отсек (220В)](#высоковольтный-отсек-220в)
- [Низковольтный отсек (5В/12В)](#низковольтный-отсек-5в12в)
- [Сигналы ESP32](#сигналы-esp32)
- [Силовые выходы](#силовые-выходы)
- [Таблица соединений](#таблица-соединений)
- [Статистика проводов](#статистика-проводов)

---

## Высоковольтный отсек (220В)

```
╔══════════════════════════════════════════════════════════════════════════════════╗
║               ВЫСОКОВОЛЬТНЫЙ ОТСЕК (220В)                ║    Внутренний блок    ║
╠══════════════════════════════════════════════════════════╣                       ║
║                                                          ║                       ║
║   C8 ── L ───── Шина L ──┬── БП 5В (L)                   ║                       ║
║   (розетка)              ├── БП 12В (L)                  ║                       ║
║    │                     └── ESP01S COM                  ║                       ║
║    │                                                     ║                       ║
║    └─────────── N ── KCD11 ── Шина N ──┬── БП 5В (N)     ║                       ║
║                                        ├── БП 12В (N)    ║                       ║
║                                        └── SSR A1        ║                       ║
║                                                          ║                       ║
║   SSR B1 ───────────────────────────────────────────────── KSD9700 ─ Нагреватель ║
║   ESP01S NO ─────────────────────────────────────────────────────────────┘       ║
║                                                          ║                       ║
║ При пропадании heartbeat > 6 секунд:                     ║                       ║
║ ESP01S реле размыкается → нагреватель обесточивается     ║                       ║
║                                                          ║                       ║
╚══════════════════════════════════════════════════════════════════════════════════╝
```

### Элементы высоковольтного отсека

| Обозначение | Компонент | Назначение |
|---|---|---|
| C8 | Разъём IEC C8 | Вход 220В на корпусе |
| KCD11 | Кнопка KCD11 | Разрыв нейтрали 220В |
| Шина L | Шина 220В (фаза) | Распределение фазы |
| Шина N | Шина 220В (нейтраль) | Распределение нейтрали |
| БП 5В | Блок питания 5В/2A | Питание ESP32 и периферии |
| БП 12В | Блок питания 12В/1A | Питание MOSFET и вентилятора |
| SSR | G3MB-202P / SSR-10DA | Твердотельное реле управления нагревателем |
| ESP01S | ESP01S + релейный модуль | Аппаратный watchdog |

[🔝 Наверх](#схема-подключения-flook32)

---

### Низковольтный отсек (5В/12В)

```
╔════════════════════════════════════════════════════════════════════════════════════════════╗
║                       НИЗКОВОЛЬТНЫЙ ОТСЕК (5В/12В)                   ║   Внутренний блок   ║
╠══════════════════════════════════════════════════════════════════════╣                     ║
║                                                                      ║                     ║
║   ╔═══════════════╗                                                  ║                     ║
║   ║   ШИНА 5В     ║                                                  ║                     ║
║   ╠═══════════════╣                                                  ║                     ║
║   ║ БП 5В ── VCC ──── ESP32, MAX6675, DS18B20, LED, SSR DC+, ESP01S  ║                     ║
║   ║ БП 5В ── GND ─┬── ESP32, MAX6675, DS18B20, LED, SSR DC-, ESP01S  ║                     ║
║   ║               └── MOSFET, Бипер, Кнопка                          ║                     ║
║   ╚═══════════════╝                                                  ║                     ║
║                                                                      ║                     ║
║   ╔═══════════════╗                                                  ║                     ║
║   ║      12В      ║                                                  ║                     ║
║   ╠═══════════════╣                                                  ║                     ║
║   ║ БП 12В ── +12V ── MOSFET (+)  ───────────────────────────────────── Вентилятор (+12В)  ║
║   ║ БП 12В ── -12V ── MOSFET (-)                                     ║                     ║
║   ║                   MOSFET LOAD ───────────────────────────────────── Вентилятор (-12В)  ║
║   ╚═══════════════╝                                                  ║                     ║
║                                                                      ║                     ║
╚════════════════════════════════════════════════════════════════════════════════════════════╝
```

### Элементы низковольтного отсека

| Обозначение | Компонент | Назначение |
|---|---|---|
| ESP32 | ESP32 Dev Board | Основной контроллер |
| MAX6675 | MAX6675 модуль | Преобразователь термопары |
| DS18B20 | Датчик DS18B20 | Температура воздуха в камере |
| LED | LED лента WS2812B | Светодиодная индикация |
| SSR DC+ | SSR G3MB-202P DC+ | Питание реле (5В) |
| SSR DC- | SSR G3MB-202P DC- | Питание реле (5В) |
| MOSFET | MOSFET LR7843 | ШИМ-управление вентилятором |
| Бипер | KY-012 | Звуковая индикация |
| Кнопка | Тактовая кнопка | Сброс к заводским настройкам |

[🔝 Наверх](#схема-подключения-flook32)

---

### Сигналы ESP32

```
╔═══════════════════════════════════════════════════════════════════════════════╗
║                              СИГНАЛЫ ESP32                                    ║
╠═══════════════════════════════════════════════════════════════════════════════╣
║                                                                               ║
║   ┌─────────┐    ┌──────────────┐    ┌─────────────────────────────────────┐  ║
║   │ GPIO32  │ →  │ SSR CH1      │    │ Управление нагревателем             │  ║
║   ├─────────┤    ├──────────────┤    ├─────────────────────────────────────┤  ║
║   │ GPIO33  │ →  │ MOSFET PWM   │    │ ШИМ вентилятора (17 кГц)            │  ║
║   ├─────────┤    ├──────────────┤    ├─────────────────────────────────────┤  ║
║   │ GPIO26  │ →  │ ESP01S GPIO2 │    │ Heartbeat (100/900 мс)              │  ║
║   ├─────────┤    ├──────────────┤    ├─────────────────────────────────────┤  ║
║   │ GPIO21  │ →  │ DS18B20 DAT  │    │ OneWire шина                        │  ║
║   ├─────────┤    ├──────────────┤    ├─────────────────────────────────────┤  ║
║   │ GPIO18  │ →  │ MAX6675 SCK  │    │ Тактирование SPI                    │  ║
║   ├─────────┤    ├──────────────┤    ├─────────────────────────────────────┤  ║
║   │ GPIO5   │ →  │ MAX6675 CS   │    │ Chip Select                         │  ║
║   ├─────────┤    ├──────────────┤    ├─────────────────────────────────────┤  ║
║   │ GPIO19  │ ←  │ MAX6675 SO   │    │ Данные SPI                          │  ║
║   ├─────────┤    ├──────────────┤    ├─────────────────────────────────────┤  ║
║   │ GPIO25  │ →  │ Бипер        │    │ Звуковая индикация                  │  ║
║   ├─────────┤    ├──────────────┤    ├─────────────────────────────────────┤  ║
║   │ GPIO27  │ →  │ LED DIN      │    │ NeoPixel WS2812B                    │  ║
║   ├─────────┤    ├──────────────┤    ├─────────────────────────────────────┤  ║
║   │ GPIO17  │ ←  │ Кнопка RESET │    │ Сброс к заводским (5 сек)           │  ║
║   └─────────┘    └──────────────┘    └─────────────────────────────────────┘  ║
║                                                                               ║
╚═══════════════════════════════════════════════════════════════════════════════╝
```

### Таблица GPIO

| Пин ESP32 | Направление | Куда | Сигнал | Примечание |
|---|---|---|---|---|
| GPIO32 | → | SSR CH1 | HIGH = включён | Управление нагревателем |
| GPIO33 | → | MOSFET PWM | 0-1023, 17 кГц | ШИМ вентилятора |
| GPIO26 | → | ESP01S GPIO2 | 100/900 мс | Heartbeat watchdog |
| GPIO21 | → | DS18B20 DAT | OneWire | Температура воздуха |
| GPIO18 | → | MAX6675 SCK | SPI | Тактирование |
| GPIO5  | → | MAX6675 CS | SPI | Выбор чипа |
| GPIO19 | ← | MAX6675 SO | SPI | Данные термопары |
| GPIO25 | → | Бипер | HIGH = писк | Звуковая индикация |
| GPIO27 | → | LED DIN | NeoPixel | Светодиодная лента |
| GPIO17 | ← | Кнопка RESET | INPUT_PULLUP | Сброс к заводским (5 сек) |

[🔝 Наверх](#схема-подключения-flook32)

---

## Силовые выходы

```
╔═══════════════════════════════════════════════════════════════════════════════╗
║ СИЛОВЫЕ ВЫХОДЫ                                                                ║
╠═══════════════════════════════════════════════════════════════════════════════╣
║                                                                               ║
║ НАГРЕВАТЕЛЬ 220В (двухуровневая защита):                                      ║
║ ┌─────────────────────────────────────────────────────────────────────────┐   ║
║ │ SSR B1 ────────────────────────────┐                                    │   ║
║ │                               Нагреватель                               │   ║
║ │ ESP01S NO ─────────────────────────┘                                    │   ║
║ └─────────────────────────────────────────────────────────────────────────┘   ║
║                                                                               ║
║ Уровень 1: SSR G3MB-202P (GPIO32) — штатное управление                        ║
║ Уровень 2: ESP01S + реле (watchdog) — аварийное отключение                    ║
║                                                                               ║
║ ВЕНТИЛЯТОР 12В:                                                               ║
║ ┌─────────────────────────────────────────────────────────────────────────┐   ║
║ │ MOSFET +12В ───── Вентилятор (+12В)                                     │   ║
║ │                                                                         │   ║
║ │ MOSFET LOAD ───── Вентилятор (-12В)                                     │   ║
║ └─────────────────────────────────────────────────────────────────────────┘   ║
║                                                                               ║
╚═══════════════════════════════════════════════════════════════════════════════╝
```

[🔝 Наверх](#схема-подключения-flook32)

---

## Таблица соединений

### Вход 220В и шины

| Откуда | Куда | Примечание |
|---|---|---|
| C8 L | Шина L | Фаза 220В |
| C8 N | KCD11 вход | Нейтраль 220В через выключатель |
| KCD11 выход | Шина N | Нейтраль после разрыва |

### Питание блоков от шин 220В

| Откуда | Цвет | Куда |
|---|---|---|
| Шина L | 🔴 | БП 5В (вход L) |
| Шина N | ⚫️ | БП 5В (вход N) |
| Шина L | 🔴 | БП 12В (вход L) |
| Шина N | ⚫️ | БП 12В (вход N) |
| Шина L | 🔴 | ESP01S COM |
| Шина N | ⚫️ | SSR A1 |

### Шины VCC и GND (5В)

| Откуда | Куда |
|---|---|
| БП 5В VCC | Шина VCC |
| БП 5В GND | Шина GND |

### Питание модулей от шины VCC (🔴)

| Откуда | Куда |
|---|---|
| Шина VCC | ESP32 |
| Шина VCC | MAX6675 |
| Шина VCC | DS18B20 |
| Шина VCC | LED WS2812B |
| Шина VCC | SSR DC+ |
| Шина VCC | ESP01S |

### Земля модулей от шины GND (⚫️)

| Откуда | Куда |
|---|---|
| Шина GND | ESP32 |
| Шина GND | MAX6675 |
| Шина GND | DS18B20 |
| Шина GND | MOSFET LR7843 |
| Шина GND | Бипер KY-012 |
| Шина GND | LED WS2812B |
| Шина GND | Кнопка RESET |
| Шина GND | SSR DC- |
| Шина GND | ESP01S |

### Питание 12В

| Откуда | Цвет | Куда |
|---|---|---|
| БП 12В +12В | 🔴 | MOSFET +12В |
| БП 12В −12В | ⚫️ | MOSFET −12В |

### GPIO сигналы ESP32

| Пин ESP32 | Сигнал | Куда |
|---|---|---|
| GPIO18 | SCK | MAX6675 SCK |
| GPIO5 | CS | MAX6675 CS |
| GPIO19 | SO | MAX6675 SO |
| GPIO21 | DAT | DS18B20 DAT |
| GPIO33 | PWM | MOSFET PWM |
| GPIO25 | — | Бипер KY-012 |
| GPIO27 | DIN | LED WS2812B DIN |
| GPIO17 | — | Кнопка RESET |
| GPIO32 | CH1 | SSR CH1 |
| GPIO26 | WDT | ESP01S GPIO2 |

### Силовые выходы

| Откуда | Цвет | Куда |
|---|---|---|
| SSR B1 | ⚫️ | Нагреватель 220В |
| ESP01S NO | 🔴 | Нагреватель 220В |
| MOSFET +12В | 🔴 | Вентилятор (+12В) |
| MOSFET LOAD | ⚫️ | Вентилятор (LOAD) |
| MOSFET GND | ⚫️ | Шина GND |

[🔝 Наверх](#схема-подключения-flook32)

---

## Статистика проводов

### Низковольтные провода (27 шт)

| Сигнал | Цвет | Количество | Куда |
|---|---|---|---|
| VCC | 🔴 | 7 | Питание модулей |
| GND | ⚫️ | 10 | Земля модулей |
| GPIO18 | 🟡 | 1 | MAX6675 SCK |
| GPIO5 | 🟢 | 1 | MAX6675 CS |
| GPIO19 | 🔵 | 1 | MAX6675 SO |
| GPIO21 | ⚪️ | 1 | DS18B20 DAT |
| GPIO33 | 🟤 | 1 | MOSFET PWM |
| GPIO25 | 🟣 | 1 | Бипер |
| GPIO27 | 🟠 | 1 | LED WS2812B |
| GPIO17 | ⚪️ | 1 | Кнопка RESET |
| GPIO32 | 🟤 | 1 | SSR CH1 |
| GPIO26 | ⚪️ | 1 | ESP01S GPIO2 |

### Высоковольтные провода (11 шт)

| Сигнал | Цвет | Количество |
|---|---|---|
| L (фаза) | 🔴 | 5 |
| N (нейтраль) | ⚫️ | 6 |

### Провода 12В (4 шт)

| Сигнал | Цвет | Количество |
|---|---|---|
| +12В | 🔴 | 2 |
| LOAD/−12В | ⚫️ | 2 |

[🔝 Наверх](#схема-подключения-flook32)

---

[🔙 На главную](../README.md)

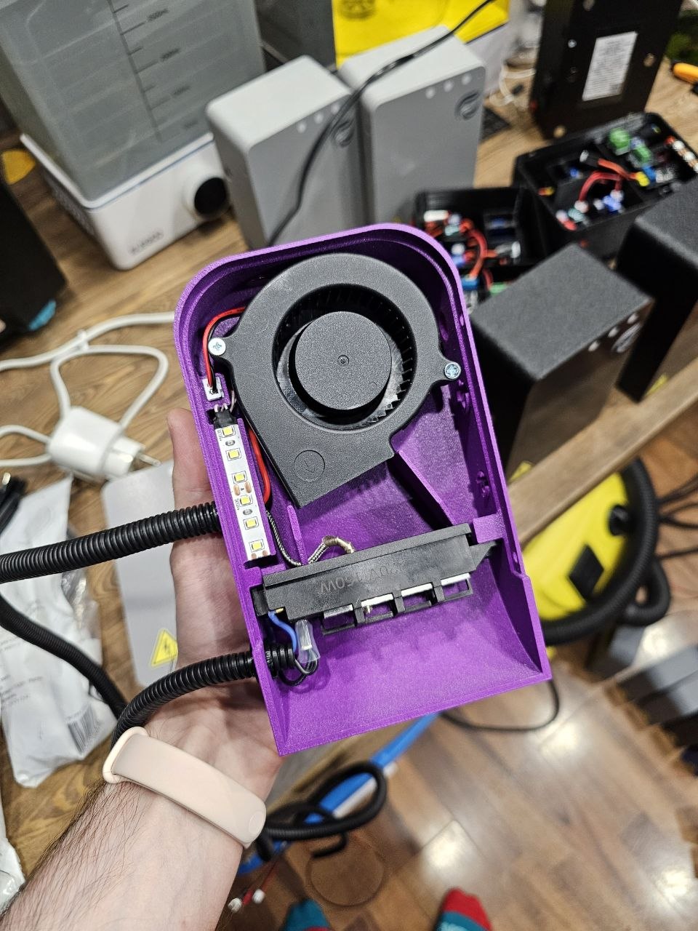
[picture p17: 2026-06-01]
docs/images/assembled_inside_open.jpg

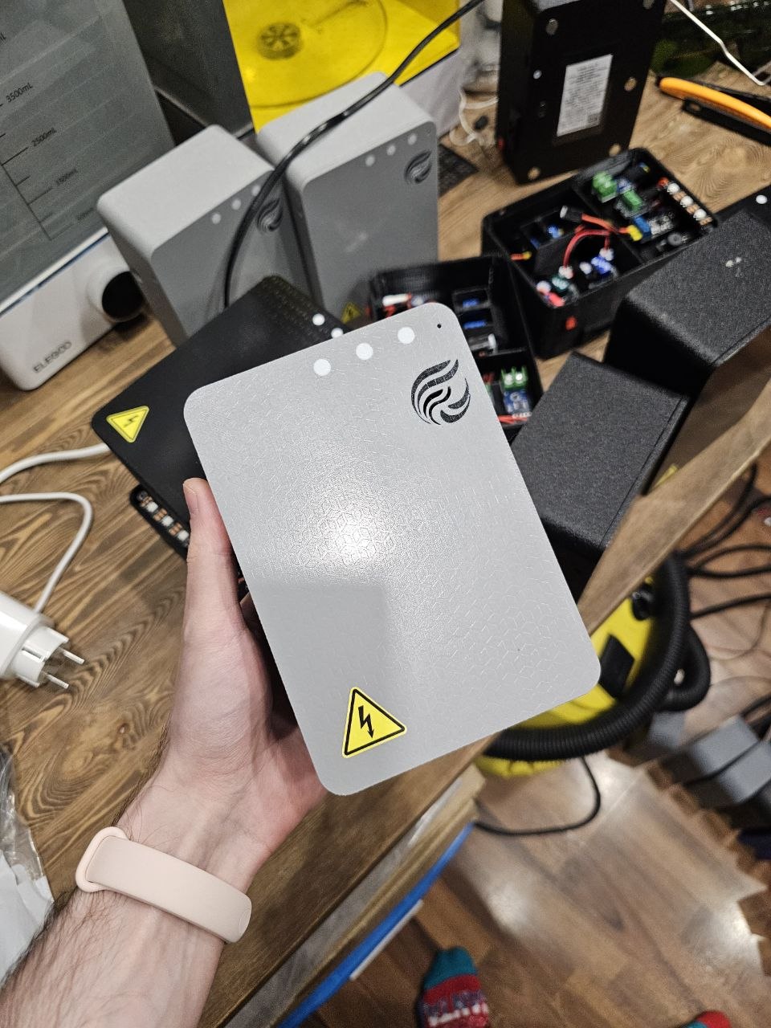
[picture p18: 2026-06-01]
docs/images/assembled_outside.jpg

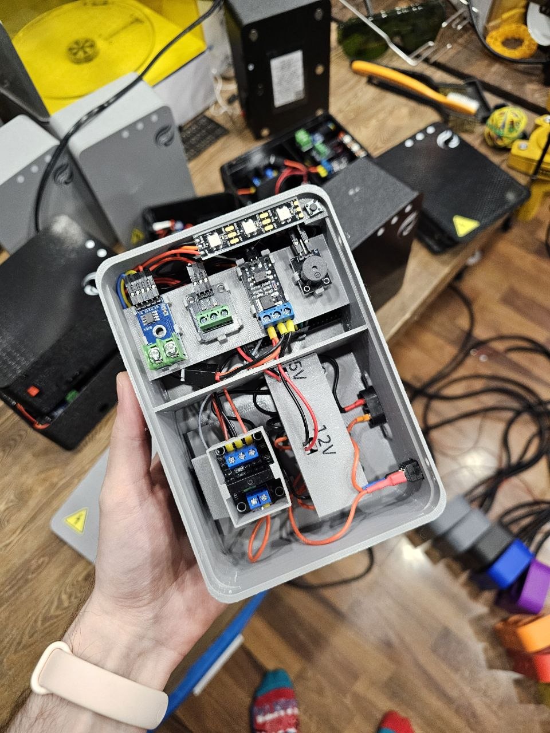
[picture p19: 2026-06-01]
docs/images/assembled_outside_open.jpg

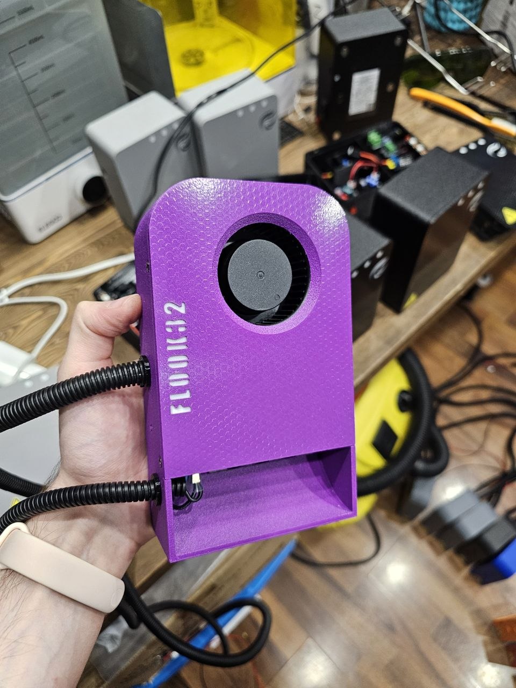
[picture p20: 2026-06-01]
docs/images/assembled_inside.jpg

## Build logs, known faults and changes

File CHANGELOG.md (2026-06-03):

# Changelog

Все заметные изменения в этом проекте будут задокументированы в этом файле.

Формат основан на [Keep a Changelog](https://keepachangelog.com/en/1.0.0/),
и проект придерживается [Semantic Versioning](https://semver.org/spec/v2.0.0.html).

## [0.1.0b]

### Добавлено
- Автоматическая проверка обновлений через GitHub (`/api/check-update`, `/api/update-ota`)
- OTA-обновление по URL (кнопка «Обновить автоматически» в веб-интерфейсе)
- Скрипты быстрой прошивки: `flash_flook32.bat` (Windows), `flash_flook32.sh` (Linux/macOS)
- Поиск устройства в сети: `tools/find_flook32.bat`
- Логирование потери/восстановления связи с Klipper в журнал ошибок
- Контроль фрагментации кучи с авторебутом при утечке памяти
- Логирование состояния памяти (критическое/низкое/восстановление) в журнал ошибок
- Улучшенные LED-анимации: волна Wi-Fi, дыхание, мерцание, прогресс
- Дисклеймер с 10-секундной блокировкой экрана в режиме точки доступа
- Скрипты сборки веб-ресурсов с автоскачиванием Chart.js (`compress_webui.sh`, `compress_webui.bat`)
- Структура репозитория: `docs/`, `firmware/`, `tools/`, `klipper/`, `hardware/`, `enclosure/`
- Полная документация: BUILD, SETUP, WIRING, BOM, FAQ, WEBUI, FIRMWARE, KLIPPER, ESP01S_FIRMWARE

### Изменено
- Проверка доступности Klipper через TCP (вместо UDP) — статус сбрасывается через 60 сек
- Увеличена надёжность определения IP Klipper из NVS (восстановление без автоматического `detected = true`)
- Улучшена документация: перекрёстные ссылки «На главную», быстрая навигация

### Исправлено
- Бесконечное «воскрешение» статуса Klipper через UDP и NVS
- Сброс `klipperStatus.detected` теперь работает корректно
- Убран спам статистики в лог ошибок каждые 5 минут

## [0.1.0b] - 2026-05-20

### Первый публичный релиз
- Двухконтурное управление с гистерезисом (воздух + нагреватель)
- 7 независимых защит с трёхступенчатой эскалацией
- Самообучаемая термальная модель
- Автоматическая адаптация (9 фаз самонастройки)
- Веб-интерфейс на WebSocket + REST API (30+ эндпоинтов)
- Интеграция с Klipper/Moonraker (UDP-обнаружение, автоотключение после печати)
- Аппаратный watchdog на ESP-01S
- LED-индикация на WS2812B (10 режимов)
- Звуковая индикация через бипер (3 мелодии)
- OTA-обновление прошивки
- Библиотеки Chart.js встроены в прошивку (не зависят от CDN)
- IP Klipper сохраняется в NVS и восстанавливается после перезагрузки
- Логирование причины перезагрузки в журнал ошибок
- Проверка свободного места в NVS при старте
- Лицензия GPLv3

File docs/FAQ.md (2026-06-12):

[🔙 На главную](../README.md)

# ❓ FAQ — Часто задаваемые вопросы

---

## Зачем внешний блок?

У этого решения несколько обоснований:

- **Не во всех принтерах есть место.** Отсек электроники большинства принтеров рассчитан только на заводскую плату и блок питания. Разместить там дополнительно БП 5В, SSR, MOSFET, ESP32, ESP-01S и всю разводку 220В физически невозможно. Внешний блок решает эту проблему — он стоит отдельно от принтера, и ему не нужно место внутри корпуса. При смене принтера на новую модель вы просто переносите внешний и внутренний блоки — не нужно искать место в новом корпусе, разрабатывать крепления и переделывать проводку. В корпусе предусмотрены места под магниты, что позволяет аккуратно закрепить блок на задней металлической крышке принтера без сверления и винтов.
Если в вашем принтере достаточно места в отсеке электроники — вы можете не использовать внешний блок и разместить всё внутри, в таком случае Вам может не понадобится 12В блок питания, Вы можете использовать 24В вентилятор с оригинальным блоком питания принтера. **Важно:** никогда не размещайте электронику управления внутри камеры, это чревато сокращением срока жизни SSR реле, что в свою очередь риск залипания в замкнутом состоянии!

- **Удобство сборки.** В проекте много проводов и модулей. Если подогнать всё впритык — сборка превратится в ад. Внешний блок даёт достаточно пространства для аккуратной укладки проводов и доступа ко всем компонентам.

---

## Зачем в проекте используется гофра для проводов?

Обжатые концы проводов нагревателя, термопары и датчика DS18B20 имеют большой размер — пришлось делать отверстия во внешнем блоке значительно шире, чем нужно для просто проводов. Гофра полностью закрывает отверстие, и дополнительно защищает провода от домашних животных, детей и других механических воздействий.
Вы можете не использовать гофру, а напечатать заглушки которые уменьшают отверстия.

---

## Почему мощность вентилятора регулируется сырым duty, а не удобными процентами?

MOSFET-модули подобного типа, используемые в проекте, имеют на плате оптрон (оптическую развязку), который вносит особенности в логику управления. Дело в том, что оптрон — это не просто «проводник», а светодиод и фототранзистор внутри одной микросхемы.

**Как это работает:**
- При подаче ШИМ-сигнала на вход модуля сначала должен засветиться светодиод оптрона.
- Светодиоду требуется некоторое время на включение и определённый пороговый ток, ниже которого он просто не зажигается.
- Только после того, как светодиод начал излучать, фототранзистор открывается и подаёт напряжение на затвор MOSFET.

**Плюсы оптрона в MOSFET-модуле:**
- **Гальваническая развязка** — управляющий сигнал и силовая часть электрически изолированы. Если что-то пойдёт не так на стороне нагрузки, контроллер не пострадает.
- **Защита от помех** — высоковольтные наводки и шумы с силовой линии не проникают обратно в ESP32.
- **Безопасность** — даже при пробое MOSFET управляющая цепь остаётся под низким напряжением.

**Что это означает на практике:**
- При малых значениях duty (примерно до 200 из 1023) — светодиод оптрона не успевает выйти на рабочий режим или ток через него недостаточен. Вентилятор может не запускаться вообще или вести себя нестабильно.
- При высоких значениях duty (выше 400) — светодиод уже полностью открыт, MOSFET насыщен, и вентилятор работает на максимальных оборотах. Дальнейшее увеличение duty практически ничего не меняет.

**Почему нельзя просто взять проценты:**
Рабочий диапазон duty у разных экземпляров модулей может плавать из-за разброса параметров оптронов, пороговых напряжений MOSFET, температуры, и даже разных вентиляторов. То, что на одном модуле уверенный старт с duty 180, на другом может потребовать 220. Границы «мёртвой зоны» и «насыщения» индивидуальны. Поэтому невозможно универсально и линейно привязать проценты (0–100%) к реальной скорости вращения — одна и та же цифра на разных сборках даст разный результат.

**Нужна ли плавная регулировка на практике?**
Сама возможность регулировки мощности вентилятора появилась в ходе экспериментов с кодом. На практике же выяснилось, что она избыточна — для эффективного нагрева камеры достаточно простого вкл/выкл. Поэтому в прошивке есть управление в сырых значениях duty (0–1023) для тех, кому это нужно, но в штатном режиме вентилятор просто включается и выключается.

---

## Как адаптировать внешний блок под нагреватели мощнее 200 Вт?

- Используйте корпус внешнего блока flook32_external_da под SSR реле 10DA/25DA/40DA/65DA. Выбирайте SSR с запасом 50%:
  например, для нагревателя 400 Вт (≈2 А) подойдёт 10DA, т.к. 2 А < 5 А
  (50% от номинала 10 А).
- Используйте провода соответствующего сечения:

| AWG | Сечение | Ток (длительно) | Мощность (220В) | Рекомендуемое SSR |
|-----|---|---|---|---|
| 20 AWG | 0.52 мм² | 5 А | до 1100 Вт | 10DA (10 А) |
| 18 AWG | 0.82 мм² | 7 А | до 1540 Вт | 25DA (25 А) |
| 16 AWG | 1.31 мм² | 10 А | до 2200 Вт | 25DA (25 А) |

⚠️ Важное предупреждение:
Реле Watchdog ESP01S рассчитано на токи до 16А (хотя я не рекомендую превышать 10А) — учитывайте это при выборе нагрузки!

---

## Могу ли я не использовать ESP-01S?

Да, но с важной оговоркой. ESP-01S выполняет роль аппаратного watchdog — отключает 220В при зависании основного ESP32, а также при критических ошибках (перегрев, Thermal Runaway, блокировка системы).

В большинстве случаев эта защита избыточна — софтовая защита ESP32 справляется. Однако если SSR реле «залипнет» в замкнутом состоянии (механическая неисправность), ESP-01S — единственное, что физически разорвёт цепь 220В и предотвратит бесконтрольный нагрев.

**Вариант с отказом от ESP-01S (базовый):**
1. Подключите второй провод нагревателя напрямую к шине 220В.
2. В основную прошивку вносить правки не нужно — она будет работать как обычно.

Помните: вы теряете последний рубеж защиты от залипшего реле.

<details>
<summary>**Вариант с заменой на второе SSR (продвинутый):**</summary>

Можно исключить ESP-01S и электромеханическое реле, заменив их на второе твердотельное реле G3MB-202P. Логика та же: второе SSR ставится последовательно в цепь нагревателя, но управляется напрямую с ESP32 с отдельного GPIO.

Что это даёт:
- Аналогично с ESP01S два независимых реле разрывающих фазу и ноль 220В. При зависании ESP32 или обнаружении перегрева основная прошивка снимает сигнал со второго GPIO — цепь разрывается.
- Нет щелчков электромеханического реле.

Что потребуется:
1. Купить второе SSR G3MB-202P (ещё 1 шт).
2. Выделить свободный GPIO на ESP32 под управление вторым SSR.
3. Внести в прошивку значительные изменения:
   - Добавить управление вторым SSR во все критические ветки (перегрев, потеря связи с датчиками, программный сбой).
   - Учесть, что при программном сбое ESP32 может оставить GPIO в высоком состоянии.

Это рабочий, но более сложный путь. Подходит тем, кто хочет сохранить два рубежа защиты без дополнительного микроконтроллера и готов дорабатывать прошивку. Если не уверены — оставляйте ESP-01S, оно проще и надёжнее.
</details>

---

## Почему в проекте используется вентилятор на 12В? Это усложнение — нужно разводить линию 12В и ставить отдельный БП. Почему не использовать вентилятор на 220В?

Вентиляторы на 12В более распространены, и качественный 12В вентилятор
на шарикоподшипниках найти значительно проще, чем 220В.

Корпус внешнего блока flook32_external_da уже рассчитан на использование вентилятора 220В

Потребуется заменить функцию `updateFan()` в прошивке
на версию для дискретного управления (без ШИМ), но и текущая версия должна работать, если не включать ШИМ в настройках.
```cpp
digitalWrite(config.pinFan, config.invertFanSignal ? LOW : HIGH);
```

---

## Я купил G3MB-202P с маркировкой LOW LEVEL. Могу ли я его использовать?

Да. В веб-интерфейсе на странице настроек включите инверсию сигнала
нагревателя (галочка «Инвертировать сигнал нагревателя»).

⚠️ **Важно:** стоковая прошивка рассчитана на High Level реле. При первом
включении на нагревателе будет 220В. Если у вас установлен Watchdog ESP-01S —
это безопасно: без заданной целевой температуры он всегда разомкнут,
нагрева не произойдёт. Если ESP-01S не используется — сначала настройте
инверсию в безопасном режиме (с отключённым нагревателем) или перед первой
прошивкой замените в коде:

```cpp
#define DEFAULT_INVERT_HEATER_SIGNAL false
```

на

```cpp
#define DEFAULT_INVERT_HEATER_SIGNAL true
```

Тогда инверсия применится сразу после прошивки.

---

## Зачем в прошивке сделана система блокировки при критических ошибках?

При возникновении критической ошибки система сначала пытается восстановить
нормальную работу — это исключает ложные срабатывания защит. Только если
ошибка повторяется трижды (значение по умолчанию, можно увеличить на
странице настроек) — система блокируется полностью.

Блокировка требует ввода простого пароля `unlock`. Это сделано для того, чтобы
вы не могли случайно сбросить критическую проблему нажатием галочки или
другим простым способом. 

Решение вдохновлено критическими ошибками Klipper, с одним отличием: в
Klipper для сброса требуется полная перезагрузка прошивки, здесь —
достаточно ввести пароль в веб-интерфейсе.

---

## Зачем нужна блокировка страницы настроек?

По той же причине, что и система блокировки при критических ошибках —
чтобы исключить случайное изменение параметров. Некоторые настройки
напрямую влияют на безопасность: пороги защит, гистерезисы, инверсия
сигналов, мощность вентилятора. Случайное изменение любого из этих
параметров может привести к перегреву, пожару или порче оборудования.

Разблокировка настроек требует ввода простого пароля `unlock` — это осознанное действие,
которое вы не сделаете случайно.

---

### Почему нет mDNS (адрес flook32.local)?

Библиотека mDNS на ESP32 потребляет значительное количество оперативной памяти и процессорного времени, что критично для системы реального времени с приоритетом управления температурой. Кроме того, mDNS работает нестабильно на некоторых роутерах и может не поддерживаться в корпоративных сетях. Вместо этого используется простой и надёжный метод определения IP-адреса: точка доступа `FLOOK32-XXXX` остаётся активной ровно до момента получения редиректа на реальный IP-адрес устройства в вашей сети.

---

## Какой пластик лучше использовать для печати?

- **Внешний блок:** любой пластик — сильно греющихся элементов внутри нет.
- **Внутренний блок:** композит **ABS/PC** — он не поддерживает горение.

---

## Зачем на крышке внешнего блока отверстие в логотипе?

Это технологическое отверстие для вывода звука. Активный бипер находится
на плате прямо под ними — отверстия увеличивают громкость сигналов
тревоги, чтобы их было слышно даже в шумном помещении.

Для шумных помещений в настройках (вкладка «Бипер») смените
«Мелодия для оповещений» на «Тревога» — длинная серия громких сигналов.

---

## Я не доверяю китайским блокам питания S15W10E. Что делать?

Из личной практики — S15W10E работают стабильно и без нареканий. Но вы можете адаптировать проект под надёжные блоки питания **MEAN WELL RS-15-5** и **RS-15-12**, Вам потребуется изменить корпус внешнего блока, или разместить все в отсеке электроники принтера

---

## Я не доверяю SSR G3MB-202P. Что делать?

Используйте полноразмерное SSR реле 10DA/25DA/40DA/65DA — в корпусе flook32_external_da внешнего блока предусмотрена его установка.

---

## Зачем покупать термопару отдельно, если в комплекте с MAX6675 обычно идёт термопара?

Комплектная термопара короткая. Если её длины в вашем случае хватит — используйте её.

---

## У меня нет Wi-Fi. Как использовать устройство?

Никак 😄

На самом деле, вы можете добавить Ethernet-порт в проект — интернет в помощь.

[🔝 Наверх](#-faq--часто-задаваемые-вопросы)

---

[🔙 На главную](../README.md)

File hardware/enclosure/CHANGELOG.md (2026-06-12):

# История изменений моделей

Все значимые изменения в печатных моделях документируются здесь.

Формат основан на [Keep a Changelog](https://keepachangelog.com/ru/1.0.0/),
проект следует [Семантическому Версионированию](https://semver.org/lang/ru/).

## [2.0.0] – 2026-06-12

### Изменено (общее)
- Файлы `flook32_eternal_v1` заменены на `flook32_eternal_v2`
- Файл `flook32_external_v1` заменён на `flook32_external_g3mb_v2` и `flook32_external_da_v2`
- Старые версии (`_v1`) перемещены в папку `archive/`

### Удалено (flook32_eternal_v2)
- Магниты со всех сторон — осталось только верхнее магнитное крепление (подвес, 4 магнита ∅10×3 мм)

### Добавлено (flook32_eternal_v2)
- Перегородка между вентилятором и нагревателем для распределения потоков воздуха

### Изменено (flook32_eternal_v2)
- Значительное уменьшение расхода филамента: ≈100 г ABS
- Уменьшение габаритов по всем осям: 157×96×37 мм
- Утоньшение стенок: с 3 мм до 1,6 мм
- Утоньшение крышки: с 4 мм до 1,6 мм
- Крепление разъёма XH2.54 перенесено в горизонтальную плоскость
- Изменена левая стойка нагревателя — теперь удобнее прокладывать провода на другую сторону

---

### Добавлено (flook32_external_g3mb_v2)

#### Основные изменения
- Новая версия корпуса для SSR G3MB-202P (нагреватели до 200 Вт)
- Значительное изменение размеров 118x86x56 мм
- Уменьшение расхода филамента ≈125 г PETG
- Утоньшение стенок: с 3 мм до 1,6 мм
- Утоньшение крышки: с 3 мм до 1,6 мм

#### Контроллер
- Контроллер заменён с **ESP32D** на **ESP32 30-pin Type-C** (NodeMCU-32, ESP32-WROOM-32 и т.д)

#### Крепления компонентов
- ESP32 — на вплавляемые втулки ∅4,6×4 мм и 2 винта M3×5 DIN912 / DIN7985
- ESP01S + реле — на вплавляемые втулки ∅4,6×4 мм и 2 винта M3×5 DIN965 / DIN7991

#### Магниты
- Количество магнитов уменьшено с 6 до 4

#### Конструкция
- LED-лента повёрнута вверх для экономии места
- Корпус блоков питания встроен в основной корпус
- Два паза для WAGO 221-415 (без защёлок — фиксация на пару капель клея B7000)

#### Удалено
- Возможность использования шины под винт FS-506 — теперь только WAGO 221-415

---

### Добавлено (flook32_external_da_v2)

#### Основные изменения
- Новая версия корпуса для полноразмерных SSR серии DA: **SSR-10DA / 25DA / 40DA / 65DA** (нагреватели более 200 Вт, ток нагрузки до 30А)
- Основа взята от `flook32_external_g3mb_v2`
- Корпус увеличен в размере 151х86x56 мм для вертикальной установки SSR-DA
- Расход филамента ≈150 г PETG

#### Магниты
- Количество магнитов 5

#### Переключатель
- Переключатель заменён на **KCD4** (30А, 250В, посадочное отверстие 29.5×22.4 мм)
- Рассчитан на полную нагрузку SSR-65DA (до 30А)

#### Розетка и питание
- Удалена розетка C7
- Вместо неё используется кабель под вилку (прямой ввод) с фиксацией хомутом

---

## [1.0.0] – 2026-05-20

### Добавлено (flook32_eternal_v1)

#### Основные характеристики
- Первый публичный релиз
- Узкая конструкция: 168×99×41 мм
- Расход филамента: ≈200 г ABS

#### Магниты
- Возможность установки магнитов ∅10×3 мм со всех сторон

#### Нагреватель и вентилятор
- PTC нагреватель 95×31 мм
- Вентилятор 7530
- Крепление вентилятора на вплавляемые втулки ∅4,6×4 мм и винты M3×35 DIN965 / DIN7991
- Крепление нагревателя на вставляемые гайки М3
- Крепление нагревателя винтами M3×8 DIN912 / DIN7985

#### Крышка и корпус
- Крепление крышки на вплавляемые втулки ∅4,6×4 мм и винты M3×6 DIN965 / DIN7991
- Площадка для 5 см LED-ленты (подсветка логотипа)
- Пластинка-рассеиватель для подсветки логотипа

#### Отверстия и доступ
- Встроенный разъём XH2.54 для вентилятора
- Кабельный ввод под гофру
- Отверстия для проводов как справа, так и слева
- Заглушки для отверстий

---

### Добавлено (flook32_external_v1)

#### Основные характеристики
- Первый публичный релиз
- Размер основного корпуса: 158×110×67 мм
- Расход филамента: ≈250 г PETG
- Раздельные высоковольтный и низковольтный отсеки

#### Магниты и крепления
- Возможность установки магнитов ∅10×3 мм со дна

#### Отдельные корпуса для компонентов
- SSR G3MB-202P
- ESP01S + релейный модуль
- WAGO 221-415
- БП S15W10

#### Крепления компонентов
- ESP32D — через прижимную пластину, вплавляемые втулки ∅4,6×4 мм, винты M3×8 DIN912 / DIN7985
- Шина 220В — на вплавляемые втулки ∅4,6×4 мм и винты M3×8 DIN912 / DIN7985
- ESP01S + реле — на вплавляемые втулки ∅4,6×4 мм и винты M3×8 DIN912 / DIN7985
- SSR G3MB-202P — на защёлках
- SSR-10DA — на вплавляемые втулки ∅4,6×4 мм и винты M3×8 DIN912 / DIN7985
- БП S15W10E — на защёлках (в варианте с WAGO 221-415)
- БП S15W10E — на зажимах (в варианте с FS-506)
- Розетка C7 — на вплавляемые втулки ∅4,6×4 мм и винты M3×8 DIN912 / DIN7985

#### Крепления модулей (на пластину с зажимами)
- DS18B20
- MAX6675
- MOSFET LR7843
- Бипер KY-012

#### Крышка и корпус
- Крепление крышки — на вплавляемые втулки ∅4,6×4 мм и винты M3×5 DIN965 / DIN7991
- Площадка для 5 см LED-ленты WS2812B (индикация состояний)
- Площадка для тактовой кнопки 6×6×4,3 мм (сброс к заводским настройкам)
- Отверстия в крышке для тактовой кнопки (сброс к заводским настройкам)
- Тонкий пластик в виде трёх точек под светодиодную индикацию в крышке

#### Отверстия и доступ
- Отверстия в дне для доступа к кнопкам BOOT и EN (перевод ESP32 в режим прошивки)
- Отверстие в стенке для доступа к USB Type-C ESP32D
- Отверстия в перегородке между отсеками для проводов
- Кабельный ввод под гофру

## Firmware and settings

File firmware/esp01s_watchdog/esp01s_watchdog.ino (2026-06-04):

/**
 * ███████╗██╗      ██████╗   ██████╗ ██╗  ██╗ ██████╗ ██████╗
 * ██╔════╝██║     ██╔═══██╗ ██╔══██╗ ██║ ██╔╝ ╚════██╗╚════██╗
 * █████╗  ██║     ██║   ██║ ██║  ██║ █████╔╝   █████╔╝ █████╔╝
 * ██╔══╝  ██║     ██║   ██║ ██║  ██║ ██╔═██╗   ╚═══██╗██╔═══╝ 
 * ██║     ███████╗╚██████╔╝ ██████╔╝ ██║  ██╗ ██████╔╝███████╗
 * ╚═╝     ╚══════╝ ╚═════╝  ╚═════╝  ╚═╝  ╚═╝ ╚═════╝ ╚══════╝
 *                 ██╗    ██╗ █████╗ ████████╗ ██████╗██╗  ██╗██████╗  ██████╗  ██████╗ 
 *                 ██║    ██║██╔══██╗╚══██╔══╝██╔════╝██║  ██║██╔══██╗██╔═══██╗██╔════╝ 
 *                 ██║ █╗ ██║███████║   ██║   ██║     ███████║██║  ██║██║   ██║██║  ███╗
 *                 ██║███╗██║██╔══██║   ██║   ██║     ██╔══██║██║  ██║██║   ██║██║   ██║
 *                 ╚███╔███╔╝██║  ██║   ██║   ╚██████╗██║  ██║██████╔╝╚██████╔╝╚██████╔╝
 *                  ╚══╝╚══╝ ╚═╝  ╚═╝   ╚═╝    ╚═════╝╚═╝  ╚═╝╚═════╝  ╚═════╝  ╚═════╝ 
 * 
 * =====================================================================================
 *                            ESP-01S WATCHDOG v1.0.0
 *              АППАРАТНЫЙ СТОРОЖЕВОЙ ТАЙМЕР ДЛЯ ЗАЩИТЫ НАГРЕВАТЕЛЯ
 * =====================================================================================
 * 
 * АВТОР:          t.me/schreid
 * ПЛАТФОРМА:      Espressif ESP8266 (ESP-01S), Tensilica L106 32-bit, 80 МГц
 * СРЕДА:          Arduino Core for ESP8266 3.x
 * 
 * НАЗНАЧЕНИЕ:
 *   Автономный аппаратный сторожевой таймер для аварийного отключения
 *   питания 220В нагревателя при зависании или выходе из строя основного
 *   контроллера FLOOK32 (ESP32). Работает на отдельном микроконтроллере
 *   и не зависит от состояния основной прошивки.
 * 
 * 
 * ┌─────────────────────────────────────────────────────────────────────────────────┐
 * │                            ЛИЦЕНЗИЯ GPLv3                                       │
 * └─────────────────────────────────────────────────────────────────────────────────┘
 * 
 * Copyright (C) 2026 t.me/schreid
 * 
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
 * 
 * ┌─────────────────────────────────────────────────────────────────────────────────┐
 * │                              ПРИНЦИП РАБОТЫ                                     │
 * └─────────────────────────────────────────────────────────────────────────────────┘
 * 
 * FLOOK32 генерирует периодические импульсы (heartbeat) на пине GPIO26.
 * Эти импульсы поступают на GPIO2 ESP-01S.
 * 
 * Если импульсы присутствуют — ESP32 работает штатно, реле замкнуто,
 * питание 220В подаётся на нагреватель.
 * 
 * Если импульсы пропали на 6 секунд — ESP32 завис или вышел из строя,
 * реле размыкается, нагреватель обесточивается.
 * 
 * Требуется 3 последовательных импульса для включения реле — защита
 * от случайных помех и кратковременных наводок на линию.
 * 
 * При старте реле всегда выключено — безопасное состояние.
 * 
 * 
 * ┌─────────────────────────────────────────────────────────────────────────────────┐
 * │                         СХЕМА ПОДКЛЮЧЕНИЯ                                       │
 * └─────────────────────────────────────────────────────────────────────────────────┘
 * 
 * FLOOK32 (ESP32)                    ESP-01S (ESP8266)                Нагрузка
 * ┌──────────────┐                  ┌──────────────┐              ┌──────────┐
 * │              │                  │              │              │          │
 * │  GPIO26 ─────┼──────────────────┼  GPIO2       │              │  220V    │
 * │  (heartbeat) │   импульс каждые │  (вход)      │     NO  ─────┼──────────┤
 * │              │   1000 мс        │              │   (реле)     │          │
 * │              │                  │              │              │ Нагрева- │
 * │              │                  │              │              │ тель     │
 * └──────────────┘                  └──────────────┘              └──────────┘
 * 
 * =====================================================================================
 * Версия:     1.0.0
 * Сборка:     {__DATE__} {__TIME__}
 * Changelog:
 *   • Первый релиз
 *   • Детектирование heartbeat по прерыванию (RISING)
 *   • Защита от ложных срабатываний (3 импульса для включения)
 *   • Автоотключение через 6 секунд после потери сигнала
 *   • Программный watchdog ESP8266 для самовосстановления
 */

// ============================================================================
// ПИНЫ ESP-01S
// ============================================================================
// На модуле ESP-01S доступно всего 4 пина:
//   GPIO0 — используется как выход управления реле
//   GPIO2 — используется как вход heartbeat от FLOOK32
//   TX/RX — не используются (зарезервированы для прошивки)

#define HEARTBEAT_PIN 2         // Вход heartbeat сигнала от FLOOK32 (GPIO26 ESP32 → GPIO2 ESP-01S)
#define RELAY_PIN 0             // Выход управления реле (LOW = выкл, HIGH = вкл)

// Уровни управления реле
// Реле нормально-разомкнутое (NO): HIGH замыкает цепь 220В, LOW размыкает
#define RELAY_ON HIGH           // Высокий уровень = реле замкнуто = 220В подано
#define RELAY_OFF LOW           // Низкий уровень = реле разомкнуто = 220В отключено

// ============================================================================
// ТАЙМИНГИ (ОПРЕДЕЛЯЮТ ЧУВСТВИТЕЛЬНОСТЬ И БЕЗОПАСНОСТЬ)
// ============================================================================

// Время без сигнала heartbeat, после которого реле отключается (миллисекунды)
// Расчёт: FLOOK32 отправляет импульс каждые ~1000 мс (100 мс HIGH + 900 мс LOW) 
// 6 секунд = 6 пропущенных импульсов — гарантированное обнаружение зависания
const unsigned long SIGNAL_LOSS_TIMEOUT_MS = 6000;

// Максимальный интервал между соседними импульсами для продолжения серии (миллисекунды)
// Если прошло больше — считаем что серия прервалась и начинаем подсчёт заново
// 5 секунд = 5 полных периодов heartbeat с запасом на джиттер
const unsigned long PULSE_TIMEOUT_MS = 5000;

// ============================================================================
// ГЛОБАЛЬНЫЕ ПЕРЕМЕННЫЕ
// ============================================================================

// Флаг срабатывания прерывания (volatile — изменяется в ISR)
// Устанавливается в onPulse() при каждом фронте LOW→HIGH на пине heartbeat
volatile bool pulseFlag = false;

// Время последнего зафиксированного импульса (миллисекунды)
// Используется для расчёта интервалов и детектирования потери сигнала
unsigned long lastPulseTime = 0;

// Счётчик последовательных импульсов в текущей серии
// Сбрасывается в 0, если интервал между импульсами превысил PULSE_TIMEOUT_MS
// или если сигнал отсутствовал дольше SIGNAL_LOSS_TIMEOUT_MS
int consecutivePulses = 0;

// Текущее состояние реле (true = замкнуто = 220В подано)
// Используется для предотвращения повторных переключений реле
bool relayState = false;

// ============================================================================
// ОБРАБОТЧИК ПРЕРЫВАНИЯ (ISR — INTERRUPT SERVICE ROUTINE)
// ============================================================================

/**
 * Обработчик аппаратного прерывания по фронту RISING на пине HEARTBEAT_PIN.
 * 
 * ВАЖНО: ICACHE_RAM_ATTR размещает функцию в IRAM (оперативной памяти),
 * а не во flash. Это необходимо, потому что во время срабатывания прерывания
 * flash-память может быть занята другой операцией (запись/чтение), и обращение
 * к ней из ISR приведёт к сбою (крэш/перезагрузка ESP8266).
 * 
 * ISR выполняет минимальную работу: только устанавливает флаг pulseFlag.
 * Основная логика обработки вынесена в loop() для избежания длительных
 * операций в контексте прерывания.
 * 
 * Вызывается: автоматически при каждом фронте LOW→HIGH на HEARTBEAT_PIN
 */
ICACHE_RAM_ATTR void onPulse()
{
    pulseFlag = true;   // Устанавливаем флаг — loop() обработает его в основном цикле
}

// ============================================================================
// УПРАВЛЕНИЕ РЕЛЕ (БЕЗОПАСНОСТЬ ПИТАНИЯ 220В)
// ============================================================================

/**
 * Устанавливает состояние реле и запоминает его.
 * 
 * Параметры:
 *   - on: true = замкнуть реле (подать 220В), false = разомкнуть (отключить 220В)
 * 
 * Сохраняет состояние в relayState для предотвращения излишних переключений
 * (продлевает ресурс реле, исключает дребезг).
 * 
 * Вызывается: loop() при изменении условий (потеря/восстановление heartbeat)
 */
void setRelay(bool on)
{
    digitalWrite(RELAY_PIN, on ? RELAY_ON : RELAY_OFF);
    relayState = on;
}

// ============================================================================
// ИНИЦИАЛИЗАЦИЯ (ВЫПОЛНЯЕТСЯ ОДИН РАЗ ПРИ СТАРТЕ)
// ============================================================================

void setup()
{
    // ----- 1. НАСТРОЙКА ПИНА РЕЛЕ -----
    // Реле при старте ВСЕГДА выключено — безопасное состояние.
    // Даже если ESP-01S перезагрузился из-за собственного watchdog,
    // нагреватель не включится самопроизвольно.
    pinMode(RELAY_PIN, OUTPUT);
    digitalWrite(RELAY_PIN, RELAY_OFF);
    delay(200);                      // Задержка для стабилизации уровня на пине

    // ----- 2. НАСТРОЙКА ПИНА HEARTBEAT -----
    // Пин работает как вход без подтяжки — уровень определяется
    // исключительно сигналом от FLOOK32.
    pinMode(HEARTBEAT_PIN, INPUT);

    // ----- 3. ИНИЦИАЛИЗАЦИЯ ТАЙМЕРА -----
    // Устанавливаем время последнего импульса в текущее,
    // чтобы сразу после старта не сработал таймаут потери сигнала
    // (даём FLOOK32 время на отправку первого импульса).
    lastPulseTime = millis();

    // ----- 4. ПОДКЛЮЧЕНИЕ ПРЕРЫВАНИЯ -----
    // Прерывание по фронту RISING (LOW → HIGH) на пине HEARTBEAT_PIN.
    // Каждый импульс heartbeat от FLOOK32 (GPIO26) вызывает onPulse().
    // Используем digitalPinToInterrupt для совместимости с Arduino API.
    attachInterrupt(digitalPinToInterrupt(HEARTBEAT_PIN), onPulse, RISING);
}

// ============================================================================
// ОСНОВНОЙ ЦИКЛ (ВЫПОЛНЯЕТСЯ БЕСКОНЕЧНО)
// ============================================================================

void loop()
{
    // ----- 1. СБРОС ПРОГРАММНОГО WATCHDOG ESP8266 -----
    // ESP8266 имеет встроенный программный watchdog с таймаутом ~3.2 секунды.
    // Если не сбрасывать его — ESP-01S перезагрузится.
    // Это защита от зависания самого ESP-01S.
    ESP.wdtFeed();

    // Текущее время в миллисекундах с момента старта
    unsigned long now = millis();

    // ----- 2. ОБРАБОТКА ФЛАГА ПРЕРЫВАНИЯ -----
    // Если с момента прошлой проверки произошёл импульс heartbeat
    if (pulseFlag) {
        pulseFlag = false;   // Сбрасываем флаг для детектирования следующего импульса

        // Проверяем интервал с предыдущим импульсом:
        // - если меньше PULSE_TIMEOUT_MS (5 сек) — продолжаем серию
        // - если больше — начинаем новую серию (первый импульс)
        if (now - lastPulseTime < PULSE_TIMEOUT_MS) {
            consecutivePulses++;     // Импульс в пределах таймаута — увеличиваем счётчик
        } else {
            consecutivePulses = 1;   // Слишком большой интервал — начинаем новую серию
        }

        // Обновляем время последнего импульса для следующей проверки
        lastPulseTime = now;
    }

    // ----- 3. ПРОВЕРКА ПОТЕРИ СИГНАЛА -----
    // Если с последнего импульса прошло больше SIGNAL_LOSS_TIMEOUT_MS (6 сек),
    // считаем что FLOOK32 завис или выключен — сбрасываем счётчик импульсов.
    if (now - lastPulseTime > SIGNAL_LOSS_TIMEOUT_MS) {
        consecutivePulses = 0;
    }

    // ----- 4. ПРИНЯТИЕ РЕШЕНИЯ О РЕЛЕ -----
    // Реле включается только если накоплено 3 и более последовательных импульса.
    // Это защита от:
    //   - Случайных помех и наводок на линию
    //   - Кратковременных всплесков при включении/выключении FLOOK32
    //   - Дребезга контактов
    bool shouldRelayOn = (consecutivePulses >= 3);

    // ----- 5. ПЕРЕКЛЮЧЕНИЕ РЕЛЕ ПРИ ИЗМЕНЕНИИ СОСТОЯНИЯ -----
    // setRelay() проверяет, изменилось ли состояние, и переключает реле
    // только если нужно. Это предотвращает лишние циклы переключения
    // и продлевает ресурс электромеханического реле.
    if (shouldRelayOn != relayState) {
        setRelay(shouldRelayOn);
    }

    // ----- 6. ЗАДЕРЖКА ДЛЯ СТАБИЛЬНОСТИ -----
    // Минимальная задержка 20 мс:
    //   - Достаточно для обнаружения импульсов heartbeat (период ~1000 мс)
    //   - Не нагружает процессор (50 итераций в секунду)
    //   - Позволяет ESP8266 обрабатывать WiFi при необходимости
    delay(20);
}

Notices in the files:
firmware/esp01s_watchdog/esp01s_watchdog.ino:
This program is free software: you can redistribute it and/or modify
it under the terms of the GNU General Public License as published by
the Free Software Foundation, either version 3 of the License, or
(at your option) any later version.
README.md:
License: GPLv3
